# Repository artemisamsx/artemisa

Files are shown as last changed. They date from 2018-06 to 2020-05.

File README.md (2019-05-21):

# Artemisa MSX Computer System

This repository contains documentation and designs for a MSX computer that can be build using discrete components and original integrated circuits, codenamed Artemisa.

This is still work in progress, but you may find some specs and designs in this repository.

## Documentation

* [Artemisa User Manual](doc/user-manual/000-index.md).
* [Artemisa Service Manual](doc/service-manual/000-index.md).

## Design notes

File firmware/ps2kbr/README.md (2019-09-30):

# PS2 Keyboard Adapter Firmware

## Requirements

- A XGecu TL866II+ universal programmer.
- A UNIX-like operating system. It might work in Windows, but that's not tested.

## Dependencies

- Install [arduino-cli](https://github.com/arduino/arduino-cli), the Arduino command line utility to build sketches. You will find install instructions in the project page. At the time of this writing, it was not ported to Homebrew yet, but it was WIP.
- Install [minipro](https://gitlab.com/DavidGriffith/minipro) programming tool. You will have to install from sources (instructions in the project README).
- Install [srecord](http://srecord.sourceforge.net/), a tool to handle ROM images. You can install it with `brew install srecord`.

## Build

There is a Makefile available in this directory. We will start by configuring the toolchain:

```bash
make config
```

This will configure the Arduino CLI and will download the Arduino Uno environment if not done yet.

After this is completed, we can compile with:

```bash
make compile
```

This will generate a `ps2kbr.bin` file that contains the firmware image ready to be flashed in a ATMEGA328P.

## Burn

Put an ATMEGA328P chip in the programmer and let the Makefile do the magic:

```bash
make burn
```

If there are no errors, this will leave the 328 programmed with PS2 Keyboard Adapter firmware.

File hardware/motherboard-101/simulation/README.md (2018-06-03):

The simulation code found here can be executed using the Falstad web simulator:

http://www.falstad.com/circuit/circuitjs.html

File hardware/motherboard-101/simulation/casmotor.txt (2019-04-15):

$ 1 0.000005 8.281975887399955 50 5 50
t 832 352 880 352 0 1 -4.9998037623649285 3.464993523704525e-10 100
g 880 368 880 400 0
r 880 208 880 272 0 160
d 880 272 880 336 2 default-led
R 880 208 880 176 0 0 40 5 0 0 0.5
r 752 352 832 352 0 3300
R 752 352 704 352 0 2 40 2.5 2.5 0 0.5
o 3 64 0 4097 5 0.1 0 2 3 3
o 6 64 3 4098 5 0.1 1 1
o 5 64 0 4097 5 0.00625 2 2 5 3

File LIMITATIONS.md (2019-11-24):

# Artemisa Computer System - Known Limitations

## System

### Game still executes after reset

Artemisa uses static RAM memory technology instead of dynamic RAM. Dynamic RAM was the norm during the 80s due to the expensive cost of static memories. But nowadays are the best option due to the current cost and the fact that they make the memory circuits smaller and simpler.

The main difference between static and dynamic RAM is that the volatility of the former do not depend upong refreshing. Dynamic RAM is based on capacitors whose load determines a logic 0 or 1 value. Capacitors are discharged with the time, and they must be refreshed, charged again to its maximum level with some periodicity. In contrast, static RAM maintains its state as long as power is supplied.

This has a important implication. During a system reset triggered by a reset button press, the reset signal typically stops the refresh actions on the dynamic memory. The human typically would keep the reset button pressed for more than 100ms. That is too much time for the dynamic memory to maintain its bits intact without refresh, and they are typically lost. In other words, this is somehow a memory reset action. In contrast, static memories are not affected by reset signals. And their contents remain intact after system is reset.

Most of the times, you will not even notice it. The MSX system assumes the memory is blank on boot. So the system will init as after power is connected. But from time to time, you will see how the previous software that was running in the computer is runned again. This is caused by that software to be placed in a region of memory the MSX BIOS detects as executable. After reset the program is still there. So the BIOS passes its control to it and causes its code to be executed again.

A well known case of this is the Opera Soft's game Livingstone Supongo. The program is loaded in a memory page such that it contains a header that causes the BIOS to run it again after reset.

There is no simple way to clean up static memories after reset without using complex circuits. If you have this problem, the best thing to do is to cause a hard reset by disconnecting the power and connecting it again.

## PS2 Keyboard

The unexpensive way of using a keyboard in your Artemisa computer is through the PS2 Keyboard Adapter. However, it presents some limitations you should know.

### Key ghosting

Key ghosting is the adverse effect caused by pressing three keys or more simultaneously in your keyboard. When this happens, the keyboard matrix is unable to detect the third key that was pressed. The reason is perfectly described [in this article](https://www.dribin.org/dave/keyboard/one_html/).

During regular keyboard typing, you should not experience any problem. The keyboard matrices use to take into account that the function keys will be used together. So CTRL, ALT, SHIFT, etc, can be combined together with other keys without any problem. However, when keyboard is used as game controller, you will need to press several non-function keys at the same time. This is where problems arise.

Most PC keyboards are very sensible to key ghosting. And there is no solution other than use a different set of keys when you detect ghosting.

A [very well known](https://forum.defold.com/t/spacebar-doesnt-work-when-pressing-up-and-left-solved/12642/3) conflicting combination is `UP` + `LEFT` + `SPACE`. If this happens, you can define keys in your game to use OPQA or WASD instead.

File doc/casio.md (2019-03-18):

## Cassette Input & Output

As most MSX systems, Artemisa provides a interface to load and save programs and data from an audio cassette. Data is backed up at 1200 or 2400 baud with Frequency Shift Keying (FSK) in the standard "Kansas City" format.

The cassette device is connected to the MSX through a 8-pin DIN connector (DIN 45326) with the following pinout:

| Pin | Name | Direction | Description |
| --- | --- | ---- | --- |
| 1 | GND | | Ground |
| 2 | GND | | Ground |
| 3 | GND | | Ground |
| 4 | CMTOUT | | Sound output |
| 5 | CMTIN  | | Sound input |
| 6 | REM+ | | Remote control |
| 7 | REM- | | Remote control |
| 8 | GND | | Ground |

In summary, pins 4 and 5 carry the sound output and input, respectivelly. Pins 6 and 7 are used to start and stop the cassette motor. They are barely used in practice and Artemisa do not use them (these pins are grounded). The rest of pins are connected to ground.

There are two different circuits in Artemisa to generate cassette input and outputs: one that decodes `CMTIN` and another one that encodes `CMTOUT`.

## Cassette Input Decoding

The audio cassette will send an analog signal to the computer with a form of sinusoidal wave through `CMTIN`. The decoding circuit is based on a LM311 part, a voltage comparator, in order to convert the input wave into a 5V squared signal.

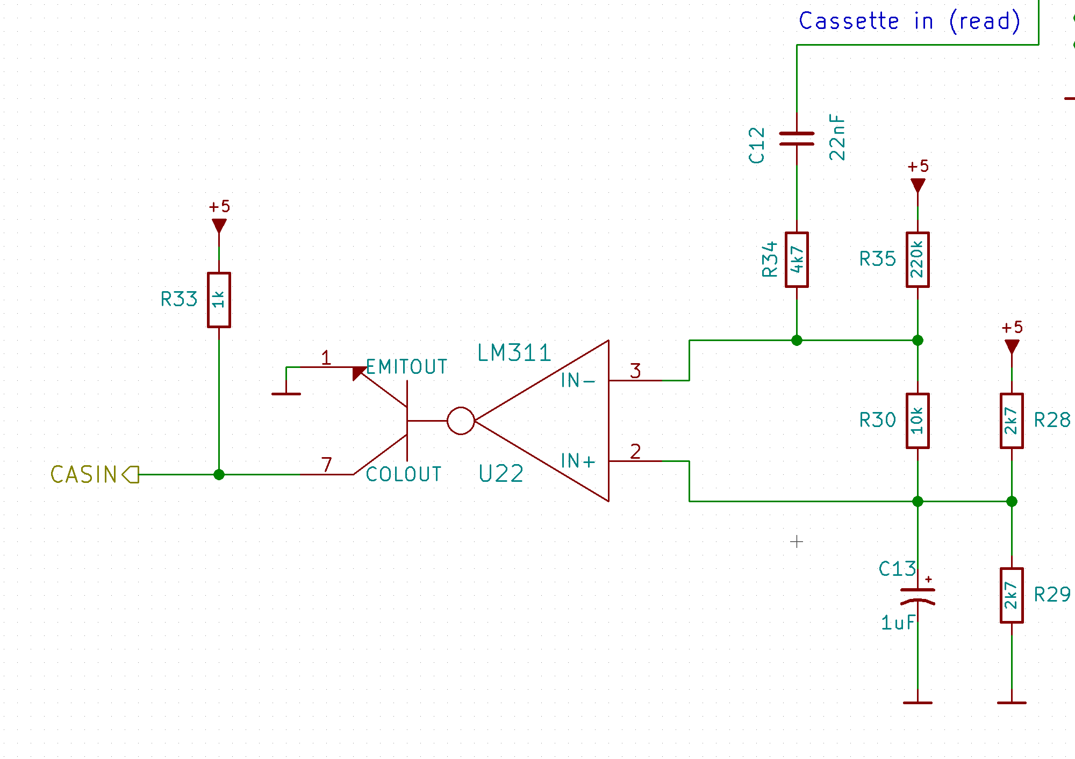
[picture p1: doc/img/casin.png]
casin


What LM311 does is basically open or close its open-collector output based on the voltage levels of `IN+` and `IN-` pads. If `IN+` voltage is greater than `IN-` voltage, the output transistor will not conduct. Thus, thanks to the pull-up resistor R33, the output will be 5V. If `IN+` voltage is less than `IN-` voltage, the output transistor conducts. Thus, the output will be 0 volts sin emiter is connected to ground.

In order to achieve that, the circuit have the following [voltage dividers](https://en.wikipedia.org/wiki/Voltage_divider):
* One made by `R28` and `R29` that feed `IN+`. Both resistors have the same value, so the input to `IN+` is approximately 2.5 volts. 
* One made by `R30` and `R35` on top of `IN+`, that feed `IN-`. The combination of both resistors gives approximately 2.61 volts in `IN-`. 

Since the values of resistors in `IN-` are really large, we might expect to have a very low current coming from `IN+` (<50uA). So `IN+` maintains its voltage intact. `C13` also contributes to counter act the voltage drop from `IN-`, maintaining the potential at 2.5 volts. 

In abscense of voltage coming from `CMTIN`, this circuit will ensure the voltage in `IN-` is slightly greater than `IN+`. Thus, when we receive no signal from the cassette, the digital output will be low. We would read zeroes. 

When a voltage comes from `CMTIN`, it passes through `C12` and `R34`. The capacitor removes the DC offset, and the resistor reduces the amplitude of the waveform. This is especially needed for data recorders that generate signals that exceed the 5 volts peer-to-peek (some do). The analogic signal is combined with the DC value provided by the voltage divider in `IN-`. As result, the low part of the pulse will be below 2.5v barrier. And high part of the pulse will be above it. Thus, the LM311 will generate a squared waveform in `CASIN` that matches the frequency of `CMTIN` line.

## Cassette Output Encoding

The audio cassette will expect an analog signal from the computer with a form of sinusoidal wave through `CMTOUT`. The encoding is implemented by the following RC circuit.

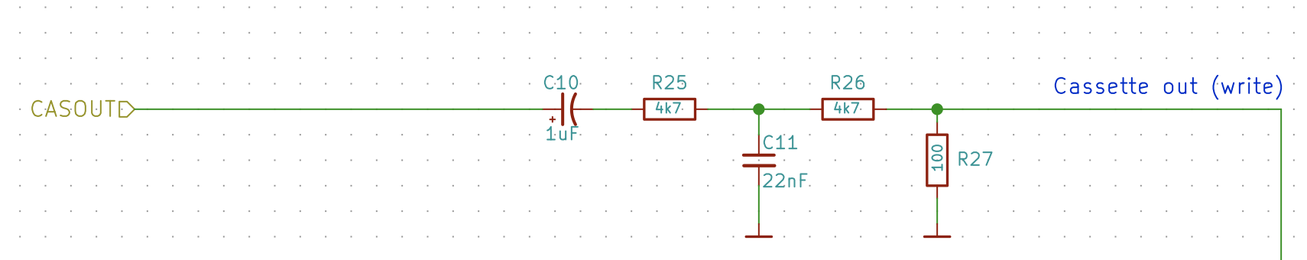
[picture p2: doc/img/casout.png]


The capacitor C10 removes the DC bias from the output signal. The circuit formed by R25 and C11 implements a [RC integrator](https://www.electronics-tutorials.ws/rc/rc-integrator.html) that causes the input squared signal to acquire a pseudo-sinusoidal waveform. Finally, the combination of R26 and R27 acts as a voltage divider that reduces the amplitude of the signal

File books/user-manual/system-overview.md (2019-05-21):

# Artemisa Computer System User Manual - System Overview

## The System

Artemisa is a 8-bits computer powered by a Z80 microprocessor running at 3.58Mhz. This CPU was designed by Zilog in the 70's, as a binary compatible extension of the popular Intel 8080. The Z80 was also used in many other computers and videogame consoles during the 80's, as the ZX Spectrum, the Amstrad CPC, the Coleco Vision or the Sega Master System.

Artemisa is equipped with 64KB of RAM memory. It can be used by programs to store their code, data, and graphics. It also provides 32KB of ROM memory where MSX BIOS and MSX BASIC resides. The MSX BIOS is a collection of software routines used by programmers to make their programs interact with the hardware. The MSX BASIC is a programming language and user environment you can use to code programs and give commands to the computer.

As any other MSX system, there are two major chips that complete the system along the Z80: the VDP and the PSG.

The VDP is the Video Display Processor, an integrated circuit capable of generating a video output for your screen. There were different revisions of the VDP across different generations of MSX. First designs started with a [TMS9918](https://en.wikipedia.org/wiki/Texas_Instruments_TMS9918), a VDP that was already used in Coleco Vision, Sega SG-1000 and some other home computers as the SVI-328. This chip can generate graphics with 256x192 pixels and 16 colors, with hardware-accelarated sprites to make animated graphics. The TMS9918 has a video output limited to NTSC composite video, with synchronization, luminance and crominance all together in a single line. This limitation led the second wave of MSX computers to use the TMS9928 and TMS9929 instead. These VDPs have the same functionality as TMS9918, but they had a component video output that separates the chrominance from the luminance. Thanks to that, the designers can manipulate the video signals to generate the outputs that better fit their needs (composite video, radio-frequence modulation for TV sets, RGB, etc). In addition, the TMS9929 uses PAL encoding instead of NTSC, so they became the right option in most european countries.

Depending on your TV set or monitor, you will have different needs. NTSC vs PAL, composite vs RGB, SCART vs RCA connectors... This customization is really important for the users. That's why Artemisa is designed to support every single option for every single user. This is achieved by separating the VDP and its circuitry from the rest of the computer in a graphics card. This card is connected to the computer mainboard by a ribbon cable. Thus, users can purshase their Artemisa computer by choosing the graphics card that better fits their needs.

Along the VDP, any MSX has a PSG. The PSG is the Programmable Sound Generator, a chip that can generate and play sound and music. Artemisa is equipped with the [AY-3-8910A](https://es.wikipedia.org/wiki/General_Instrument_AY-3-8910). This PSG is also present in the ZX Spectrum and the Amstrad CPC computers. It capable to reproduce 3 different tones with base frequencies of up to 125 kHz.

Using this chip set, and some other circuitry, Artemisa supports several peripherals common in the MSX world.

- A keyboard port that supports keyboards with up to 96 keys.
- Two joystick ports compatible with MSX/Coleco/SEGA devices.
- One datassete port to load or save software from a magnetic tape data storage.
- Two expansion slots to connect cartridges with software or new hardware to expand the computer.

If you are a experienced MSX users, you should know there is a few things you may find in a MSX computer that are not present in Artemisa:

- Printer port. We expect you to do many things with your Artemisa computer. But printing documents is not one of them.
- Serial port. Same reason as for the printer port.
- +12V and -12V power lines. Complicates the design and introduces additional security concerns. Any hardware (cartridge) that depends upon this will not work.

## System Parts

After this introduction to the overall system, you have a high level idea of what you can get from Artemisa. Now it is time to tell you about the different parts that comprise an Artemisa system.

Artemisa is designed to fit your needs as much as possible. There are two parts of the system that are more sensible to customization than the rest:

- The video system. We already discussed a little bit about this. In Artemisa, the VDP and related circuits are separated from the rest of the computer into a separated graphics card. And the graphics card must be connected to an external monitor or a TV. The right option depends on the computer setup you want. See [Graphics card](#graphics-card) section for more details.

- The keyboard. Artemisa is designed to be used with an external keyboard specially designed for it. There are different options for these keyboards depending on the grade of experience you want to obtain and the cost you can afford. See [Keyboard](#keyboard) section for more details.

So in summary, in order to have a full Artemisa computer system, you will need the following parts:

- One Artemisa system base. This includes the motherboard of the computer, the case, the power supply, the cables, the screws and the spacers needed to assemble the computer.
- An Artemisa-compatible keyboard or a keyboard adapter with a suitable external keyboard.
- An Artemisa-compatible graphics card with a suitable external monitor or TV set.

## Graphics card

The graphics card is connected to the mainboard via IDC ports on both boards. A ribbon cable connects the ports. The graphics card is designed to be mounted beside the motherboard, so this internal connection is perfect for the job.

The graphics card port has 50 pins, and it have a pinout similar to those used in the MSX slots. This means the graphics card can behave like a MSX cartridge, mapping its hardware in arbitrary IO ports, or even memory space of the Z80. One of the particularities of this port is that the sound line is "reversed". Instead of connecting a external sound device to the computer, it takes the sound line from the computer to consume it. Thanks to that, the graphics card can produce its own video signal and combine it with the sound signal produced by the computer coming from the motherboard. This might be used to offer outputs that combine video and sound, as SCART connectors.

The following graphics cards are available:

- GFX9918. This is the most basic graphic card available for Artemisa. It is powered by the TMS9918 chip, the first video processor used in a MSX computer. This board generates a NTSC composite video output at 60Hz combined with the sound line via RCA connectors (classic yellow, white and red triad). It includes 16KB of video RAM (VRAM) using static memory.

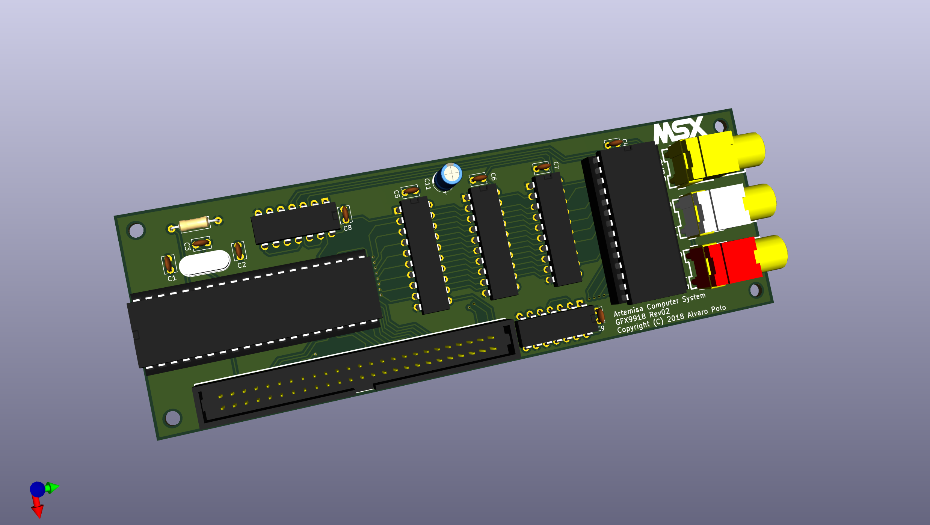
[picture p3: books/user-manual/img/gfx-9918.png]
gfx-9918


- GFX992X (under development). This is an evolution of GFX9918. It uses a TMS9928 or a TMS9929 chip, for NTSC or PAL encoding, respectively. This card has the same graphical features as the GFX9918, but it generates a component video output (YPbPr) instead of composite video. In a few words, the crominance is separated from the luminance in the 9928/9929 chips, what provides a major improvement in the video quality. You can use one chip or the other using the same board, depending on the system used by your TV set or monitor (NTSC or PAL). The board encodes the component video signals to produce RGB+sync. All these outputs plus the sound signal are offered as a female SCART connector you can connect to your TV set via a standard cable.

## Keyboard

Artemisa provides a DB25 connector (classic parallel port, but with custom pinout) in its motherboard to connect an Artemisa compatible keyboard peripheral. This keyboard port basically sends row coordinates of the keyboard matrix to be read, and receives back the status of each column for that row in the matrix. You have different options in order to connect a real keyboard to the computer:

- Use the Artemisa PS2 Keyboard Adapter. This is a separated device that can be connected to the Artemisa keyboard port. It adapts a regular PS2 keyboard and exposes it to Artemisa as a regular keyboard. A unexpensive and simple option, but will affect your user experience negatively since you will have to use a keyboard with a PC key distribution.

- Use the Artemisa USB Keyboard adapter (under development). The same as PS2 adapter, but for USB keyboards.

- Use an Artemisa keyboard (under development). Use a mechanical keyboard designed specifically to be connected to an Artemisa computer, with a real MSX key distribution. For real pro users.

## Case

Artemisa motherboard is distributed with a very simple case comprised by two acrylic plates where motherboard and graphics card can be mounted. The lower plate is opaque white, and it has several holes to screw spacers where the boards stands on. The upper plate is transparent. So you can enjoy looking at the circuits of your favorite MSX computer every time you use it. The upper plate also has special cuts for the cartridge connectors.

## Power supply

The motherboard provides a 2.5/5.5mm DC power jack to connect a 5V, 2A external power supply. As mentioned above, no +12V/-12V power lines are used in Artemisa.

## Next

Now you have a clear general idea about what's Artemisa. Let's see how you can [assemble it from its parts](030-assembly.md).

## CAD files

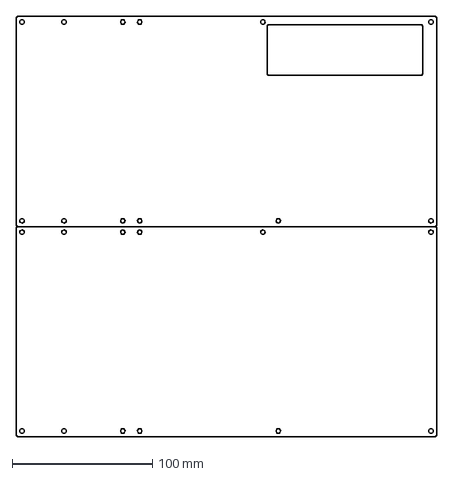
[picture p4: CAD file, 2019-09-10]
cases/motherboard/motherboard.dxf
300.0 x 300.0 mm

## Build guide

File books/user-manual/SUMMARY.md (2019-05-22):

# Summary

* [Introduction](README.md)
* [System Overview](system-overview.md)
* [Assembly](assembly.md)

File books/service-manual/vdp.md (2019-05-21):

# Artemisa MSX Computer System Service Manual - Video Display Processor

Artemisa is designed to allow a variety of different VDPs to be used with it. In order to have this, the VDP circuitry is completely separated from the rest of the computer. So customers can choose the graphics card that better fits their needs.

## Interface

The interface used to communicate the Artemisa computer motherboard and the graphics card is basically a modification of a de facto standard for a expansion bus:

  https://www.msx.org/wiki/Expansion_bus_slots

Artemisa considers the following modifications to the specs described in above link:

* The line 16, which is reserved according to the standard, will be used to transmit the `/VDPIOSEL` signal. This will be active by the computer when IO ports 98h to 9Fh are selected with /IORQ active and /M1 inactive (i.e., a IO request to the VDP ports).
* The line 49, which is `SOUNDIN` according to the standard, will be used to transmit the `SOUNDOUT` signal. In other words, the direction of the line changes. Originally, it goes from the external device to the computer. In Artemisa, it goes from the computer to the external device (the GFX card). The reason to do so is to delegate the sound output connectors to the graphics card. Most GFX card implementation will have video outputs suitable for TV sets. And they typically are accompanied by sound outputs (e.g., RCA connectors for CVBS+sound, SCART connectors, etc). Thanks to `SOUNDOUT`, the video card can provide such video+sound outputs without any external cable.
* As usual in Artemisa, +12v and -12v power signals are disconnected.

Thanks to that, the graphics card can use a great variety of possible IO, and even memory, communications. From the simplest graphic card with a TMS9918 VDP mapped in ports 98h and 99h, to the most sophisticated combination of V9990 chips.

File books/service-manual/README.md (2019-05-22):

# Artemisa Computer System - Service Manual

This is the service manual of the Artemisa Computer System. This manual is for technical stuff to understand how the Artemisa Computer work internally so they can repair it if necessary.

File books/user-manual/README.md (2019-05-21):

# Artemisa Computer System User Manual - Introduction

> "640K ought to be enough for anybody"
>
> Bill Gates, 1981

Welcome to the early days of home computing.

Let me propose you a journey to the 80s of past century. During this decade, the computing industry experienced a big revolution. The lessons learned during the 70s speak about a future in which computers domain everything. A future in which computers are everywhere. Including our homes.

In these days, many companies developed home computers. This is the age of the Spectrum ZX, the Commodore 64, the Amstrad CPC, and of course the big family of MSX. Small machines, with really limited capacity and resources, found their place in many homes when we were just childs. We learned to play videogames with these first computers. We learned to code with them. We learned their potential. Their power to change the modern economies, to transform the society. And we learned all that was just the begining.

Again, welcome to the early days of home computing. Welcome to Artemisa.

## What is Artemisa

Artemisa is a 8-bits computer system that conforms the [MSX-1 specification](https://en.wikipedia.org/wiki/MSX). There were many hardware vendors who produced MSX computers in the 80s. Sony, Canon, Casio, Sharp, Spectravideo, Panasonic, Philips... Artemisa is just another member of this big family, with some particularities:

1) Artemisa was designed in 2018. That's 35 years after the initial design of the first MSX computers.
2) There are some other MSX computers designed in 21st century. But this is one of the few that do not use hardware emulation. Other brands as 1chipMSX or Zemmix use FPGAs to emulate the MSX hardware. In constract, Artemisa use real integrated circuits and discrete logic. In other words, it is made using the same design techniques and materials used in the 80s, when the first MSX computers were also designed. Please note this does not mean Artemisa is better (or worse) than its FPGA-based counterparts. It just mean it is special.

## Audience

Artemisa captures the essence of the homebrew computers of late 70's and early 80's. Do not expect to find a plug&play computer you can connect to your TV set just out of the box. It is distributed in highly customizable parts you will have to assemble by your own (no electronics knowledge is required). Artemisa is a homebrew computer aimed at homebrew consumers.

## Author

Artemisa is designed and implemented by Alvaro Polo. It was created just for fun and delight of its author. Thus, it is offered to the MSX community as a open source project you may find at http://github.com/apoloval/artemisa.

## Next

Let's start your experience with Artemisa by having a look to the [system overview](020-system-overview.md).

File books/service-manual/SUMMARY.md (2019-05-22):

# Summary

- [Video Display Processor](vdp.md)
- [Cassette Input & Output](casio.md)

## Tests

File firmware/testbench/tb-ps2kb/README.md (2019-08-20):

# PS2 Keyboard Adapter Testbench

This testbench can be used to test PS2 Keyboard Adapter boards.

You will need an Arduino Mega/2560 board.

## Arduino Mega pinout

- Pin 2 (out): /VDPSEL (pin 16 of IDC connector)
- Pin 3 (out): /WR (pin 13 of IDC connector)
- Pin 4 (out): /RD (pin 14 of IDC connector)
- Pin 5 (in): /IRQ (pin 8 of IDC connector)
- Pin 6 (out): /RESET (pin 15 of IDC connector)
- Pin 7 (out): A0 (pin 28 of IDC connector)
- Pin A0 (out): D0 (pin 34 of IDC connector)
- Pin A1 (out): D1 (pin 33 of IDC connector)
- Pin A2 (out): D2 (pin 36 of IDC connector)
- Pin A3 (out): D3 (pin 35 of IDC connector)
- Pin A4 (out): D4 (pin 38 of IDC connector)
- Pin A5 (out): D5 (pin 37 of IDC connector)
- Pin 12 (out): D6 (pin 40 of IDC connector)
- Pin 13 (out): D7 (pin 39 of IDC connector)

## How to test the board

Connect the keyboard to the adapter board and wire everything according to the pinout above.

Power up, reset the Arduino, and open the serial monitor in your Arduino IDE. Everything you type in the PS2 keyboard should be seen in the console.

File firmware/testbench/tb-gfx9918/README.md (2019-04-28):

# GFX9918 Testbench

This testbench can be used to test GFX9918 boards.

You will need an Arduino Uno or an Arduino Mega 2560 board or similar to drive the test. The code is written to consider different pinouts for each board.

## Arduino Uno pinout

- Pin 2 (out): /VDPSEL (pin 16 of IDC connector)
- Pin 3 (out): /WR (pin 13 of IDC connector)
- Pin 4 (out): /RD (pin 14 of IDC connector)
- Pin 5 (in): /IRQ (pin 8 of IDC connector)
- Pin 6 (out): /RESET (pin 15 of IDC connector)
- Pin 7 (out): A0 (pin 28 of IDC connector)
- Pin A0 (out): D0 (pin 34 of IDC connector)
- Pin A1 (out): D1 (pin 33 of IDC connector)
- Pin A2 (out): D2 (pin 36 of IDC connector)
- Pin A3 (out): D3 (pin 35 of IDC connector)
- Pin A4 (out): D4 (pin 38 of IDC connector)
- Pin A5 (out): D5 (pin 37 of IDC connector)
- Pin 12 (out): D6 (pin 40 of IDC connector)
- Pin 13 (out): D7 (pin 39 of IDC connector)

## Arduino Mega pinout

- Pin 2 (out): /VDPSEL (pin 16 of IDC connector)
- Pin 3 (out): /WR (pin 13 of IDC connector)
- Pin 4 (out): /RD (pin 14 of IDC connector)
- Pin 5 (in): /IRQ (pin 8 of IDC connector)
- Pin 6 (out): /RESET (pin 15 of IDC connector)
- Pin 7 (out): A0 (pin 28 of IDC connector)
- Pin 22 (out): D0 (pin 34 of IDC connector)
- Pin 23 (out): D1 (pin 33 of IDC connector)
- Pin 24 (out): D2 (pin 36 of IDC connector)
- Pin 25 (out): D3 (pin 35 of IDC connector)
- Pin 26 (out): D4 (pin 38 of IDC connector)
- Pin 27 (out): D5 (pin 37 of IDC connector)
- Pin 28 (out): D6 (pin 40 of IDC connector)
- Pin 29 (out): D7 (pin 39 of IDC connector)

## How to test the board

Connect the wires, including +5V and GND power lines and RCA connectors to a external monitor.

Power up, reset the Arduino, and you must see a message in the screen similar to the welcome any regular MSX1 gives.

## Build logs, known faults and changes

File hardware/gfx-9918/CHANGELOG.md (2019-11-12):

# Artemisa GFX9918 Changelog

## Rev 4

- Fix via sizes to conform JLCPCB design rules
- Fix background color issues by unconnecting EXTVDP pin

## Rev 3

- VCC power traces improved

## Rev 2

- Fix inverted pads of RCA connectors

## Rev 1

First revision of the board

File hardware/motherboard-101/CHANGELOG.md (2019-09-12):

# Artemisa Motherboard Mk.I Changelog

## Rev 3

- Replace 74HCT11 by 74HCT32
- Replace 74HC154 by a pair of 74HC138
- Fix via sizes to conform JLCPCB design rules
- Make the right PCB corners rounded

## Rev 2

- Replace power-on reset circuit to make it work
- Fix wrong orientation of slot connectors
- Fix wrong placement of keyboard and joystick connectors
- Move slot connectors to make room to the case screws
- VCC power traces improved

## Rev 1

First revision of the board

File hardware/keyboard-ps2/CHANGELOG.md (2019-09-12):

# Artemisa PS2 Keyboard Adapter Changelog

## Rev3 (Unreleased)

- Fix via sizes to conform JLCPCB design rules
- Fix wrong dimensions of cartridge slot connectors
- Fix wrong annular ring size of cartridge slot connectors
- Make corners rounded

## Rev2

- Fixed some layout issues found in Rev1.
- VCC power traces improved respect Rev1.
- Added a pair of jumpers to configure keyboard layout.

## Rev1

First revision of the board.

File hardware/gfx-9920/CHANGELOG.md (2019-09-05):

# Artemisa GFX9918 Changelog

## Rev 4 (Unreleased)

- Fix via sizes to conform JLCPCB design rules

## Rev 3

- VCC power traces improved

## Rev 2

- Fix inverted pads of RCA connectors

## Rev 1

First revision of the board

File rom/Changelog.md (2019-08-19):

# Artemisa ROM image changelog

## Version 20190816

Initial version of the ROM image.

### Contents

- `$00000` [jumper conf `0000`]: MSX System v1.0 International
- `$08000` [jumper conf `0001`]: MSX System v1.0 USA
- `$10000` [jumper conf `0010`]: MSX System v1.0 Japan
- `$18000` [jumper conf `0011`]: MSX System v1.0 UK
- `$20000` [jumper conf `0100`]: MSX System v1.0 France
- `$28000` [jumper conf `0101`]: MSX System v1.0 Germany
- `$30000` [jumper conf `0110`]: MSX System v1.0 Italy
- `$38000` [jumper conf `0111`]: MSX System v1.0 Spain
- `$40000` [jumper conf `1000`]: MSX System v1.0 Arabic
- `$48000` [jumper conf `1001`]: MSX System v1.0 Korea
- `$50000` [jumper conf `1010`]: MSX System v1.0 Russia
- `$58000` [jumper conf `1011`]: Artemisa Diagnosis Tool 0.1

### MSX-System flags

```asm
OPTM    EQU     0
NDEVFIX EQU     1
SLOTFIX EQU     0
```

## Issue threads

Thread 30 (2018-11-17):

Test: cassette input signal

apoloval, 2018-11-17:
Mount the following schematic in a protoboard and test whether expected digital signal is successfully detected using a logic analyzer.

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

apoloval, 2018-12-27:
Parts received: unblocked.

apoloval, 2018-12-27:
Bingo! Original circuit, with a operative LM311.

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

apoloval, 2018-12-27:
Note: 470K is too much for R35. That resistor have to raise the medium voltage of the input signal above reference voltage in IN+. As consequence, any minor noise in the line causes the LM311 to detect a drop below Vref, and a digital 1 to be output. A value of 220K raises the voltage a little bit more, and works perfectly. Noise doesn't affect then.

apoloval, 2018-12-27:
Note: 10K is too much for R34. That resistor reduces the amplitude of the input signal. For data recorders, it's fine since they produce a signal of 5Vp-p. But, for regular cassettes (or PC outputs), that's too much since reduces the signal to 784mVp-p at max volume. Using a resistor of 4.7K gives a greater amplitude of 1.13Vp-p. Considering R35 is raising the voltage with some margin, a small amplitude could cause the squared output to be non-symmetrical. To avoid that, R34 could be set to 4.7K instead of 10K.

apoloval, 2018-12-27:
The simplified circuit works fine. But the following amendments are needed:
* R35 is needed to raise the voltage over Vref, so the noise doesn't affect the output as stated in previous note. And its recommended value is 220K.
* R34 is needed in order to reduce the amplitude of input signal. Its recommended value is 4.7K.

That's the input for #40.

Closed 2018-12-27.

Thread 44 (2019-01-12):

Order prototype PCBs for GFX9918 Rev1

apoloval, 2019-01-12:
It's time for rock!

BOM:
- [x] 1x TMS9918
- [x] 1x HM62256ALP-10
- [x] 1x 74HCT04
- [x] 3x 74HCT574
- [x] 1x 74HC32
- [x] 1x Crystal 10.7386Mhz
- [x] 2x Disc capacitor 27pF
- [x] 7x Disc capacitor 100nF
- [x] 1x Radial capacitor 10uF
- [x] 1x Axial resistor 470
- [x] 1x Socket DIP 40 600"
- [x] 1x Socket DIP 28 600
- [x] 1x RCA yellow
- [x] 1x RCA white
- [x] 1x RCA red
- [x] 1x IDC 50p PCB connector male
- [x] 2x IDC 50p ribbon cable female connector
- [x] 1x IDC 50p ribbon cable 5cm

apoloval, 2019-01-12:
PCB printing ordered. Waiting for audit.

apoloval, 2019-01-26:
Socket DIP 28P received.

apoloval, 2019-01-28:
IDC 50p PCB connector male received.
PCBs received.

Closed 2019-01-28.

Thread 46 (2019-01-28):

Test prototype PCBs for GFX9918 Rev1

apoloval, 2019-01-28:
After #44, it's time to test.

apoloval, 2019-03-26:
This is a summary of the experiment carried out.

After soldering the PCB and mounting the components, we realised the RCA footprints were wrong. The pinout was totally inverted, so GND was connected to data, and data to GND. This is reported in #47 .

Apart from this issue, the video quality was really poor. There were some color artifacts and the pixels were not sharply defined.

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

I tested many things to improve it:
- Play with different values for COMVID load resistor
- Try with a emitter follower transistor for COMVID to have almost 0 input impedance.
- Use different combinations of capacitors for VDP clock.
- Use an extra variadic capacitor for VDP clock and adjust it with direct feedback from the screen.
- Replace the crystal by a high-quality one purchased in Mouser

None of that worked. This is the best it can do:

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

I am quite sure the color artifacts are caused by the NTSC encoding in composite video. So there is not much to do here until we find some magic word I cannot find at the moment.

Thus, the experiment is done. Let's produce some units of Rev02 with fixes for detected problems.

Closed 2019-03-26.

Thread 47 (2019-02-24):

[GFX9918] Fix RCA connectors

apoloval, 2019-02-24:
Two major issues of RCA connectors:
- The fingerprint does not match. Even though is possible to solder them, the holes are not in the exact position. Also the holes to fit the capsule are missing.
- The poles are inverted. GND is the central pad, while signal is connected to the left and right ones.

apoloval, 2019-03-24:
Done in d29e0b05a0e1033f2b270c5372d9d8eea220e53c.

Closed 2019-03-24.

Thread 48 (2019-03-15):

CD4069 transits too slowly for clock generation

apoloval, 2019-03-15:
Checking the [datasheet](http://www.ti.com/lit/ds/symlink/cd4069ub.pdf) after some experiments with crystals above 10Mhz, it is clear that the transition of this NOR gate is too slow. 100ns @ 5 volts. This is causing the clock signal to be rounded instead of squared.

It would be great to find some other unbuffered NOR gate that transits quicker and use it for the clock generation.

apoloval, 2019-03-15:
A possible replacement: [TC74HC14AF](https://www.mouser.es/datasheet/2/408/TC74HC14AF_datasheet_en_20120229-1209204.pdf).

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

apoloval, 2019-03-15:
Also have to check [74HC14 Smitt trigger inverter](https://assets.nexperia.com/documents/data-sheet/74HC_HCT14.pdf).

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

apoloval, 2019-03-15:
But in fact, [this StackOverflow thread](https://electronics.stackexchange.com/a/218150) recommends not to use Schmitt trigger inverters for crystal oscillators.

apoloval, 2019-03-15:
The [74HCU04](https://assets.nexperia.com/documents/data-sheet/74HCU04.pdf) also has interesting transition time.

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

apoloval, 2019-03-15:
Just purchased some 74HCU04 to experiment with.

apoloval, 2019-03-25:
Before, with CD4069.

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

After, with 74HCU04.

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

Conclusion: CD4069 must be replaced by 74HCU04.

apoloval, 2019-04-03:
Fixed in 64c3f9b0da03c3a95eb850b6e3c43d8d6e63d2d5.

Closed 2019-04-03.

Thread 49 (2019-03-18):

Rearrange cassette IO circuit to clarify voltage dividers intention

apoloval, 2019-03-18:

apoloval, 2019-03-18:
Fixed in 44e2b9909c577aa055cc3f79d4e5b08cf2b6bd91.

Closed 2019-03-18.

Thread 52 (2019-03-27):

[GFX9918] Produce batch #1 of GFX9918 Rev2

apoloval, 2019-03-27:
After #46, we are ready to produce the first batch of GFX9918.

We will start with 5 units.

Pre-production
- [x] Ensure the PCB is updated and revision number is set
- [x] Generate the Gerber files and submit an order to the factory

Ensure stock of BOM:
- [x] 1x TMS9918
- [x] 1x HM62256ALP-10
- [x] 1x 74HCT04
- [x] 3x 74HCT574
- [x] 1x 74HC32
- [x] 1x Crystal 10.7386Mhz
- [x] 2x Disc capacitor 27pF
- [x] 7x Disc capacitor 100nF
- [x] 1x Radial capacitor 10uF
- [x] 1x Axial resistor 470
- [x] 1x Socket DIP 40 600"
- [x] 1x Socket DIP 28 600
- [x] 1x RCA yellow
- [x] 1x RCA white
- [x] 1x RCA red
- [x] 1x IDC 50p PCB connector male

Post-production
- [x] Prepare kits
- [ ] Assemble and solder the components
- [ ] Test the units using an Arduino board

apoloval, 2019-04-09:
GFX9918 Rev2 [released](https://github.com/apoloval/artemisa/releases/tag/gfx9918-rev2)!

apoloval, 2019-04-09:
Order submitted to the manufacturer. Waiting for audit.

apoloval, 2019-04-09:
Audit passed and payment done. Waiting for manufacturing.

apoloval, 2019-04-30:
Boards arrived yesterday. Ready to soldering and packaging!

apoloval, 2019-05-01:
Kits prepared. Issues:
- 74HCT574: no stocks. 20 units ordered
- 74HCT04: low on stocks. 20 units ordered.
- 27pf ceramic capacitor: low on stocks. 100 units ordered.
- 100nF ceramic capacitor: low on stocks. 500 units ordered.
- 10uF electrolytic capacitor: low on stocks. 60 units ordered.

apoloval, 2019-05-10:
Waiting for 74HC574 to complete the batch. Also for some ESD bags and protection bags that fit better in the box.

apoloval, 2019-10-15:
Already done.

Closed 2019-10-15.

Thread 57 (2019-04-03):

Add a LED for cassette motor status

apoloval, 2019-04-03:
We are not gonna implement the classical relay circuit for cassette motor present in most MSX systems. But a LED that indicates whether the motor is on or not would be really useful.

Please note the LED might not be driven directly from the PPI. The max current could be exceeded. We have to check if the PPI current is enough for a LED (~50mA) and, if not, we should use a transistor switch instead.

apoloval, 2019-04-15:
According to the [datasheet](https://www.renesas.com/eu/en/www/doc/datasheet/82c55a.pdf), max current drive is 2.5mA. This is far from the typical forward current of a LED. We definitely need ty drive it with something else.

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

apoloval, 2019-04-15:
We could use a [ULN2003 IC](https://www.st.com/resource/en/datasheet/uln2004.pdf). This is an array of darlington transistors that can drive 500mA, enough for any LED. But this means adding a new IC to the datasheet. And I'm not sure there is room for it in the PCB.

apoloval, 2019-04-15:
Or more simpler approach: use a voltage follower transistor circuit as this picture shows:

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

apoloval, 2019-04-15:
Done in f77edac23a06cb14b3df45df6b1258b57b6f9d2a by adding a common emitter NPN transistor. According to the simulations, this will drain 1.31mA from the 8255 for a forward current of 19.26mA in the LED.

Closed 2019-04-15.

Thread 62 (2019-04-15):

Extract keyboard matrix emulation out from motherboard

apoloval, 2019-04-15:
The current design assumes the keyboard matrix of the MSX will be emulated by a ATmega328 microcontroller connected to a real PS2 keyboard. The controller would read commands from they PS2 keyboard and would translate them into changes over a keyboard matrix maintained by a network of 595 serial-to-parallel shift registers.

This is fine, and it works. However, having this logic hardcoded into the motherboard means the computer will be forced to use this kind of interface to the keyboard. No custom keyboard will be allowed, as no other interface like USB. This is too rigid.

After a long deliberation, we have decided to move this circuit out from the motherboard. Instead, a DB25 connector expecting a keyboard matrix will be placed. At the other end of the connector, we might have a PS2 adapter, a USB adapter, or just an Artemisa custom mechanic keyboard. We want it as flexible as possible.

Said so. We have to move the keyboard emulation circuit into a separated KiCAD project as we did for the GFX9918 board. We will leave the KBROW decoder, the pull-up resistor network, and we will put a DB25 connector for the rest.

Some proposal for the DB25 connector layout:

- P1 to P8: keyboard column input
- P9 to P19: keyboard row output
- P20: /CAPSLOCK output
- P21: /KANALOCK signal
- P22: /RESET signal
- P23: +5v power supply
- P24 and P25: GND

apoloval, 2019-04-28:
Done in e139e7f3d94a4c002f572750e99f7a35a109f391.

What we did is to extract the matrix emulation circuit to an external board. Also, the whole mainboard of Artemisa was rearranged.

Closed 2019-04-28.

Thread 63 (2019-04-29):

Order prototype PCBs for PS2 Keyboard Adapter Rev1

apoloval, 2019-04-29:
BOM:

- [x] 1x ATmega 328P
- [x] 11x 74HC595
- [x] 1x Crystal 16Mhz
- [x] 2x Disc capacitor 22pF
- [x] 12x Disc capacitor 100nF
- [x] 1x Radial capacitor 10uF
- [x] 1x Socket DIP 28 300"
- [x] 1x PS2 PCB connector
- [x] 1x DB25 PCB female connector

apoloval, 2019-04-29:
PCB printing ordered. Waiting for audit.

apoloval, 2019-05-07:
I forgot to arrange the payment. Just done.

apoloval, 2019-05-20:
PCBs arrived. Pending to check materials stock and assemble the first prototype.

apoloval, 2019-05-26:
Prototype assembled successfully. Now it's time for testing.

Closed 2019-05-26.

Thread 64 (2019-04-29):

Order prototype PCBs for Mainboard Rev1

apoloval, 2019-04-29:
BOM:
- Capacitors
  - [x] 27x Ceramic capacitor 100nF
  - [x] 1x Electrolytic capacitor 100uF
  - [x] 4x Electrolytic capacitor 10uF
  - [x] 3x Ceramic capacitor 22pF
  - [x] 3x Electrolytic capacitor 1uF
  - [x] 2x Ceramic capacitor 22nF
  - [x] 1x Green LED 5mm
  - [x] 1x Red LED 5mm
- Connectors
  - [x] 1x Jack 55x21
  - [x] 1x DB25 male
  - [x] 2x MSX Slot connectors
  - [x] 1x IDC female connector
  - [x] 2x DB9 connectors
  - [x] 1x DIN8 female connector
- Transistors
  - [x] 1x 2N2222 transistor
- Resistors
  - [x] 1x 100Ω resistor
  - [x] 1x 160Ω resistor
  - [x] 1x 220Ω resistor
  - [x] 1x 470Ω resistor
  - [x] 2x 1KΩ resistor
  - [x] 3x 2K7Ω resistor
  - [x] 1x 3K3Ω resistor
  - [x] 4x 4K7Ω resistor
  - [x] 4x 10KΩ resistor
  - [x] 1x 20KΩ resistor
  - [x] 1x 220KΩ resistor
  - [x] 1x 1MΩ resistor
  - [x] 1x 10KΩ resistor network 5p
  - [x] 1x 10KΩ resistor network 7p
  - [x] 2x 10KΩ resistor network 9p
- Integrated circuits
  - [x] 2x HM62256ALP-10
  - [x] 3x 74HCT244
  - [x] 1x Z84C00
  - [x] 2x 74HC74
  - [x] 1x 74HCT245
  - [x] 1x 74HCU04
  - [x] 1x 74HC04
  - [x] 3x 74HC32
  - [x] 1x 74HC08
  - [x] 1x 74HC139
  - [x] 1x 74HC07
  - [x] 1x 74HCT11
  - [x] 1x LM311
  - [x] 1x SST39SF0
  - [x] 1x 74HC154
  - [x] 2x 74HC157
  - [x] 1x AY-3-8910
  - [x] 1x 74HC138
  - [x] 1x 74HC153
  - [x] 1x 82C55
- Sockets
  - [x] 2x DIP 28P .600
  - [x] 1x DIP 32P .600
  - [x] 3x DIP 40P .600
- Oscillators
  - [x] 1x 3.58Mhz crystal

apoloval, 2019-04-29:
Let's do #65 before this.

apoloval, 2019-05-07:
Plotted in 095d7926f36ba0363069efae63f216715b98fdeb.

apoloval, 2019-05-07:
Gerber package [released](https://github.com/apoloval/artemisa/releases/tag/artemisa-mk1-rev01).

apoloval, 2019-05-07:
Order submitted. Pending for audit.

apoloval, 2019-05-07:
Audit completed. Payment done. Waiting for production.

apoloval, 2019-05-08:
In best case, using 5 PCBs would mean we will be low of stock of the following items:
- 62256, 9 units ordered
- 74HCT244, 20 units ordered
- 74HC74, 30 units ordered
- 74HCT245, 10 units ordered
- 74HC04, 30 units ordered
- 74HC32, 30 units ordered
- 74HC08, 30 units ordered
- 74HC139, 20 units ordered
- 74HC07, 10 units ordered
- 74HC157, 20 units ordered
- 82C55, 20 units ordered
- 39SF040, 15 units ordered

apoloval, 2019-05-20:
PCBs arrived. Pending to check the BOM and start the debugging.

apoloval, 2019-06-06:
BOM checked. We have stock of everything, at least to assemble a prototype and test on it.

Closed 2019-06-06.

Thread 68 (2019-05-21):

DB25 connector does not stands out enough

apoloval, 2019-05-21:
The first prototypes arrived reveal the DB25 connectors are not standing out enough. So they could not be connected together without a cable. We must shorten the PCBs so their endings float in the air.

apoloval, 2019-05-22:
It is not only the DB25, but also the DB9. Fixing both.

apoloval, 2019-05-22:
Fixed in a4ac9f86f90f58ec4a69e3df5021acfb54128c00.

Closed 2019-05-22.

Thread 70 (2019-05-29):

Use a jumper to indicate JIS vs ANSI keyboard layout

apoloval, 2019-05-29:
As documented [here](http://map.grauw.nl/articles/keymatrix.php):

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

The register 14 of the PSG corresponds to the IO port A. So the bit 6 is the pin `IOA6` in this schematic:

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

In order to give the opportunity to the users to configure the japanese layout of their keyboards, we should drive this line from the keyboard. We will use the pin 25 of the keyboard connector to transmit the JP layout (1=JIS, 0=ANSI).

The following changes are required:
- [ ] In motherboard, drive the pin 25 from keyboard to the `IOA6` pin of the PSG.
- [ ] In PS2 Adapter, introduce a jumper so the user can select one layout or the other.

apoloval, 2019-05-29:
Another alternative could be to let the keyboard itself to report the kind of keyboard by its own. The pins 24 and 25 of the keyboard connector are GND. Perhaps we could use just one of them for GND and dedicate the other one for transmitting the JIS vs ANSI signal to the computer.

I have to deliberate about this.

apoloval, 2019-05-30:
Yes, I think moving the line to the keyboard makes all the sense. Rewriting the issue...

apoloval, 2019-05-30:
I still have doubts. A quick look to Amazon JP reveals all modern keyboards are JIS, and ANSI is not used anymore. And according to the [docs]:

> It seems the most common computers use JIS, the turboR computers for example, but there are also quite a few which use ANSI.

Perhaps the best choice is to support JIS exclusively. And wire the PSG pin to +5V with a pull-up resistor.

Again, I have to deliberate about it.

apoloval, 2019-06-06:
Yes, I've been searching more and more modern Japanese keyboards. And none of them use ANSI layout. It's much better to consider JIS keyboards only and forget about this issue.

However, we have to wire the PSG pin to 5v+. Reported in #79.

Closed 2019-06-06.

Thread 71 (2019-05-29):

Honour kana lock signal to the keyboard

apoloval, 2019-05-29:
## Description

The pin 21 of the keyboard connector (DB25) is used to transmit the Kana lock signal from the computer to the keyboard. This indicates whether the Kana layer of the keyboard is activated or not. It works in a similar way as the caps lock, but for kana symbols.

In current design, the pin 21 is wired to +5v. It means Kana is never activated.

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

The MSX computer typically [signals the kana lock by bit 7 port IO port B of the PSG](https://www.msx.org/wiki/Joystick_control)(register 15). If we want to honor the kana lock signal managed by the BIOS, we should connect this signal to the keyboard connector instead of pulling it down to ground.

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

## Tasks

- [x] In motherboard, connect the PSG pin to the keyboard connector pin.
- [x] In PS2 keyboard adapter, modify the firmware to use some keyboard LED (as scroll lock) as Kana LED.

apoloval, 2019-07-04:
Fixed for Motherboard in 20e3cf451c80afeeb66313df8c459bb8e607d5ea.

apoloval, 2019-08-20:
Fixed for PS2 adapter in 9ed3c495390dbf08e1394b104af5212bc6b87482.

Closed 2019-08-20.

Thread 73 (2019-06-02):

Motherboard tests: power on, reset and clock generator

apoloval, 2019-06-02:
## Scenarios

- [x] **Power on**
GIVEN barrel DC power circuit is wired
WHEN power is on
THEN the power LED lights up
  AND THEN the ammeter is below 50mA
- [x] **Reset signal**
GIVEN power, reset and clock generator circuits are connected
WHEN power is on
THEN the `/RESET` signal is `LOW`
  AND `RESET` signal is `HIGH`
WHEN ~9ms passes
THEN the `/RESET` signal is `HIGH`
  AND `RESET` signal is `LOW`
- [x] **Clock generator**
GIVEN power, reset and clock generator circuits are connected
WHEN power is on
THEN the oscilloscope reveals the `CLOCK` signal is a squared clock signal at 3.58Mhz

## Connections

- Following barrel DC power circuit is wired

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

- Following reset circuit is wired

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

- Following clock generation circuit is wired (except U17, the flip-flop used to generate `PSGCLK`).

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

apoloval, 2019-06-03:
Issue: C5 and C38 legends overlap.

apoloval, 2019-06-03:
Power on test passed. 0.00 amperes.

apoloval, 2019-06-04:
Reset signal test passed. We expected 9ms as of results from simulation. We obtained ~14ms instead. But it is a good value also. So this is a success.

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

apoloval, 2019-06-04:
Clock generator test passed. Expected frequency and waveform properties are okay.

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

apoloval, 2019-06-04:
All tests in this suite pass. Hurray!

apoloval, 2019-06-05:
Just for the record. I had to assemble a new board, and I used 74HCU04N from Philips instead of 74HCU04AP from Toshiba. With Philips, reset signal period is 9.6ms.

Closed 2019-06-04.

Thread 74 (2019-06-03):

Motherboard tests: PSG clock and PPI ready signal

apoloval, 2019-06-03:
# Scenarios

- [x] **PSG clock generation**
GIVEN power is on
WHEN power is stabilized
THEN the oscilloscope reveals the `PSGCLK` signal is a squared clock signal at 1.79Mhz
- [x] **PPI Ready signal**
GIVEN power is on AND `/PPISL` is HIGH
WHEN power is stabilized
THEN the `/PPIRDY` signal is HIGH
AND WHEN `/PPISL` signal is LOW
THEN the `/PPIRDY` signal is LOW
AND WHEN `/PPISL` signal is HIGH
THEN the `/PPIRDY` signal is LOW

# Connections

- Those coming from test suite #73.
- PSG clock generation circuit is wired

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

- PPI ready circuit is wired. The `/PPISL` signal will not be connected to the PCB, but to a breadboard where we can control its state (LOW or HIGH) using a pull-up resistor and a switch.

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

apoloval, 2019-06-06:
**PSG clock generation** passed:

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

apoloval, 2019-06-06:
**PPI Ready signal** passed.

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

apoloval, 2019-06-06:
Test suite successfully completed.

Closed 2019-06-06.

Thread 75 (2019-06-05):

Motherboard tests: IO port select decoding

apoloval, 2019-06-05:
# Description

Main operation of `U25` binary decoder, used to generate the selection signals for some ranges of IO ports.

# Scenarios

- [x] **No IO operation**
GIVEN `/IORQ` is 1 AND `/M1` is 1 AND `ADDR` is `0b00000xxx`
THEN `/VDPSL` is 1 AND `/PSGSL` is 1 AND `/PPISL` is 1

- [x] **IO operation on unknown port**
GIVEN `/IORQ` is 1 AND `/M1` is 1 AND `ADDR` is `0b00000xxx`
WHEN `/IORQ` is 0 AND `ADDR` is `0b00011xxx`
THEN `/VDPSL` is 1 AND `/PSGSL` is 1 AND `/PPISL` is 1

- [x] **IO operation on VDP port**
GIVEN `/IORQ` is 1 AND `/M1` is 1 AND  `ADDR` is `0b00000xxx`
WHEN `/IORQ` is 0 AND address is `0b10011xxx`
THEN `/VDPSL` is 0 AND `/PSGSL` is 1 AND `/PPISL` is 1

- [x] **Interrupt vector read from VDP port**
GIVEN `/IORQ` is 1 AND `/M1` is 1 AND  `ADDR` is `0b00000xxx`
WHEN `/IORQ` is 0 AND `/M1` is 0 AND address is `0b10011xxx`
THEN `/VDPSL` is 1 AND `/PSGSL` is 1 AND `/PPISL` is 1

# Connections

- Those from the test suite described in #74.
- Connect `U3`, `U4`, and `U5`, the HCT buffers that decouple the CPU signals from the actual buses.
- Connect `U25`, the binary decoder that generates the select signals for IO devices.
- Connect pin 4 to ground or +5V depending on the scenario, which is an equivalent of `ADDR` starting with `10xxxxxx`  or not, respectively.
- Wire address bits as indicated by each scenario. Please note _xxx_ at the end means bits 2, 1 and 0 do not care, and don't need to be wired.
- Wire `/IORQ` selected by scenario
- Wire `/M1` selected by scenario
- Wire any other line from address and control buses to ground and +5v, respectively. This is to avoid floating lines in the buffer ICs.

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

apoloval, 2019-06-07:
**No IO operation** test passed. All control signals to HIGH, all address signals to LOW. IO device selection signals are HIGH.

apoloval, 2019-06-07:
** IO operation on unknown port** test passed.

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

apoloval, 2019-06-07:
**IO operation on VDP port** test passed.

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

apoloval, 2019-06-07:
**Interrupt vector read from VDP port** test passed.

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

apoloval, 2019-06-07:
All tests in this suite passed successfully!

Closed 2019-06-07.

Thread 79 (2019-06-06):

Hardcode JP keyboard layout to JIS

apoloval, 2019-06-06:
## Description

After some analysis in #70, we realised we should be indicating JIS instead of ANSI keyboard in the corresponding PSG port.

## Tasks

- [x] In motherboard, connect PSG pin 15 (`IOA6`) to +5v instead of GND with a pull-up resistor to prevent short-circuits when port is configured as output.

apoloval, 2019-06-20:
Done in 865a480cfd3aad1954f6b8d5e4498aaef9aacdad.

Closed 2019-06-20.

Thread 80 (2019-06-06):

Use custom width for power traces

apoloval, 2019-06-06:
## Description

In Motherboard, we had the caution to assign a custom width for those traces that carry +5v and GND. We should do that same for the rest of PCBs.

## Tasks

- [x] In GFX9918, use custom width for power traces
- [x] In PS2 Keyboard Adapter, use custom width for power traces

apoloval, 2019-07-15:
Fixed for GFX9918 after 142a41fa6ee4c904e553b72c345d422d74134ae1.

apoloval, 2019-07-16:
And fixed for PS2 Keyboard adapter after 8221cb4d2ef67537b6dcd0d4402c6cdf45fbcce8.

Closed 2019-07-16.

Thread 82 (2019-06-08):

Motherboard test: basic CPU operation

apoloval, 2019-06-08:
## Description

Connect the CPU and the ROM memory, and execute a infinite noop loop. The PPI will be hacked to select slot 0 only.

## Scenarios

- **CPU executes the program**
GIVEN ROM memory is burned with [noop loop program](https://github.com/apoloval/artemisa/blob/master/rom/nooploop/nooploop.asm)
WHEN `/M1` is active low
THEN the PC is present in the address bus
WHEN `/MREQ` AND `/RD` are active low
THEN `/WAIT` signal is activated another clock cycle
WHEN `/WAIT` signal is inactive high
THEN data bus contains the instruction
  AND `/MREQ` is inactive high
  AND `/RD` is inactive high
  AND `/M1` is inactive high

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

## Connections

- Those from test #75
- All ICs from Decoding Logic sheet: U10, U11, U12, U13, U14 and U15.
- U7, the flip-flip that generates the `/WAIT` signal.

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

- U8, the bidirectional buffer for data bus.

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

- U18, the AND gate that generates the `/EXTWAIT` and `/EXTINT` signals.

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

- RN2, the resistor network that pull-ups the external wait and interrupt signals.
- Connect pins 2 and 3 of U15 to GND. This would hardcode the slot to 0.

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

- Socket for U20 (ROM).
- Decoupling capacitors for U20 (ROM) and U6 (CPU).

apoloval, 2019-06-08:
Soldering parts...

apoloval, 2019-06-09:
Parts soldered. Also, the infinite noop loop program was added in 0e8eb735c65cd72c24444343997153c5c32e4e0f. Now I have a ROM chip with that program installed. Let's rock...

apoloval, 2019-06-09:
Important record. The `/RESET` signal is not long enough. The ~9ms are not enough for the ICs to be powered up. When reset is deactivated, the clock is still erratic, and some other ICs are still sending glitched values.

I tried to add another 1uF capacitor in paralell to C7, duplicating the capacitance. With that, we are duplicating also the time of the `/RESET` signal. This seems to be enough to stabilize the voltage for all ICs. However, I would use 10uF instead so we are totally sure we are powering it all without surprises.

Reported in #83

apoloval, 2019-06-09:
The results are somehow odd, and need further investigation.

- We start with unusual M1 cycle. I reads from address 0, but `/MREQ` and `/RD` signals are raised too early, in the middle of the second cycle. And the `/WAIT` signal generated for it is ignored.

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

- Then we have what seems to be first fetch of the first instruction. A M1 cycle , again on address 0, that extends to the third clock cycle. This is a `DI` instruction.

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

- Then we have another expected M1 cycle, for address 1, instruction `NOP`.

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

- And finally the last instruction fetch, address 2, a `JR -1`. This doesn't look fine, since the instruction argument is read twice.
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

apoloval, 2019-06-09:
Ups! There was something wrong in the circuit. I forgot to connect pins 2 and 3 of U15 to ground. After fixing that, the first instruction looks fine. A1 to A2 is fetch, B1 to B2 is decoding and execution. 4 cycles for the DI instruction plus 1 wait cycle. Exactly what I expected.

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

Then the execution of the `NOP` at address $0001. Again, as expected. 4 cycles plus one more for the wait in M1.

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

And finally the `JR -1` at address $0002. It has 12 cycles plus one wait, as expected. But still we have two additional read operations from memory instead of the expected single one.

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

apoloval, 2019-06-09:
According to Z80 docs, JR has three M cycles.

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

IO cycle means Internal Operation. And for some reason, it is reading again the operand from memory.

apoloval, 2019-06-09:
Anyway. The program is running apparently without issues, apart from the reset signal problem reported above. The odd initial M1 cycle might be due to a [Z80 special reset](http://www.primrosebank.net/computers/z80/z80_special_reset.htm) that will not affect us since our memory must be volatile. And the double read in `JR e` instruction looks like some internal implementation detail.

I think we can consider this test as complete! Horay!

Closed 2019-06-09.

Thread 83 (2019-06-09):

C7 must be 10uF instead of 1uF in Motherboard

apoloval, 2019-06-09:
The `/RESET` signal is not long enough. The ~9ms are not enough for the ICs to be powered up. When reset is deactivated, the clock is still erratic, and some other ICs are still sending glitched values.

I tried to add another 1uF capacitor in paralell to C7, duplicating the capacitance. With that, we are duplicating also the time of the `/RESET` signal. This seems to be enough to stabilize the voltage for all ICs. However, I would use 10uF instead so we are totally sure we are powering it all without surprises.

apoloval, 2019-06-11:
Just for the record. According to the simulations with Falstad, these are the reset times for each value of C7:

- For 1uF, 50 milliseconds
- For 10uF, 70 milliseconds
- For 47uF, 325 milliseconds

Perhaps 47uF is a better value than 10uF.

apoloval, 2019-06-13:
The whole reset circuit is wrong. This is superseded by #85 .

Closed 2019-06-13.

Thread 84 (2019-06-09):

Motherboard test: exec first stage of Artemisa Diagnosis Tool

apoloval, 2019-06-09:
## Description

Make the CPU execute the first stage of Artemisa Diagnosis Tool. This is the stage in which the VDP is configured in text mode and we are able to show things in the screen. This is actually the setup before executing any diagnosis, which require the PPI to be operative, and we did not assembled it yet.

## Scenarios

- The VDP can be initialized in text mode and we can show messages in the screen.
GIVEN a reduced set of ADT in the ROM AND GFX9918 is connected in video card port
WHEN power is on
THEN the welcome message of ADT can be seen in the screen

## Connections

- Those from #82
- Video card connector is soldered
- Ribbon cable connects the Motherboard with a GFX9918 card via video card connector
- Still pins 2 and 3 of U15 are connected to GND to always select slot 0 on any memory access.

apoloval, 2019-06-10:
Unfortunately, the tests is not successful. Just connecting the items, nothing is seen in the screen. We will have to debug this.

apoloval, 2019-06-11:
Oh, it just was a silly mistake. I forgot to erase the flash memory before burning the ROM image. I fix this and... IT WORKS!

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

But there are some issues. It not works on every boot. Most of them use to fail. Some with a black screen. Some others with unexpected symbols.

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

I suspected again of the `/RESET` signal, so I made an experiment placing a 47uF capacitor in the reset circuit in parallel with the 11uF we already had. No lock. Same behavior. About 33% of the boots succeeds, but the rest 66% fails.

I have to investigate a little more. This is a behaviour we already had with the Arduino testbench. On power-on, the board use to fail. We have to pulse the reset button of the Arduino board to reset everything, and then the VDP works without any problem. [Looking at the code](https://github.com/apoloval/artemisa/blob/master/firmware/testbench/gfx9918/gfx9918.ino#L108-L112) we were using a reset signal of 200uS. That works when power is on before reset, but it is absolutely useless when the board has to be powered up and +5V level must reach every IC, which takes many milliseconds.

apoloval, 2019-06-11:
There is one thing I don't like. After some analysis, I detected the `/RESET` signal is not stable. When it is raising up, the logic analyzer detects level fluctuations. That means the last reset pulse may be too quick, and the VDP gets into an inconsistent state.

One possible reason could be that we are using a 74HCU04, unbuffered inverter. A regular 74HC04 may fix the issue, or even a schmitt triggered one.

apoloval, 2019-06-11:
Tried different options. Different values for C8, make C8 a feedback circuit back to pin 1 of the inverter... Some of them reduce the glitches, but do not eliminate them.

The best option so far is a 74HC14. It eliminates the glitches completely.

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

apoloval, 2019-06-12:
I think I've found the reason for the glitches.

This is the voltage and current curves of the 74HCU04.

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

As with any other CMOS integrated circuit, the consumed current is significantly increased during voltage level switches. So we power on. The capacitor gets loaded slowly until its voltage reaches around 1 volt. At this point, the level switch begins. The output level goes down, and the input starts to consume much more current than before (up to 18mA). This current is pulled from the input... where we have the capacitor. Since there is a 10K resistor between the input and +5v, this current is drained from... the capacitor! So this causes a voltage drop in the capacitor, and therefore in the input. So the level switch is interrupted, or at least reseted to a previous point. More current from the power source loads the capacitor a little more, and we start again. This repeats in a loop, it's an oscillation. And in each iteration we raise the voltage a little bit more. When we are around the high level voltage, we enter and exit from it many many times.

This is something that also happens for 74HC04. The level switch is much faster in this buffered gate, but the current drain increase is the same.

apoloval, 2019-06-12:
I think this reset circuit might work. Have to test it:

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

apoloval, 2019-06-13:
The glitches are deduced drastically with the design above. But they are still present.

However, I tried with this one, which is the one used by the Philips VG8020. It works perfectly. Not a single glitch.

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

But I don't understand yet why.

apoloval, 2019-06-13:
The 4.7k resistor from NPN base to ground is the key. If you remove it, everything is lost. I think it has to do with the region of operation of the transistor. Without this resistor, base current is too high and operates in a sub-optimal region.

apoloval, 2019-06-13:
NICE! I soldered the above circuit in the PCB. And now the reset signal is generated with no glitches at all. And we can confirm that was the reason for the VDP to fail. After this change, the system boots successfully 100% of the times.

For the record, using 11uF we obtain a reset signal of 25ms. With 58uF we have 125ms of reset signal. I'd say we must use at least 47uF.

apoloval, 2019-06-13:
Finally, after fixing the issues in the reset circuit, we may consider this tests as passed succesfully! Horay!

Closed 2019-06-13.

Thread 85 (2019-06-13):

Complete redesign of power-on reset circuit

apoloval, 2019-06-13:
The current design of power-on reset circuit is not invalid. It generates a lot of glitches when the capacitor C7 is loaded, and it causes the VDP to reach an inconsistent state because of them.

This is the proposed design that was tested on #84 and has shown to work perfectly. With just one change: the capacitor should be 47uF instead of 22uF.

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

apoloval, 2019-06-14:
Fixed in b7bcaa8a3aed03b2f3945a3133e0ed454f2099b0.

Closed 2019-06-14.

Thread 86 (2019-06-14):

Motherboard test: RAM memory and PPI slot selection

apoloval, 2019-06-14:
## Description

Connect the PPI and RAM chips, so we can activate the slot 1 and use RAM memory in a ADT test.

## Scenarios

- [ ] System RAM can be accessed in read and write operations
GIVEN the system rom contains a modified version of ADT with only first test step enabled
WHEN power is on
THEN the test runs and tells the RAM works perfectly.

## Connections

- Those from test #82
- Solder U1 and U2, the 62256 RAM chips

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

- Solder U26, the double multiplexer that tells the selected slot
- Solder U27, the PPI

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

- Solder RN1, the pull-up resistor network for keyboard columns.

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

apoloval, 2019-06-18:
Functionally speaking, the test passes. The ADT configures the PPI and the slot layout. And it is able to read from RAM memory.

However, it fails around 80% of executions. Either the screen is blue or black, or weird symbols are shown.

Having a look with the logic analyzer, we detected something really broken. It seems as some `OUT ($99), A` instructions write the value `$99` to the device, instead of the actual value present in the A register. Some example of a failed execution:

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

As you can see, after decoding the first `OUT` instruction, the value written to the IO device is `$99` instead of `$0`, which is what `A` register contains. This is an example of a successfull execution:

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

apoloval, 2019-06-18:
Same test with probes on `/DATADIR` and `/OE` from ROM chip. Both signals are working as expected.

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

So the ROM is not maintaining the data on the bus, as I suspected. I think this CPU unit was damaged in some previous tests and its output buffer is maitaining the value read from the instruction argument fetch.

apoloval, 2019-06-19:
After many debugging with logic analyzer, I detected the problem.

The CPUs I have are inoperative. They are refurbished units from chinese vendors. Out of 9, only one unit works perfectly. I did 24 executions. 100% totally successfull. No artifacts in the screen, no odd behavior. Perfect boot on every reset.

I think I need more Z84C00 units.

Closed 2019-06-19.

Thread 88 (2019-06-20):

Cartridge slots and mounting screws are incompatible

apoloval, 2019-06-20:
Some of the mounting screw holes are in the same place occupied by the cartridge slots. This prevents the screws to be mounted.

We have to rearrange the board, and perhaps extend it, in order to allocate place for screws in the outer edges of the board, out of cartridge space.

apoloval, 2019-07-02:
Fixed in 8c1ba6d8c97367b86bc0501a210cf9792bd9d6cf.

Closed 2019-07-02.

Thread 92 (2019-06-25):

Overall design of GFX9920

apoloval, 2019-06-25:
From existing designs as the attached one, do a basic design to convert the component video output of TMS9928/29 to RGB and/or composite video. From it, identify the different models we will produce. Some examples:

- GFX9920A(RGB output)
- GFX9920B(CVBS output)
- GFX9920C(SCART output)

[TMS9929 RGB Adapter.zip](https://github.com/apoloval/artemisa/files/3324620/TMS9929.RGB.Adapter.zip)

apoloval, 2019-09-19:
Some notes about the investigation.

I cannot interpret the proposed schematic. Things that are not clear to me:
- `Vref` is wired to `Pb` (tagged as `U`) on sync signals. Why?
- `Vref` is undetermined on non-sync signals. `U4D` is open during color transmission. And its output is connected to `U6`, the amplifier that generates `Vref`, without any pull up or down resistor. Thus, the input of `U6` is floating.

I think it will be much better to try with [this other schematic from TI about how to connect TMS9928 to RGB monitors](http://spatula-city.org/~im14u2c/vdp-99xx/e3/SPPA004A_9928-29_9118-28_Interface_to_Monitors.pdf). We can adapt it to use a LM1881 in combination with 4066s to move the color levels to ground on color burst stage. Also, there are some fixes we should apply to the schematic:

- We have to consider the document says `R55` variadic resistor must be set to 4K. It's a typo. It means `R54`.
- For green color generation, the resistor values are not the best. This configuration gives `G = 1.65Y - 0.34R - 0.31B`, far away from the theoretical equation of `G = 1.69Y - 0.5R - 0.18B`. Using `R44=15K` and `R45=12K` we obtain `G = 1.64Y - 0.5R - 0.21B`, much closer and better.

apoloval, 2019-09-19:
About schematic linked in description, I think I have some answers to my questions.

`Vref` is not undetermined during non-sync signals. The capacitor attached to the non-inverting input of the amplifier is there for a reason. During sync signals, the capacitor is charged with the voltage coming from `Pb`. And `Vref` has that very value. When sync signal is over, `U4D` gets open, and the voltage in non-inverting input of U6 is the same we had during sync signal. Since the impedance of U6 inputs is extremely high, the capacitor is discharged very very slowly. So it can maintain the voltage level of `Pb` we had in sync signal during the color transmission phase.

Thus, what the author expected from `Vref` is to maintain the value `Pb` has during sync for all the time.

`U6` amplifier is required to have that. We cannot simply remove it and connect capacitor `C14` to `Vref`. If we would do so, the current demand of `Vref` in the whole circuit would discharge the capacitor quickly. And we would loose the voltage level. The amplifier decouples the impedance, producing a stable `Vref` signal.

apoloval, 2020-06-04:
I have been making some experiments with a MAX4031 and the design we have in c099530525ccdaa5f0d8a3df457993505f70c926. Which is basically the circuit attached in the description. And these are the results:

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

We are very close. What I did not is to remove the backporch sections from the Pb and Pr signals.

During this period, I learned a lot about op-amps. Some important lessons learned:

- Most classic op-amps are designed to have wide power rails. From 12V to -12V, from 5V to -5V, etc. With 5V power supply, a single supply op-amp is required. It is easy to find modern parts that fit. But they use not to have DIP packages.
- Most classic op-amps have a output voltage swing that is prevents the output to be close to the power rails. E.g, a ±12V op-amp use to support output voltages around ±9. Those op-amps that get close to the power rails are called rail-to-rail. Of course, if we use a single supply of 5V, we will need it.
- Bandwidth. Most op-amps indicate this parameter, which usually means the maximum operating frequency for a gain of +1. The gain and the operating frequency are inversely proportional. Thus, if you need a gain of +2, the max operating frequency is divided by 2. Since MSX video has a pixel clock below 5Mhz, and sum amplifiers need a gain of +2, the op-amp must have a bandwidth above 10Mhz.

Considering these requirements, LM318 is not an option. I used the MAX4031 with good results, but this is a SOIC-only part. The [AD8032](https://www.analog.com/media/en/technical-documentation/data-sheets/AD8031_8032.pdf) satisfies the requirements. The big problem is its 5.07€/unit. And we will need at least 2.

I shared this data with the Retrocacharreo community. And this opened a discussion about having a single 5V power supply in the Artemisa. Many expansion hardware for sound generation and processing will not work because they depend on the ±12V power rail. If we consider this requirement, the design would be much simpler. Because LM318 will match the requirements powered by ±12V. Even though, we could use a power pump such as the [MAX870](https://www.maximintegrated.com/en/products/power/charge-pumps/MAX870.html)(available in DIP) to generate a -5V rail, what would make the LM318 suitable again.

apoloval, 2020-06-04:
I just opened a new issue to investigate the introduction of ±12V power rails: #150.

apoloval, 2020-06-04:
Other important considerations. I could understand better the DC restore phase described in the TMS document.

The Y signal is clamped to the voltage level of the sync pulse using a clamping diode. The process is well explained [in the Wikipedia](https://en.wikipedia.org/wiki/Clamper_(electronics)#Positive_biased). The circuit before the anode is there to generate a bias voltage that can be adjusted with a potentiometer.

The Pb and Pr signals cannot be clamped with this technique because it is not assured the lowest voltage corresponds to the sync periods. The paper suggests to use the sync signal separated from Y to clamp using the analog switches. If the analog switch connects GND to the capacitors only during these periods, this will clamp the input signals to the level they have during sync.

After understanding all this, I think trying a different clamping approach is worth it. The clamping diode technique might be not necessary, because the LM1881 is actually giving us the sync pulse and we can use it to clamp with the analog switches are we do with Pb and Pr.

I have to try that in the laboratory.

apoloval, 2020-06-04:
MAX870 is not available in DIP. I think it was a typo in the Maxim DB. The datasheet confirms it is not.

[MAX660](https://datasheets.maximintegrated.com/en/ds/MAX660.pdf) is a similar part. But it is 4.5€/unit. For this price, it is better to keep using the AD8032 with a single 5V power supply.

apoloval, 2020-06-04:
I have been checking the RGB transformation detailed in the TI paper.

The red component is totally okay. We have implemented it in the same way as the paper suggests. All fine.

I have some doubts about the blue component. According to the paper, the VDP divides the B-Y signal by 2. This is the reason to put a resistor in B-Y half of the value of Y while summing for red color. That makes sense. As result, the op-amp would be generating R/3. That's what the paper says. And my calculations confirm it. Thus, the op-amp must be configured with a gain of +3. That's what the paper says. However, the text says the potentiometer must be set to 4K, which results in a gain of +2. This could be another typo in the paper. The point is that the bias resistor must be half of the feedback resistor. In our design, R19 must be 2K4 instead of 5K1.
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
apoloval, 2020-07-17:
Bad news. Only a single 12V rail is not enough. The voltage swing of the LM318 is huge. More or less 2-3V away from the power rails. This means a LM318 powered by 12V-0V only can handle signals above 2-3 volts and below 9-10 volts.

Since the input signal is between 1 and 3 volts, it doesn't work.

I am afraid we will need a voltage inverter to obtain the -12V to get it.

apoloval, 2024-11-17:
I've been having a look at this after a few years.

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

Well, now that the plan is to have +12V/-12V rails and use the LM318 as [the original TI paper ](http://spatula-city.org/~im14u2c/vdp-99xx/e3/SPPA004A_9928-29_9118-28_Interface_to_Monitors.pdf) suggests, I think I should test their design first. The current circuit design is too cumbersome and it's likely overcomplicated.

> Important note. The LM1881 is not able to drive the CSYNC output and feed enough voltage for the CD4066 at the same time.

That's because we are using the CSYNC signal to drive a 4066 to produce the Vref. This signal, however, is not used in the TI's original design. Again: let's see if we can make the TI approach work before.

apoloval, 2024-11-18:
Combining the colors with resistors doesn't sound to work very well. If you have a reference to the circuit, I'd like to have a look at it.

I didn't see that implementation using the 9929. As far as I see, it's similar to the approach suggested by TI in their paper, but using BJT transistors instead of op-amps.

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

I will have a study it carefully later. But as you said, this one uses the LM1881 to produce a Vref signal. And in my experiments, it drops a lot of current from it. So it have to be buffered. If we can get rid of the Vref signal generation, the better.

Cptscorcher, 2024-11-18:
This is the circuit I mentioned and outputs a composite signal. If I get a spare 5 minutes I'll try it out. But yeah not hopeful the quality would be any good.
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
[https://github.com/stefanberndtsson/tms9929-avr](url)

I don't have any LM1881's to try out the ElfCube circuit but looking at the image on their GitHub wiki the quality doesn't look too bad.

Cptscorcher, 2024-11-20:
Oh yes that is nice, I noticed that is what's used with the [https://tms-rgb.com/](url)  board.
I'm only a simple electronic tech so I don't fully understand the problem with the CYSNC - 4066 connection? As far as I can tell the LM1881 can supply the voltage/current for the 4066 which needs 1.5-3.5v and sucks up only 1uA the LM1881 can source/sink up to 1.6mA. Or am I missing something here?

apoloval, 2024-11-20:
> I'm only a simple electronic tech so I don't fully understand the problem with the CYSNC - 4066 connection? As far as I can tell the LM1881 can supply the voltage/current for the 4066 which needs 1.5-3.5v and sucks up only 1uA the LM1881 can source/sink up to 1.6mA. Or am I missing something here?

The problem is not the 4066, but the 1881. Apparently, the CSYNC signal that goes to the TV set drains too much current. So the 1881 cannot keep the expected voltage level of the 4066 inputs. And the interruptor doesn't work as expected.

I know this is something I observed in my oscilloscope, but it was a few years ago and I cannot remember all the details. Maybe the TV set is not well connected. Or maybe those TV sets typically drain a lot of current. I've also seen in the [LMH1251 datasheet](https://www.ti.com/lit/ds/symlink/lmh1251.pdf) how it suggests to use buffers to the VGA connector, as the current is excessive for the IC to drive it without it.

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

apoloval, 2024-11-20:
BTW, the TMS-RGB also have buffered outputs:

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

More precisely, the [THS7374
](https://www.ti.com/product/THS7374), a 4-Ch SDTV (Component and Composite) Video Amplifier with 9.5MHz Filters and 6dB Gain.

apoloval, 2024-11-20:
I am having a look at Mouser and LCSC, and the LM1881 is not available anymore in DIP encapsulation. Only SMD can be found.

I think it's time to try [this circuit based exclusively on BJT transistors](https://www.msxarchive.nl/pub/msx/mirrors/hanso/hwdoityourself/rgbmsx1.pdf):

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

Cptscorcher, 2024-12-12:
Did you have a chance to try the transistor circuit?

apoloval, 2024-12-12:
Nope! Not yet.

Do you bring yourself to try it?

Cptscorcher, 2024-12-17:
No not yet. Got a couple of weeks leave over Christmas coming up soon. This is the last thing to do and then I can see the Artemisa working. Planning to play a lot of Farming Simulator '25 during the break but still hope to have time :)

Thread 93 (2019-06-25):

Motherboard test: PSG integration

apoloval, 2019-06-25:
## Description

Connect the PSG and run a Basic program that reproduces a short theme.

## Scenario

- [x] PSG reproduces a short theme
GIVEN the following Basic program
WHEN program is ran
THEN the theme is reproduced as [in this video](https://www.youtube.com/watch?v=N4DSvK3qS94).

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

## Connections

- [x] Those from #91
- [x] U23, the PSG
- [x] R7, R8 and R9, the resistors from PSG output channels and JP keyboard mode

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

- [x] C29 and C30, the DC removing capacitors for sound channels
- [x] U22 and U24, the 74157s demuxers for joystick ports
- [x] RN3 and RN4, pullup resistors for joystick ports

apoloval, 2019-06-26:
Test passed ([video](https://twitter.com/ArtemisaMSX/status/1143782339857846272?s=20)), with some issues:

- The introduction of the PSG added some additional mA more of power consumption. This caused the power supply to provide less voltage than expected in the input (4.6v), and some devices start to malfunction. I had to regulate the voltage in the power source to 5.3v to have 4.9v in the board. After that, these issues disappeared. I don't know yet if this is caused by the power supply (I hope).

- The system hangs after some commands in Basic. For instance, if we:
  - Introduce line 10 as in the program above
  - Introduce `20 PLAY A$`
  - Execute `RUN`
  - The program works and it sounds as expected.
  - Introduce `30 END`
  - The system hangs

The good news are that this is caused by the MSX System ROM I am using. I can reproduce it in OpenMSX, exactly the same steps and the same results. So it is a software issue, the hardware seems to be okay.

I tried with a different system ROM by enabling the `NDEVFIX`. No luck, same results in the emulator. I still have to figure out why the MSX system is not working.

apoloval, 2019-06-27:
Bug #94 fixed. Everything works as expected.

Closed 2019-06-27.

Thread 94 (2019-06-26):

MSX system hangs on PSG manipulation

apoloval, 2019-06-26:
Some hangs of the MSX system detected during #93.

How to reproduce it:

- Execute these statements in MSX Basic:
```
10 A$="t100l8o4gbo5d4o4go5ce4"
20 PLAY A$
RUN
30 END
```
- The system hangs

This does not work both in the Artemisa and in OpenMSX emulator.

apoloval, 2019-06-27:
Launching the debugger in OpenMSX I realized the hang is caused by configuring slot 0 (ROM) for page 3. This page is RAM, and must be RAM all the time. Otherwise, we would loose the Basic working area, the stack, etc. This is a failure, indeed.

The following stack trace can be obtained from the debugger.
```
RDPRIM  $F380
RDSLT   $000C
  BIOS call: read from slot
  Args:
    HL (address to read): $C006
    A (slot selection): $00 (primary 0, secondary 0)
C7E1A   $7E1A
  Subroutine: read word from extension ROM
  Args:
    HL (address): $C006
    C (slot ID): $00
  Calls RDSLT from $7E21
J564A   $564A
  Subroutine:  i/o function dispatcher for expansion ROM
  Calls C7E2D to translate SLTATR entrynumber to address and slotid
  Calls C7E1A from $5657
C6F8F    $6F8F
  Subroutine:  i/o function dispatcher
  Jumps to J564A if i/o channel device is not a internal device
```

In summary, it seems we have a problem in this code:
```asm
C6F8F:  CALL    H.GEND
        PUSH    HL
        PUSH    DE
        PUSH    AF
        LD      DE,4
        ADD     HL,DE
        LD      A,(HL)
        CP      0FCH                    ; i/o channel device a internal device ?
        JP      C,J564A                 ; nope, start i/o function in expansion ROM
```

apoloval, 2019-06-27:
Finally I tried with a different approach. Check the differences in the hex dumps between our ROM image and the SVI-728 ROM. Byte after byte, I detected and fixed [this problem with a constant wrongly generated by Pasmo](https://github.com/apoloval/msx-system/commit/78b00d22906773738e3d6f114ece3b7f4ac67214). Once fixed, the bug is no longer reproduced in OpenMSX.

Leaving this issue opened until we test in a real Artemisa machine.

apoloval, 2019-06-27:
Successfully tested in Artemisa.

Closed 2019-06-27.

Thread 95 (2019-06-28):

Motherboard test: datasette reading

apoloval, 2019-06-28:
## Description

Load software from the datasette interface.

## Scenarios
- [x] Software can be loaded from datasette
GIVEN Colt36 is inserted in the tape and rewinded
WHEN `LOAD "CAS:",R` is executed in MSX BASIC
THEN the game loads and executes as expected

## Connections

- Those from #93
- [x] J8, the datasette connector
- [x] C23 and C34, capacitors from cassette input signal processing
- [x] R16, R17, R18, R19, R20 and R21, resistors from cassette input signal processing
- [x] U19, LM311 voltage comparator

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

- [x] R20 and R21, the resistors of CAS motor on LED
- [x] D2, the CAS motor on LED
- [x] Q1, the CAS motor on transistor

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

apoloval, 2019-06-29:
Test passed successfully! See [this video](https://twitter.com/ArtemisaMSX/status/1144999233906466816?s=20)!

Closed 2019-06-29.

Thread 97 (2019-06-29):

Motherboard test: slot connectors

apoloval, 2019-06-29:
## Description

Test slot connectors with some ROM based software.

## Scenarios

- [x] Run a game from cartridge slot A
GIVEN power is off AND
   Knight Night is inserted in the cartridge slot A
WHEN power is on
THEN the game loads

- [x] Run a game from cartridge slot B
GIVEN power is off AND
   Knight Night is inserted in the cartridge slot B
WHEN power is on
THEN the game loads

## Connections

- Those from #96
- J3 and J4, cartridge slots

apoloval, 2019-06-29:
Initial test: not passed. The system does not even init.

Have to investigate why.

apoloval, 2019-06-30:
I find out why the slots do not work. They are reversed. We consider the first pin is the one at front-left. Wrong. That's the last pin, 50. The first pin is the one on back-left.

apoloval, 2019-06-30:
Bug reported in #98.

The slots are wrongly placed, but the design is correct. The system can read from slot memory space successfully. Thus, the test is considered as a success.

Closed 2019-06-30.

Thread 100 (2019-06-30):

Replace cas motor LED by an actual relay

apoloval, 2019-06-30:
First experiences with CAS reveals the LED that indicates the motor is on is not a good fit. Having a relay will be better, and the cost in terms of design and parts will not be big.

And consider this: the CAS motor has inverse logic. 1 means motor off, 0 means motor on.

apoloval, 2019-07-01:
I acquired a [Songle SRD-5VDC-SL-C relay device](http://www.circuitbasics.com/wp-content/uploads/2015/11/SRD-05VDC-SL-C-Datasheet.pdf). Not sure if it is small enough, but...

apoloval, 2019-07-02:
Tested the Songle relay. For the record:

- I had doubts about what is the normal configuration of the REM signal: normally open (NO) or normally closed (NC). This is because I wanted to understand how the datasette detects the REM cable is connected or not. I tested this with my SVI-728 and a multimeter. With motor off, the REM cable is open. With motor on, it is closed. I had the feeling that the datasette considered the other way around, so motor off and cable not connected are the same (circuit open). But I was wrong. The datasette detects the REM connector is inserted somehow (I don't know how). And once inserted, with circuit open, the motor is off. Once circuit closes, the motor turns on.
- The relay consumes 80mA when active. It matches the datasheet (89.3mA). So we will need a transistor to drive it.
- The relay switch impedance is around 1Ω.

apoloval, 2019-07-03:
Done in f8ae546646b58e40dd7b4faef9543ae61d816944. But still have to be tested.

apoloval, 2019-07-03:
Circuit to test:

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

apoloval, 2019-07-03:
The proposed circuit is wrong. Issues:

- The transistor have to be a PNP instead of NPN. A 2N2907 matches. See [this guide](https://www.electronics-tutorials.ws/blog/relay-switch-circuit.html).
- The resistor is too big. It was fine for 2N2222, but not for 2N2907. I think hFE is too small. We can use a 1K Ohm resistor, or adjust by calculating with the datasheet.
- The relay activates and deactivates on power on. Something to investigate, perhaps we can avoid that.

apoloval, 2019-07-03:
Tested with a resistor of 2.2K Ohms. It works.

apoloval, 2019-07-04:
Issues addressed in cf2da4687cccba9a5aab3c766793d78a7e0a1970.

Done!

Closed 2019-07-04.

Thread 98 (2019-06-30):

Slot connectors are reversed

apoloval, 2019-06-30:
As detected in #97, the slot connectors are placed in the reverse direction. The first pin is the one at top-right corner of the footprint. But we had place it in the bottom-left corner.

apoloval, 2019-07-02:
Fixed in 8c1ba6d8c97367b86bc0501a210cf9792bd9d6cf.

Closed 2019-07-02.

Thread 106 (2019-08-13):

C7 (power-on reset) value is too low

apoloval, 2019-08-13:
47uF is too low for this capacitor that controls the width of the `/RESET` signal. In the Rev02, this value gives around 50ms. That is not enough for the `CLOCK` signal to stabilize. And that causes a complete boot failure.

Increasing the value to 100uF produces a `/RESET` pulse of 100ms. `CLOCK` is stabilized around 50ms after power on, so we have a security margin of 50ms.

apoloval, 2019-08-14:
Fixed in 9770ec55ed3bc29b94248399b8e61327fe00e870.

Closed 2019-08-14.

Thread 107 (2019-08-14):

Vias for power tracks are too small

apoloval, 2019-08-14:
This is something that is more obvious when you have the real PCB in front of your eyes. The via is even smaller than the track width.

apoloval, 2019-09-04:
I double-checked this issue. The vias are not really small. Closing with no fix.

Closed 2019-09-04.

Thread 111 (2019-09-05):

Adapt board settings to JLCPCB capabilities

apoloval, 2019-09-05:
Trying JLCPCB as PCB manufacturing vendor. Must adapt the boards to their settings:

- Min. Trace: 5mil
- Min. Spacing: 5mil
- Min. Via To Trace (same as trace spacing in Kicad): 5mil
- Min. Via hole size: 0.3mm
- Min. Via diameter: 0.6mm
- Annular Ring: 3mil

So the following settings are suggested:
- Default net track width: 8mils
- Default net clearance: 8mils
- Default net via drill: 0.3mm
- Default net via size: 0.6mm
- Power net track width: 20mils
- Power net clearance: 10mils
- Power net via drill: 0.5mm
- Power net via size: 1.0mm

Set this for:
- [x] Motherboard
- [x] GFX9918
- [x] PS2 Adapter

apoloval, 2019-09-05:
Boards fixed in 74f04240c4a5cfd6187a39037745498d23b6fe55.

Closed 2019-10-15.

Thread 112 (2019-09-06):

Provide CAD designs for PS2 Keyboard case

apoloval, 2019-09-06:
We will start with a simple case: two boards of acrylic with holes for the screws.

apoloval, 2019-09-10:
Fixed in b82f8eee6fd262acdcafd8b15fce3b7874cf0390.

Closed 2019-09-10.

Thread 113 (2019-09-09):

Dimensions of MSX cartridge slots are wrong

apoloval, 2019-09-09:
The available information about MSX cartridges is not quite accurate:

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

It is not really clear from this specs what's the width of the cartridge. But, from measurements of real cartridges, it seems to be 17.1mm. So... the dimensions and probably the placement of the slots is wrong.

apoloval, 2019-09-09:
I think I've found a better specification in the Technical Data Book.

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

We have to satisfy these dimensions in the PCB layout.

apoloval, 2019-09-10:
Fixed in 878a529052244729f3febe1808487937dc86d772!

Closed 2019-09-10.

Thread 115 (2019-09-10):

Provide CAD designs for Motherboard case

apoloval, 2019-09-10:
We will start with a simple case: two boards of acrylic with holes for the screws and an opening for the cartridge slots.

apoloval, 2019-09-10:
Done in 0f15f1e1d1dd15b5d795a4f8c1a509f5ce1c40ec.

Closed 2019-09-10.

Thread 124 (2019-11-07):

External VDP must not be connected to GND

apoloval, 2019-11-07:
After many tests, several hours in front of the oscilloscope, we have found out that we cannot connect external VDP input to ground. This is causing a very subtle problem when VDP is configured in screen 2 with borders in transparent color. The following Basic program can be used to reproduce the problem:

```basic
10 SCREEN 2
20 VDP(7)=0
30 A$=INKEY$
40 IF A$="" THEN 30
```

The line 20 just sets the frame border color to 0 (transparent). This causes a distortion in the CVBS signar that some TV sets cannot recover from. Some games use to left the frame border color as transparent, since it should be a fallback to black according to the datasheet. Arkanoid is one of them. Running these games caused the synchronization signal to be lost.

The solution is to leave EXTVDP signal unconnected.

apoloval, 2019-11-11:
Fixed in c5b833b742c23c2ca5edafb00c0926f8561686bb.

Closed 2019-11-11.

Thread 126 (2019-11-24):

Detect keyboard disconnections and reset upon reconnect

apoloval, 2019-11-24:
In theory, we could disconnect the PS2 keyboard with the computer running. But it would reset and will reach an initial state, and not the state the computer has. This means the status of the LEDs will be inconsistent.

This can be prevented by just sending some periodic pings to the keyboard to detect whether it is connected. With this we can detect if the keyboard have been just connected, and send the initial state we need.

apoloval, 2019-12-09:
The suggested solution could be overcomplicated. When PS2 keyboard is connected, it sends a `0xAA` scancode by its own. This indicates the self-test passed after a reset command (`0xEE`) or after power on. We could use this command to infer the keyboard has been reconnected, and send the LED state at that point.

apoloval, 2019-12-09:
A really interesting resource: the [Renesas manual to write microcontroller programs for PS2 devices](https://www.renesas.com/us/en/doc/products/mpumcu/apn/003/reu05b0121_h8s2100ap.pdf).

apoloval, 2019-12-09:
We finally got inspired by Renesas paper and reimplemented the things assuming only one scancode can be received at a time. This simplifies the code a lot.

Also, we had fixed the reconnect issue by detecting the `0xAA` command and sending again the LED status when that happens.

Merged in d691fd4477466710cbf09543a2859a187c237f5a.

Closed 2019-12-09.

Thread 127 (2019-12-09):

Prototype PS2 keyboard adapter fails

apoloval, 2019-12-09:
The prototype unit of PS2 Keyboard Adapter I use for the tests use to fail.

It starts responding normally. But after a while, some random keys are detected as pressed. I think this may be caused by the board itself. It seems some 595s are not working as expected and they show pressed keys that have not been reported by the microcontroller.

In fact, I could not reproduce this behavior in the Arduino board. That's why I think it is an issue with the 595s matrix.

I would be useful to test other boards to confirm they work well with the latest version of the firmware.

apoloval, 2020-01-07:
Tested in another board. And the bug was reproduced with the latest firmware version. Using the old one works perfectly.

It seems there is a bug in the firmware that is causing this malfunction.

apoloval, 2020-01-15:
I debugged the board connected to the MSX with the serial monitor connected via Arduino board.

It seems the root cause is that the new ps2 lib implementation assumes the keyboard communication can be inhibited at any time. We are receiving 0x00 bytes from the keyboard. This usually means an error due to buffer overrun in the keyboard size. And it makes sense.

When a scancode is received from the keyboard, it is stored in a variable (1-byte buffer). Then the PS2 communication is inhibited. When that scancode is read from the firmware, the PS2 port is marked as idle again, allowing the keyboard to send more bytes.

If the firmware takes too much time to read the buffered scancode, the keyboard may need to send some bytes, but it cannot due to inhibited comms. It could happen that further keystrokes are ignored by the keyboard, because they cannot be transferred to the controller.

The solution is to implement an input buffer in the controller so the keyboard can transmit bytes when it have. Without inhibiting.

apoloval, 2020-03-25:
Okay, we finally reached an implementation that works!

Fixed in 5d728e53001c5bd1865f94ccfc06102dfc550c43.

Closed 2020-03-25.

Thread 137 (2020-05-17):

Use an oscillator instead of a crystal circuit

apoloval, 2020-05-17:
A completely encapsulated oscillator is better, smaller, and cheaper.

[This part](https://www.mouser.es/ProductDetail/ECS/ECS-100AX-035) will make it.

apoloval, 2020-05-19:
I think the original part, ECS-100X will not work. It just generates 2.4V output. Good for TTL, bad for CMOS. Apart from that, it is through-hole.

This another one, the [SG7050CCN](https://www5.epsondevice.com/en/products/crystal_oscillator/sg7050ccn.html) looks better. Real 5V operation. And SMD.

apoloval, 2020-05-19:
Done in d668515fb430341e3baf9f7e92a00fc07b2d3ffa.

Closed 2020-05-19.

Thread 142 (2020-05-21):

Write GAL equations for decoding logic

apoloval, 2020-05-21:
We to replace most of AND, OR and NOT gates by a single 22V10 GAL.

The goal of this issue is to have a method to describe the logic equations and generate the JEDEC files from it. The alternatives are:

- Use WinCUPL. The official method recommended by Atmel. Only Windows, ancient tool, plenty of bugs.
- Use [GALasm](https://github.com/daveho/GALasm). Community tool, poor documentation, really uncertain.

apoloval, 2020-05-21:
Finally I used GALasm tool. I found a bug, fixed and submitted [the corresponding PR](https://github.com/daveho/GALasm/pull/6). Apart from that, it looks promising.

All the logic found in the decoding sheet has been implemented, with the following exceptions or particularities:

- `/CS1`, `/CS2` and `/CS12` are generated by the GAL. The decoder U15B is no longer needed.
- The equations of PSG selection signals have been simplified. In this version we use more product terms instead of reusing `PSGBDIR` in `PSGBC1`.
- The decoder U26 is still used to generate the select signals for peripherals. In order to remove U10D and U13A gates, the enable inputs of the decoder has been altered. A new signal `/IOSL` is generated by the GAL, indicating an IO operation is requested. This excludes the activations of `/IORQ` for vectors and instructions in interrupt modes 0 and 2. This signal can be directly connected to the selection of U26, along A7 and A6 to generate IO select signals for specific devices.
- The `/PPIRDY` signal is still produced by U17B. There are no enough outputs for it in the GAL.

Done in 26440c6caba0170a7820a9408d4b950223edcfe9.

apoloval, 2020-05-22:
Leaving this issue as pending because I want to test whether the code from GALasm works or not.

apoloval, 2020-05-27:
GAL logic tested. Several equations has been checked and they work as expected. Awesome!!!

Closed 2020-05-27.

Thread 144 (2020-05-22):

Research how to provide a PS2 keyboard interface based on 74670

apoloval, 2020-05-22:
Model 201 would have the PS2 keyboard integrated in the board. 211 might have an integrated keyboard.

The array of 11 74595s seems not to be the best option in this particular case.

Looking around, I realised the existence of [register file](https://en.wikipedia.org/wiki/Register_file) ICs: integrated circuits that contain several addressable registers that typically can be accessed with dual ports.

The best choice of register files seems to be the [74HC670](https://www.ti.com/lit/ds/symlink/cd74hc670.pdf). This is a 4x 4-bit registers, with separated ports for reading and writing.

If 74HC670 is used, we will need a pair of ICs to cover 4 full keyboard rows. To cover at least 11 rows, we need 6 ICs. This is almost half of those used in the original design of the PS2 Keyboard Adapter.

We could investigate a little more for other parts, but I could not find something better except things not in production today. The [DS1690](https://datasheets.maximintegrated.com/en/ds/DS1609.pdf) is a perfect fit. 256 bytes, dual port. A single chip would do the job. But it is an obsolete part and no other replacement is offered.

apoloval, 2020-05-22:
Thinking about that... It could be possible that we do not even need any interface. The ATMega328 could be enough.

Let's say we connect the PD port (8 bits) of the Mega to the PPI port B where keyboard columns must be received. The port PC (7 bits) is connected to the low nibble of the PPI port C where keyboard row is selected. The `/PPIWR` signal is connected to some pin of the Mega to trigger an interrupt.

The point is that the Mega changes PD with the contents of the keyboard row indicated by PC on every raise edge of `/PPIWR`. The write operation on the PPI might not be for port C, but we do not care. There is no effect on updating when keyboard row is not modified.

The Z80 can change the selected keyboard row by writing in C port of the PPI. This requires an OUT instruction. After that, if it wants to read the keyboard columns, another IN instruction is required.

In the best case, an `IN`and `OUT` instructions take 11 cycles. 12 cycles in case of MSX due to the additional wait cycle. With a CPU clock of 3.58Mhz, this is 3.35uS. This is the time we have for the ATMega328 to execute the interrupt handler.

I think 3.35uS could be enough time for an ATMega328 at 16Mhz to read one port, fetch an array item, and write it to another port. I have to check the ASM specs of the microcontroller to confirm this.

apoloval, 2020-05-22:
As I read in the [ATMega328 datasheet](http://ww1.microchip.com/downloads/en/DeviceDoc/Atmel-7810-Automotive-Microcontrollers-ATmega328P_Datasheet.pdf), most instructiosn take 1 clock cycle:

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

Also, the interruption responds in no less than 4 cycles:

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

IN and OUT operations take 1 cycle:

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

And load indirect operations take 2 cycles.

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

In summary, it sounds we could update the keyboard columns in something more than 8 cycles. At 16Mhz, this is 0.5uS.

This is something we have to experiment. An Arduino Uno, a testing sketch and a logic analyzer. And see how much time it takes to perform what we expect from it.

apoloval, 2020-05-23:
This doesn't look well:

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

Interrupt handler is just:
```
void interrupt_handler() {
  PORTC = rows[index];
  index++;
}
```

apoloval, 2020-05-23:
Surprisingly, using assembler code is even slower. From 12us to 17us:

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

The code:
```
void interrupt_handler() {
  asm volatile(
    "OUT %[port], %[data] \n\t"
    ::
    [port]      "I" (_SFR_IO_ADDR(PORTC)),
    [data]      "r" (index)
  );

  index++;
}
```

apoloval, 2020-05-23:
Just in case the logic analyzer is not good enough and is showing bad results, I double checked with the oscilloscope. Same results:

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

apoloval, 2020-05-23:
Well. There was several wrong things in the experiment.

First, I was configuring the ports direction wrongly. However, this causes the signal to be written at the output, but with a sort of capacitor-load effect.

Secondly, using a mechanical switch to simulate the `/PPIWR` pulses doesn't work. It seems to have a very high capacitance, and the signals takes several microseconds to raise. I replaced the switch by a digital output from the Arduino board. A pulse is produced every second, and it is externally connected to the port where external interrupt is configured.

After fixing both things, this is what the oscilloscope shows:

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

The value can be updated 2.4uS after the raise of `/PPIWR`.

These are great news, because we are below the 3.35uS limit. But there are still some other considerations. One of them, that the ATMega328 could be running an interruption from the PS2 port when `/PPIWR` is asserted. If that happens, we should interrupt the PS2 interruption. And this is risky.

apoloval, 2020-05-23:
BTW, this is a [complete guide of interrupts in Arduino](http://www.gammon.com.au/interrupts).

It tells a very interesting fact. The ISR requires 1.43uS to save the context in the stack. Makes sense and matches the observed delays.

apoloval, 2020-05-23:
Another interesting observation. Using `attachInterrupt()` instead of direct ISR declaration increases the delay from 2.0uS to 3.6uS.

The guide linked above explains the reason. This method does not bind the function as ISR, but uses its own and keeps the function passed as argument in a table. It has to lookup to find it and then call it. A that takes more time.

apoloval, 2020-05-24:
I wonder that is the propagation delay from `/PPIWR` to PPI port C data lines. Because if it is significant, it might compromise the system if just ATMega is used.

This is it. Yello is `/PPIWR`, blue is PPI port C data 0:

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

Less than 40ns. Not significant. We might use either the `/PPIWR` or the port C data lines as interrupt indistinctly.

apoloval, 2020-05-24:
BTW, this is the confirmation that the keyboard row write is followed by a column read after 3.35uS:

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

apoloval, 2020-05-24:
I am afraid I bring more problems to the table.

This is the pinout of the ATMega328/Arduino Uno:

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

As we can see, there is just one por with 8-bits fully available: Port D. Port C is 7-bit, with one bit assigned to the `/RESET` signal. Port B has 8-bits, but two of them are used for the oscillator inputs.

The bad news is that Port D cannot be used as keyboard column data bus. Because the interrupt pins are placed there. And we need at least one of them for PS2 interruptions.

The alternative would be to separate the column data bus in two nibbles. For example using PORTB for the lower 4-bits and PORTC for the upper 4-bits. This is the timing diagram of this. Yellow is `/PPIWR`, blue is the last bit to be updated:

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

4.8 fucking microseconds. Far above the 3.35uS limit.

apoloval, 2020-05-25:
I've been investigating about implementing the ISR in pure assembler instead of C/C++. In order to avoid innecesary context saving and reduce the number of instructions executed before the actual code.

Using Atmel Studio, I could have a look to the output listing of a raw C ISR declaration. It looks like:

```
ISR(INT0_vect) {
  80:	1f 92       	push	r1
  82:	0f 92       	push	r0
  84:	0f b6       	in	r0, 0x3f	; 63
  86:	0f 92       	push	r0
  88:	11 24       	eor	r1, r1
  8a:	8f 93       	push	r24
	PORTB = 42;
  8c:	8a e2       	ldi	r24, 0x2A	; 42
  8e:	85 b9       	out	0x05, r24	; 5
}
```

As we can see, the prelude is the same described in [the Gammon guide](http://www.gammon.com.au/interrupts). But the last pushes before the actual code of the ISR. I see they are not fixed, but depend on the registers used in the ISR code. In this case, only R24 is used. So this is the only register saved. Makes sense.

The rest of the code is saving the status register and resetting R0. Both things are required I think in order to work.

Hence, I think I couldn't write a faster ISR in assembler than the one provided by the C compiler.

I am afraid the best choice is using the 74HC670 registers for a safe and trusted interface between the microcontroller and the PPI.

apoloval, 2020-05-26:
After this analysis, I am pretty sure not having a proper interface between the PPI and the uController will give a lot of problems.

An interface design has been added in b233b2aa731761b718c923b65be64de378a5456f.

apoloval, 2024-11-22:
I am coming back to this problem while thinking about creating a enclosure for the PS/2 Keyboard Adapter.

I don't remember why I refused to continue my research of just using the Atmega as discussed above. Even with the ISR written in C, I can see that it could take no more than 30 cycles since the keyboard selection address changes to the write of the keyboard columns data in the output register. I measured it in the Atmel Studio Simulator. With a 16Mhz clock, it's 1.88uS. Far below the limit of 3.35uS.

So we have no reasons to believe it cannot be done, at least if we get rid of Arduino code abstractions and use Atmel C compiler directly.

Let's reopen this issue and work on the approach of implement the adapter using the Atmega only.

apoloval, 2024-11-22:
I have some firmware code in https://github.com/artemisamsx/msxps2kb. It is not completed yet, but it looks promising.

The point of this code is that it only uses interrupts to respond to keyboard matrix reads from the MSX PPI. The PS/2 interface doesn't use interrupts. The main program actively transfers data to and from the keyboard. This also makes the code simpler to read than the interrupt-based implementation we had before.

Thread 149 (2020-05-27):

Suggestion to add license

Redlolz, 2020-05-27:
Am I allowed to use this project for my own designs, or is it under a open source license?

apoloval, 2020-07-15:
Sure! Thanks so much for the reminder. And apologies for taking so much time to reply. I was not watching my own repo, sorry!

I just added [the license file](https://github.com/apoloval/artemisa/blob/master/LICENSE.txt). This is the [TAPR Open Hardware License](https://en.wikipedia.org/wiki/Open_Hardware_License). In summary, you can use the designs (documentation) from this repository and the products (hardware) derived from them under the following conditions:

- You may modify the documentation and make products based upon it.
- You may use products for any legal purpose without limitation.
- You may distribute unmodified documentation, but you must include the complete package as you received it.
- You may distribute products you make to third parties, if you either include the documentation on which the product is based, or make it available without charge for at least three years to anyone who requests it.
- You may distribute modified documentation or products based on it, if you:
  - License your modifications under the OHL.
  - Include those modifications, following the requirements stated below.
  - Attempt to send the modified documentation by email to any of the developers who have provided their email address. This is a good faith obligation—if the email fails, you need do nothing more and may go on with your distribution.
- If you create a design that you want to license under the OHL, you should:
  - Include the OHL document in a file named LICENSE.TXT (or LICENSE.PDF) that is included in the documentation package.
  - If the file format allows, include a notice like "Licensed under the TAPR Open Hardware License (www.tapr.org/OHL)" in each documentation file. While not required, you should also include this notice on printed circuit board artwork and the product itself; if space is limited the notice can be shortened or abbreviated.
  - Include a copyright notice in each file and on printed circuit board artwork.
  - If you wish to be notified of modifications that others may make, include your email address in a file named "CONTRIB.TXT" or something similar.
- Any time the OHL requires you to make documentation available to others, you must include all the materials you received from the upstream licensors. In addition, if you have modified the documentation:
  - You must identify the modifications in a text file (preferably named "CHANGES.TXT") that you include with the documentation.
  - That file must also include a statement like "These modifications are licensed under the TAPR Open Hardware License."
  - You must include any new files you created, including any manufacturing files (such as Gerber files) you create in the course of making products.
  - You must include both "before" and "after" versions of all files you modified.
  - You may include files in proprietary formats, but you must also include open format versions (such as Gerber, ASCII, Postscript, or PDF) if your tools can create them.

Enjoy it!

Redlolz, 2020-07-19:
Thank you very much!

Closed 2020-07-15.

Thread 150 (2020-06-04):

Introduce ±12V power supply rails

apoloval, 2020-06-04:
I am afraid ±12V is not as expendable as I initially supposed. We had a fruitful discussion in the Retrocacharreo channel in Telegram about the topic. And many hardware for sound and video processing demands these rails to feed their op-amps.

The goal of this issue is to investigate a solution for this problem and apply it in 101 and 201 motherboard series.

apoloval, 2020-06-04:
Here we have [a really nice video about the topic](https://www.youtube.com/watch?v=giGRrODKJSE).

Some buck converters are available at low price. Such as the [MC34063A](https://docs.rs-online.com/e64e/0900766b8138583a.pdf). However, I still have to figure out how it works.

apoloval, 2020-06-04:
The [TI datasheet](http://www.ti.com/lit/ds/symlink/mc34063a.pdf?ts=1591264916555) provides a better description of the step up and down circuits. It looks like we could use a pair of these to obtain +12V and -12V from a single source of +5V.

I've found [this article explaining how to convert +5V to -12V](https://www.multisim.com/content/BCyDrk9tGaJe5NAcySJvaP/inverter-5v-to-12v-mc34063/). And here we have [an schematic to step up from +5V to +12V](https://easyeda.com/modules/5V-to-12V-MC34063_3bfd29b7b410498fb2b7099be5e41eaa). With this, we could get the 12V rails we need.

apoloval, 2020-06-04:
In fact, the TI datasheet actually provides an example to get -12V from 5V:

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

msx-solis, 2020-06-12:
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

msx-solis, 2020-06-12:
Hi, I fount this through internet, I hope it helps you.
aditionally there's a circuit based on an LT1054 what can supply +12v -12v from Vcc (+5v). its on the following link:
[https://retrobrewcomputers.org/n8vem-pbwiki-archive/0/35845334/48860720/35845587/Printing%20MSXCartReader-sch.pdf](url)

apoloval, 2020-06-13:
Wow! Many thanks for the references! Especially for the LT1054.

The [datasheet](https://www.ti.com/lit/ds/symlink/lt1054.pdf?ts=1592065465468&ref_url=https%253A%252F%252Fwww.google.com%252F) shows an example to generate +12V/-12V from +5V. Even thou I don't understand it quite well (I cannot identify the outputs in the diagram):

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

The circuit from the MSX Cart Reader linked about is this one:

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

I think it is based on this one from the datasheet:

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

However, the TI datasheet says this is a doubler with a loss around 1V. So this would be +9V/-9V if I am not wrong.

apoloval, 2020-06-13:
Oh, I think there is a huge copy&shit in the TI datasheet. The figure 23 is exacty the same as the figure 26:

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

It is like they copied the wrong diagram and the converter we are looking for is missing.

Fortunately, there are other vendors who have the right circuit [in their datasheet, as Analog Devices](https://www.analog.com/media/en/technical-documentation/data-sheets/LT1054-1054L.pdf):

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

And yes, it is exactly the one shown in the MSX Cart Reader schematic.

Both parts are similar. But I have the feeling that the LT1054 requires less external components than the MC34063. Or at least they are more standard ones (no inductors required for the 1054!).

apoloval, 2020-06-13:
Pricing:
- LT1054: 2.99€/unit in Mouser.
- MC34063A: 0.54€/unit in Mouser.

The difference is huge. As we need 2 units, the 1054 is 6x as expensive than the 34063.

apoloval, 2022-11-02:
Recent updates. A completely different approach could be using a external power supply. The problem is to find a triple output one with 5V, +12V and -12V outputs. The problem is that I couldn't find one like this. Until now.

We have the [Mean Well RT-50B][1]. A enclosed power supply with 5V, +12V and -12V outputs. This could be embed into the computer case (if fits) such that the computer is directly powered by an AC cable. Or, it could be put into a separated case and connected to the computer case using a DIN cable. This unit is around 30€ in AliExpress.

In fact, Mean Well also has external power supplies with the same outputs that uses DIN cables. That's the case of [GP25A13D-R1B][2]. It is more expensive, [around 50€ including taxes in Digikey][3].

I think this is an excellent solution, as it is a sort of "out of design". We will not have to care about it anymore, assuming the motherboard receives power inputs of 5V, +12V and -12V. Period.

We have to think about how to provide a triple power switch.... Or not have any, as the original 101 design.

[1]: https://www.meanwell.com/Upload/PDF/RT-50/RT-50-SPEC.PDF
[2]: https://www.meanwell.com/webapp/product/search.aspx?prod=GP25A
[3]: https://www.digikey.es/es/products/detail/mean-well-usa-inc/GP25A13D-R1B/7703337

apoloval, 2022-11-02:
At least we know they exist:

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

msx-solis, 2022-11-02:
I think you shown a DPDT switch but you need a 3PST (if exists) or a 3PDT like this:
https://es.rs-online.com/web/p/interruptores-de-palanca/2740429

apoloval, 2022-11-02:
> I think you shown a DPDT switch but you need a 3PST (if exists) or a 3PDT like this: https://es.rs-online.com/web/p/interruptores-de-palanca/2740429

Yep, 3PST is an odd animal. But some vendors make 4P2T switches that could do the job, as [this one](http://www.xiejia.net/ProductAll.asp?MID=210).

apoloval, 2022-11-02:
Some interesting parts:
- [ALPS SSSF040800](https://lcsc.com/product-detail/Slide-Switches_ALPSALPINE-SSSF040800_C388871.html)
- [ALPS SPUN19C400](https://lcsc.com/product-detail/Push-Switches-Horizontal-Type_ALPSALPINE-SPUN19C400_C402824.html)
- [E-Switch PBH6UEENAGX](https://lcsc.com/product-detail/Push-Switches-Horizontal-Type_E-Switch-PBH6UEENAGX_C273425.html) (too expensive perhaps)
- [G-Switch PS-42F43](https://lcsc.com/product-detail/Push-Switches-Horizontal-Type_G-Switch-PS-42F43_C2848940.html)
- [G-Switch PBS-42D02](https://lcsc.com/product-detail/Push-Switches-Horizontal-Type_G-Switch-PBS-42D02_C2848956.html)

Obtained from [LCSC website](https://lcsc.com/products/Push-Switches-Horizontal-Type_11275.html).

apoloval, 2022-11-21:
Another interesting finding. Mean Well also has products such as [MDD02L-12][1]. This is a DC-DC unregulated converter encapsulated in a module with a PCB surface of 19.5x9.8mm. 5V inputs, producing a DUAL output of ±12V with a maximum current of ±83mA (MSX standard requires ±50mA for ±12V rail of all slots combined).

It costs <7€ in Mouser. Just requires a few standard capacitors and one inductance to work:

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

It is designed to isolate the input and output circuits, but after Googling about this subject I am pretty sure we can connect `Vin-` and `Com` together to have a common ground for input and output circuits. The benefit of isolation will be neutralized doing it, but we need a common ground due to MSX design restrictions.

[1]: https://www.meanwell.com/webapp/product/search.aspx?prod=MDD02

apoloval, 2022-11-21:
The [DPUN02L-12][1] is even better. Industrial grade instead of medical, but smaller and cheaper (5.07€ in Mouser).

[1]: https://www.meanwell.com/webapp/product/search.aspx?prod=DPUN02

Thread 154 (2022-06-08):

Custom power supply

apoloval, 2022-06-08:
In model 101, a single 5V DC input power source was used. The system depends on a external voltage source, typically provided by a brick adapter. This solution presents several drawbacks:

- Brick adapters are a bullshit. It is really hard to find a vendor whose adapters do not generate a source out from 4.75-5.25 volts range. Quite often, they go down to 4.65 volts.
- No ±12V power line. This is something already reported in #150.

Perhaps the way to go is to provide a custom power supply, with its 220/115 VAC to 30 VAC transformer, rectifier bridge, and voltage regulators using 7812, 7912 and 7805 parts.

apoloval, 2022-06-08:
I investigated a little bit. And there are some interesting AC transformers in Mouser such as [this][1] and [this][2].

However, they are a little bit expensive. Around 15€.

I also checked if Chinese parts could do the job. They are around 8€, but I could not find anything PCB-mounted.

There is also another alternative: design a 5V adapter and complement it with a ±12V step-up circuit as suggested in #150. But that is probably extremely power-inefficient.

[1]: https://www.mouser.es/datasheet/2/177/160_161-1389957.pdf
[2]: https://www.mouser.es/datasheet/2/177/162_164-1390053.pdf

apoloval, 2022-06-08:
Another interesting finding. Hi-Link produces [a encapsulated power module that converts 220/115 VAC to 5 VDC][1]. This is cool. But there is no solution for ±12V rails.

[1]: https://www.hlktech.com/en/Goods-16.html

apoloval, 2022-06-08:
Also, the classic AC to ±12V dual voltage regulator circuit is [explained here][1].

[1]: https://www.eleccircuit.com/power-regulator-12v_-12v-by-7812-7912/

apoloval, 2022-06-09:
Oh, this is an interesting discovery. The [Block VC 10/2/15][1]  is a encapsulated block device that can convert 220 VAC into a dual output of 15 VAC. There are many encapsulated block devices that does this, but they are typically low power. But this one has a rate of 10 VA. It is also unexpensive: [8€ in RS Online][2]. However, it is quite large. 51x43x34mm. Perhaps we can find something smaller...

Bingo! Having a look to the [Block catalog of PCB transformers][3] we can find the [VC 5/2/15][4]. Rated as 5 VA, with 44x33x37mm dimensions. [7€ in RS Online][6]. The [PT 4.5/2/15][5] is also a good fit. 4.5 VA, short-circuit proof and 37x44x33mm. There is also a VB family, but the max rate is 3.2 VA. Probably not enough.

Reading related stuff, I discovered the power rate refers to parallel output connections. This is, if you use it as a single 15 VAC output. If serial output connection is used to have ±15 VAC, the power rate for the positive rails (the one that will feed 7805 and 5 VDC rail) is half. This means we likely need a 10 VAC device. But we have to double check how these power translates into the circuit after voltage regulators. Perhaps we are aiming too high and we don't really need such large power rates.

[1]: https://www.block.eu/en_EN/productversion/vc-10215/
[2]: https://es.rs-online.com/web/p/transformadores-de-pcb/3472622
[3]: https://www.block.eu/en_EN/products/transformers/pcb-transformers/
[4]: https://www.block.eu/en_EN/productversion/vc-50215/
[5]: https://www.block.eu/en_EN/productversion/pt-45215/
[6]: https://es.rs-online.com/web/p/transformadores-de-pcb/3472559

apoloval, 2022-06-09:
Side note. A AC/AC transformer with a rectifier bridge backed up by a capacitor to smooth the output, produces a unregulated DC source whose value matches the peak voltage of the AC transformer.

This means for a 12Vac transformer: $12V * \sqrt{2} = 16.97V$. Most 7812 datasheets indicate they can operate with input voltages above 14V. Thus, a  ±12 VAC transformer would do the job.

In case of Block transformers, this means using [VC 5/2/12][1] or [PT 13/2/12][2]. They have the same size as 15V equivalents. But we might expect to be cheaper, and for sure we will have a wiser power usage.

[1]: https://www.block.eu/en_EN/productversion/vc-10212/
[2]: https://www.block.eu/en_EN/productversion/pt-13212/

apoloval, 2022-06-09:
Side note to the side note. The rectifier bridge is made by diodes that have a voltage drop. We can assume from 0.7 to 1.0 per diode, having 2 diodes with forward current at the same time. That's from 1.4V to 2.0V drop. So peak-to-peak output voltage from the transformer must be $>16V$.

Close to the limit. The fact that the signal is smoothed by a large capacitor also means a relative voltage drop. More calculations are needed.

apoloval, 2022-06-09:
Interesting reference. [TI Application report on Input and Output Capacitor Selection][1]. Interesting to calculate the properties of the capacitors used in a voltage regulation circuit.

[1]: https://www.ti.com/lit/an/slta055/slta055.pdf

apoloval, 2022-06-09:
Another interesting reference. A [Stack Exchange answer explaining how power rating affects an AC/DC regulator using 7805][1].

[1]: https://electronics.stackexchange.com/a/328202/215644

apoloval, 2022-06-09:
An interesting finding. I tried to simulate the AC transformer and wave rectifier in Falstad simulator:

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

- Source has peak voltage of 17V, 50Hz.
- Filter capacitor is 10mF.

If we force the situation and put a load that sinks 1A of current:

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

The voltage at the capacitor falls to 13.97V. That's close the the limit of the 7812. At that rate, it will have problems to deliver 12V at its output. 1 ampere seems to be a hard limit.

The bad news come from the ripple current hitting the capacitor. As they reach almost 12A. That's huge!

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

I think we have to calibrate the power consumption better to find realistic limits.

The Falstad circuit:

[rectifier.circuitjs.txt](https://github.com/artemisamsx/artemisa/files/8868676/rectifier.circuitjs.txt)

apoloval, 2022-06-09:
Having a look to schematics of old MSX systems to see how they do it.

Philips VG8020 uses an AC transformer with a dual coils:

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

One is used for low-power, ±12V rails. The other for high-power 5V rail.

The Spectravideo SVI-728 does a similar thing. The transformer has a dual output of 9Vac and 16Vac:

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

This is how they essentially get reasonable power losses due to voltage drops. We should take this way also, I am afraid.

apoloval, 2022-06-09:
[Block VB 10/2/15][1] could be used for ±12V rails. It is just 32x27mm. The power rate of 1VA is enough for the expected 30mA.

[Block PT 7.5/1/8][2] could be used for 5V rail. It is 51x43mm. Rated at 7.5VA, despite we need 8VA for 8V operation.

[VC 10/1/8][3] has the same dimentions. Rated at 10VA, exceeds the required 8VA.

In any case, we will need a lot of room in the PCB for all this.

[1]: https://www.block.eu/en_EN/productversion/vb-10215/
[2]: https://www.block.eu/en_EN/productversion/pt-7518/
[3]: https://www.block.eu/en_EN/productversion/vc-1018/

apoloval, 2022-06-09:
Of course, there is still the option of using a bump-up regulator such as the [MAX743][1]. It can use a 5V input to produce a ±12V rail. However, it is quite expensive. [15€ per unit][2].

[1]: https://www.maximintegrated.com/en/products/power/switching-regulators/MAX743.html
[2]: https://www.mouser.es/ProductDetail/Maxim-Integrated/MAX743EPE%2

apoloval, 2022-06-10:
Some useful maths.

If we use a transformer to 8Vac for 5V rail regulation:

$V_{pk} = 8V \cdot \sqrt{2} = 11.3V$

The voltage drop is defined as:

$V_{drop} = \frac{I \cdot T_{cycle}}{C}$

We know the voltage cannot go below 7V, which is the minimum input voltage for the 7805 to work:

$V_{drop} = 11.3V - 7V = 4.3V$

Thus, considering a max current of 1A and 50Hz of frequency (period of 10ms) our filter capacitor should be at least:

$C > \frac{I \cdot T_{cycle}}{V_{drop}} > \frac{1A \cdot 10ms}{4.3V} > 2.32 mF$
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
apoloval, 2024-11-18:
BTW, Meanwell DPRN01 is not suitable as it is an isolated converter. So we cannot mix the grounds with other converters.

apoloval, 2024-11-18:
There are some interesting non-isolated buck converters for outputs of 5V and 1A. Just listing a few:
- [Traco TSR 1-2450E](https://www.mouser.es/datasheet/2/687/tsr1e_datasheet-1842504.pdf). 3.64€, Vin > 7V, ripple 80mVpp typ.
- [Recon R-78E5.0-1.0](https://www.mouser.es/datasheet/2/468/R_78E_1_0-1711201.pdf). 3.74€, Vin > 8V, ripple 120mVpp max.
- [Wurth 173010578](https://www.we-online.com/components/products/datasheet/173010578.pdf). 6.78€, Vin > 8V, ripple 25mVpp typ.
- [Recon R-785.0-1.0](https://www.mouser.es/datasheet/2/468/R_78_1_0-1709942.pdf). 7.79€, Vin > 6.5V, ripple 20mVpp typ, 30mVpp max.

However, for -12V the options are very limited. Meanwell offers [the N7812-2](https://www.mouser.es/datasheet/2/260/MeanWell_08192024_N78_2_spec-3483609.pdf), but it is not real dual output. It just supports negative configuration, so you need 2 units at 5.87€ each.  The remaining parts converting to -12V starts at 13.35€.

I am thinking the best choice is to use a power module for 5V rail and have +12V/-12V rails using low-ripple switching regulators with external inductance and diodes.

apoloval, 2024-11-18:
About using switching regulators with external components: large inductances are not cheap. They start at 3.49€ in Mouser.

apoloval, 2024-11-19:
I am afraid that, at least for the +-12V rails, a custom converter circuit must be designed using a switching voltage regulator and maybe LDOs at the end.

Mouser offers switching voltage regulators starting at 0.57€ with [OnSemi MC34063](https://www.mouser.es/datasheet/2/308/1/MC34063A_D-2315484.pdf). However, the most popular part is the [LM2596](https://www.ti.com/lit/ds/symlink/lm2596.pdf). It is used in cheap Chinese voltage regulator boards on sale in AliExpress and friends. It became so popular that many different vendors implement it, including first brands as OnSemi but also many Chinese manufacturers from $0.42 at LCSC.

The 2596 is a buck converter, but it admits inverter topologies. So it can be used to generate a -12V rail, or a -13V connected to a LDO. It could be used also for the 5V rail, but considering how cheap and quiet are the power modules listead above, I don't think it worth.

For the 12V rail, we can use the 2596 as well as long as the input voltage is above, likely around 15V. However, it means the drop-off for the 5V rail is 10V. What makes the conversion more inefficient and noisy. Perhaps it's better to use a boost converter in such a case. The [MC34063](https://www.onsemi.com/download/data-sheet/pdf/mc34063a-d.pdf) seems to be a very popular option. And in fact, it also allows buck conversion. And it's incredible cheap! The implementation from STMicroelectronics from 0.25€ each at LCSC, 0.57€ at Mouser. The limit is 1.5A compared to the 3A of 2596. But it's enough for the Artemisa.

As a curiosity, STMicro's 34063 datasheet suggest a circuit to have a +-12V rails. Unfortunately, it requires a transformer coil:

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

apoloval, 2024-11-19:
Interesting finding. The [Wurth 173010578](https://www.we-online.com/components/products/datasheet/173010578.pdf) is designed to allow negative voltage generation:

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

Just taking into account that the input voltage range changes:
- For -12V, Vin must be in range 9-20V.
- For 12V, Vin must be in range 16-36V.
- For 5V, Vin must be in range 8-36V.

If we use the same part for all voltage rails, the input voltage should be in range 16-20V.

I also discovered that Meanwell also have a similar part: the N78 series. Ripple=100mVpp from 4.04€. It can be used for negative volt regulation using the same approach of changing the pins. The input voltage range is the same: 16-20V.

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

apoloval, 2024-11-19:
Another unexpensive approach is using a [7662 charge pump](https://www.mouser.es/datasheet/2/268/21469a-3442046.pdf) to invert a 15V input into a -15V line. And then use linear regulators to produce +-15V. TC7662 can be found from 2.49€ in Mouser.

The charge pumps have a significant output impedance, so they output less than desired voltage. But even if they produce -14V for a 15V input, it is enough for a LDO to produce -12V.

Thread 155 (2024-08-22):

Any Progress

Cptscorcher, 2024-08-22:
Not really an issue but just wondering if there are any further updates for this project? Looks like there has been a lot of work put into this project and I'm keen to build one of these but just not sure if either the 101 or 201 boards are mature enough to be working.

apoloval, 2024-08-26:
To be honest, the project is currently stalled from the product perspective.

The development of the 101 board is finished. Both the design and the implementation are tested and the computer works like a charm. I think that's the model to go if you want to build a homebrew computer by your own. In the other hand, the model 201 is under development. There is nothing usable there yet.

When I say model 101 is stalled from the product perspective I mean that the necessary steps to provide it as a DIY product you can purchase from the website are not completed yet. The pending parts are the documentation. My plans consists on having an extensive handbook explaining not only how the computer can be assembled but also the fundamentals of every single circuit in the computer. A sort of dissertation of 1980's computer design that IMO is 99% of the product value.

However, if you are interested in building the computer by your own and you have the knowledge and skills, feel free to generate the Gerber files of the boards and build it by yourself. Every few months I make some contributions to the documentation. But I cannot tell when it will be completed and DIY kits ready to be shipped. Same for the design of the 201 model.

Cptscorcher, 2024-08-27:
Thanks apoloval. I have done some mods on the 201 version and hope to fork and upload it at some point. But for now it's probably best to go with something tested so have ordered 5 boards.
The documentation is great, nice to see something more than a one line readme.md. I'm an electronic tech by trade and work as a technical writer. I'll send you an e-mail with more detail but I am keen to contribute to writing the docs. I could start with the build instructions when I finally get all the bits.

Closed 2024-11-17.

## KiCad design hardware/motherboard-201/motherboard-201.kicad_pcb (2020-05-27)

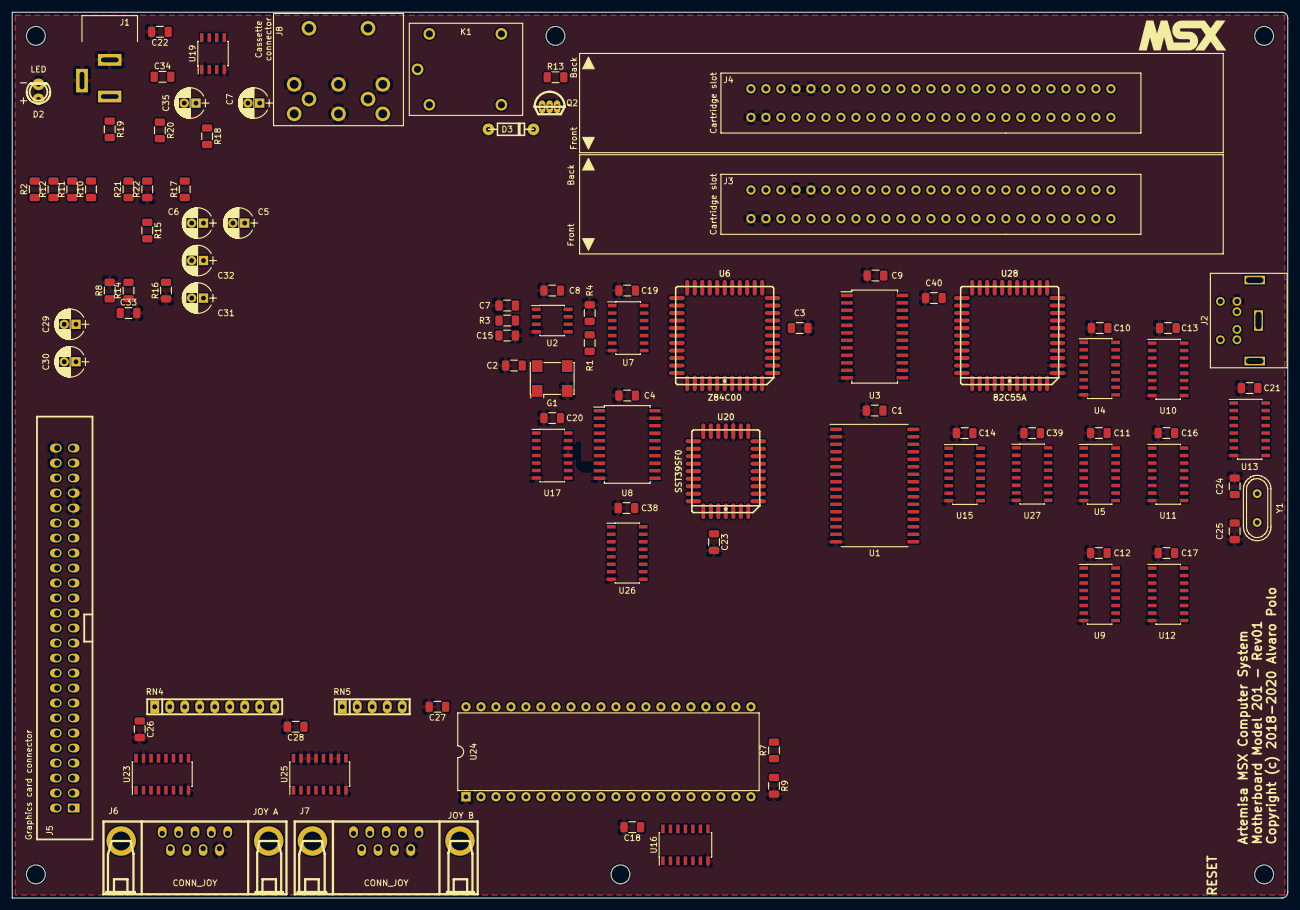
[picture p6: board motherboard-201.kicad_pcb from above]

Board: 2 copper layers, 216.0 x 150.0 mm, 99 parts (0 on the bottom side), 158 nets, no tracks yet.

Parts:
C1, C2, C3, C4, C7, C8, C9, C14, C18, C19, C20, C22, C23, C26, C27, C28, C38, C39, C40: 100nF; C_1206
C5, C7#2: 100uF; Radial_capacitor
C6: 10uF; Radial_capacitor
C10, C11, C12, C13, C16, C17, C21: 0.1uF; C_1206
C15: 1uF; C_1206
C24, C25: 33pF; C_1206
C29, C30, C31: 10u; Radial_capacitor
C32, C35: 1uF; Radial_capacitor
C33, C34: 22nF; C_1206
D2: LED
D3: 1N4448; Axial_diode
G1: SG7050
J1: PWR_conn; Jack_55_21
J2: PS2_CONN; PS2_conn
J3, J4: MSX_Slot; Slot_conn
J5: GFX_Connector_Output; GFX_conn
J6, J7: CONN_JOY; Joystick_conn
J8: DIN8
K1: Relay
Q2: 2N2907; TO92
R1, R4, R7, R9: 10K; R_1206
R2: 220; R_1206
R3: 560; R_1206
R8: 470; R_1206
R10: 20k; R_1206
R11, R14, R15, R17: 4k7; R_1206
R12, R21, R22: 2k7; R_1206
R13: 2k2; R_1206
R16: 100; R_1206
R18: 220k; R_1206
R19: 1k; R_1206
R20: 10k; R_1206
RN4: 10K; RN8
RN5: 10K; RN4
U1: AS6C1008; SOP-32_450
U2: TL7705; SOIC-8_150
U3: GAL_declogic-201; SOIC-24
U4, U5, U9, U10, U11, U12: 74HC670; SOIC-16
U6: Z84C00; PLCC44
U7, U17: 74HC74; SOIC-14
U8: 74HCT245; SOIC-20
U13: ATMEGA328P; SOIC-16
U15: 74HC139; SOIC-16
U16: 74LS07; SOIC-14
U19: LM311; SOIC-8_150
U20: SST39SF0; PLCC32
U23, U25: 74HC157; SOIC-16
U24: AY-3-8910; DIP-40_600
U26: 74HC138; SOIC-16
U27: 74HC153; SOIC-16
U28: 82C55A; PLCC44
Y1: 16Mhz; Crystal

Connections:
/ADDR0: J3.28, J4.28, J5.28, U1.12, U3.9, U6.34, U20.12, U28.10
/ADDR1: J3.27, J4.27, J5.27, U1.11, U3.10, U6.35, U20.11, U28.9
/ADDR14: J3.25, J4.25, J5.25, U1.3, U3.11, U6.4, U20.29, U27.14
/ADDR15: J3.18, J4.18, J5.18, U1.31, U3.13, U6.5, U27.2
/AUDIO: J5.49, R10.2, R11.2, R12.2
/BEEP: C29.1, U28.11
/CASIN: R19.1, U19.7, U24.14
/CASOUT: C32.1, U28.14
/CLK: G1.3, J3.42, J4.42, J5.42, U6.7, U7.3, U7.11, U17.3
/CPU/ADDR2: J3.30, J4.30, J5.30, U1.10, U6.36, U20.10
/CPU/ADDR3: J3.29, J4.29, J5.29, U1.9, U6.37, U20.9, U26.1
/CPU/ADDR4: J3.32, J4.32, J5.32, U1.8, U6.38, U20.8, U26.2
/CPU/ADDR5: J3.31, J4.31, J5.31, U1.7, U6.39, U20.7, U26.3
/CPU/ADDR6: J3.22, J4.22, J5.22, U1.6, U6.40, U20.6, U26.5
/CPU/ADDR7: J3.21, J4.21, J5.21, U1.5, U6.41, U20.5, U26.6
/CPU/ADDR8: J3.24, J4.24, J5.24, U1.27, U6.42, U20.27
/CPU/ADDR9: J3.17, J4.17, J5.17, U1.26, U6.43, U20.26
/CPU/ADDR10: J3.20, J4.20, J5.20, U1.23, U6.44, U20.23
/CPU/ADDR11: J3.19, J4.19, J5.19, U1.25, U6.1, U20.25
/CPU/ADDR12: J3.23, J4.23, J5.23, U1.4, U6.2, U20.4
/CPU/ADDR13: J3.26, J4.26, J5.26, U1.28, U6.3, U20.28
/CPU/D0: U6.16, U8.2
/CPU/D1: U6.17, U8.3
/CPU/D2: U6.14, U8.4
/CPU/D3: U6.9, U8.5
/CPU/D4: U6.8, U8.6
/CPU/D5: U6.10, U8.7
/CPU/D6: U6.11, U8.8
/CPU/D7: U6.15, U8.9
/CPU/DATA0: J3.34, J4.34, J5.34, U1.13, U8.18, U20.13, U24.37, U28.38
/CPU/DATA1: J3.33, J4.33, J5.33, U1.14, U8.17, U20.14, U24.36, U28.37
/CPU/DATA2: J3.36, J4.36, J5.36, U1.15, U8.16, U20.15, U24.35, U28.36
/CPU/DATA3: J3.35, J4.35, J5.35, U1.17, U8.15, U20.17, U24.34, U28.35
/CPU/DATA4: J3.38, J4.38, J5.38, U1.18, U8.14, U20.18, U24.33, U28.33
/CPU/DATA5: J3.37, J4.37, J5.37, U1.19, U8.13, U20.19, U24.32, U28.32
/CPU/DATA6: J3.40, J4.40, J5.40, U1.20, U8.12, U20.20, U24.31, U28.31
/CPU/DATA7: J3.39, J4.39, J5.39, U1.21, U8.11, U20.21, U24.30, U28.30
/DATADIR: U3.14, U8.1
/DECODING/~IOSL: U3.20, U26.4
/DECODING/~PPISL: U3.7, U17.10, U26.10
/DECODING/~PSGSL: U3.8, U26.11
/EXTSOUND: C30.1, J3.49, J4.49
/KBD/D0: U4.15, U5.15, U9.15, U10.15, U11.15, U12.15
/KBD/D1: U4.1, U5.1, U9.1, U10.1, U11.1, U12.1
/KBD/D2: U4.2, U5.2, U9.2, U10.2, U11.2, U12.2
/KBD/D3: U4.3, U5.3, U9.3, U10.3, U11.3, U12.3
/KBD/KBCOL0: U4.10, U5.10, U9.10, U28.20
/KBD/KBCOL1: U4.9, U5.9, U9.9, U28.21
/KBD/KBCOL2: U4.7, U5.7, U9.7, U28.22
/KBD/KBCOL3: U4.6, U5.6, U9.6, U28.24
/KBD/KBCOL4: U10.10, U11.10, U12.10, U28.25
/KBD/KBCOL5: U10.9, U11.9, U12.9, U28.26
/KBD/KBCOL6: U10.7, U11.7, U12.7, U28.27
/KBD/KBCOL7: U10.6, U11.6, U12.6, U28.28
/KBD/KBROW0: U4.5, U5.5, U9.5, U10.5, U11.5, U12.5, U28.16
/KBD/KBROW1: U4.4, U5.4, U9.4, U10.4, U11.4, U12.4, U28.17
/KBD/KBROW2: U15.14, U28.18
/KBD/KBROW3: U15.13, U28.19
/KBD/ROW0: U4.14, U5.14, U9.14, U10.14, U11.14, U12.14
/KBD/ROW1: U4.13, U5.13, U9.13, U10.13, U11.13, U12.13
/KBD/~RSL0: U4.11, U10.11, U15.12
/KBD/~RSL1: U5.11, U11.11, U15.11
/KBD/~RSL2: U9.11, U12.11, U15.10
/KBD/~WSL0H: U10.12, U13.15
/KBD/~WSL0L: U4.12, U13.14
/KBD/~WSL1L: U5.12, U13.16
/PPI/PA0: U27.6, U28.5
/PPI/PA1: U27.10, U28.4
/PPI/PA2: U27.5, U28.3
/PPI/PA3: U27.11, U28.2
/PPI/PA4: U27.4, U28.44
/PPI/PA5: U27.12, U28.43
/PPI/PA6: U27.3, U28.42
/PPI/PA7: U27.13, U28.41
/PSG/IOA0: U23.4, U24.21
/PSG/IOA1: U23.7, U24.20
/PSG/IOA2: U23.9, U24.19
/PSG/IOA3: U23.12, U24.18
/PSG/IOA4: U24.17, U25.4
/PSG/IOA5: U24.16, U25.7
/PSG/IOB0: U16.1, U24.13
/PSG/IOB1: U16.3, U24.12
/PSG/IOB2: U16.5, U24.11
/PSG/IOB3: U16.9, U24.10
/PSG/IOB4: J6.8, U24.9
/PSG/IOB5: J7.8, U24.8
/PSG/IOB6: U23.1, U24.7, U25.1
/PSG/JOYA1: J6.1, RN4.9, U23.2
/PSG/JOYA2: J6.2, RN4.8, U23.5
/PSG/JOYA3: J6.3, RN4.7, U23.11
/PSG/JOYA4: J6.4, RN4.6, U23.14
/PSG/JOYA6: J6.6, RN5.5, U16.8, U25.2
/PSG/JOYA7: J6.7, RN5.4, U16.6, U25.5
/PSG/JOYB1: J7.1, RN4.5, U23.3
/PSG/JOYB2: J7.2, RN4.4, U23.6
/PSG/JOYB3: J7.3, RN4.3, U23.10
/PSG/JOYB4: J7.4, RN4.2, U23.13
/PSG/JOYB6: J7.6, RN5.3, U16.4, U25.3
/PSG/JOYB7: J7.7, RN5.2, U16.2, U25.6
/PSGBC1: U3.19, U24.29
/PSGBDIR: U3.18, U24.27
/PSGCLK: U17.5, U24.22
/RESET: R4.2, U2.6, U28.39
/~CAPSLOCK: U13.6, U28.13
/~CASMOTOR: R13.2, U28.15
/~CS1: J3.1, J4.1, J5.1, U3.21
/~CS2: J3.2, J4.2, J5.2, U3.22
/~CS12: J3.3, J4.3, J5.3, U3.23
/~INT: J3.8, J4.8, J5.8, U6.18
/~IORQ: J3.11, J4.11, J5.11, U3.4, U6.22
/~KANALOCK: R9.1, U13.11, U24.6
/~M1: J3.9, J4.9, J5.9, U3.5, U6.31, U7.2
/~MREQ: J3.12, J4.12, J5.12, U3.3, U6.21
/~PPIRD: U3.15, U28.6
/~PPIRDY: U17.8, U27.1, U27.15
/~PPIWR: U3.16, U28.40
/~RD: J3.14, J4.14, J5.14, U1.24, U3.1, U6.23, U20.24
/~RESET: J3.15, J4.15, J5.15, R1.2, U2.5, U6.30, U13.1, U17.13, U24.23
/~RFSH: J3.6, J4.6, J5.6, U3.6, U6.32
/~SLTSL0: U15.4, U20.22
/~SLTSL1: U1.22, U15.5
/~SLTSL2: J3.4, U15.6
/~SLTSL3: J4.4, U15.7
/~SLTSLEN: U3.17, U15.1
/~VDPSL: J5.16, U26.12
/~WAIT: J3.7, J4.7, J5.7, U7.1, U7.10
/~WR: J3.13, J4.13, J5.13, U1.29, U3.2, U6.26
GND: C1.2, C2.2, C3.2, C4.2, C5.2, C6.2, C7.2, C7#2.2, C8.1, C9.2, C10.1, C11.1, C12.1, C13.1, C14.2, C15.2, C16.1, C17.1, C18.2, C19.2, C20.2, C21.1, C22.2, C23.2, C24.1, C25.1, C26.2, C27.2, C28.2, C33.2, C35.2, C38.2, C39.2, C40.2, D2.2, G1.2, J1.2, J1.3, J2.3, J3.41, J3.43, J3.48, J3.50, J4.41, J4.43, J4.48, J4.50, J5.41, J5.43, J5.48, J5.50, J6.9, J7.9, J8.1, J8.2, J8.3, J8.8, Q2.1, R4.1, R8.2, R9.2, R16.1, R22.1, U1.2, U1.16, U2.4, U3.12, U4.8, U5.8, U6.33, U7.7, U8.10, U8.19, U9.8, U10.8, U11.8, U12.8, U13.8, U15.8, U15.15, U16.7, U17.7, U17.11, U17.12, U19.1, U19.4, U20.16, U23.8, U23.15, U24.1, U24.24, U25.8, U25.10, U25.11, U25.13, U25.14, U25.15, U26.8, U27.8, U28.7, U28.8
unnamed: C7.1, C7#2.1, U2.1
unnamed: C15.1, R3.2
unnamed: C24.2, U13.9, Y1.1
unnamed: C25.2, U13.10, Y1.2
unnamed: C29.2, R10.1
unnamed: C30.2, R11.1
unnamed: C31.1, R8.1, U24.3, U24.4, U24.38
unnamed: C31.2, R12.1
unnamed: C32.2, R14.2
unnamed: C33.1, R14.1, R15.2
unnamed: C34.1, R17.1
unnamed: C34.2, J8.5
unnamed: C35.1, R20.2, R21.1, R22.2, U19.2
unnamed: D2.1, R2.2
unnamed: D3.1, K1.2, Q2.3
unnamed: J2.1, U13.5
unnamed: J2.5, U13.4
unnamed: J8.4, R15.1, R16.2
unnamed: J8.6, K1.4
unnamed: J8.7, K1.3
unnamed: Q2.2, R13.1
unnamed: R3.1, U2.3
unnamed: R7.2, U24.15
unnamed: R17.2, R18.1, R20.1, U19.3
unnamed: U6.28, U7.5, U7.12
unnamed: U7.4, U7.9
unnamed: U15.2, U27.7
unnamed: U15.3, U27.9
unnamed: U17.2, U17.6
~: C1.1, C2.1, C3.1, C4.1, C5.1, C6.1, C8.2, C9.1, C10.2, C11.2, C12.2, C13.2, C14.1, C16.2, C17.2, C18.1, C19.1, C20.1, C21.2, C22.1, C23.1, C26.1, C27.1, C28.1, C38.1, C39.1, C40.1, D3.2, G1.1, G1.4, J1.1, J2.4, J3.45, J3.47, J4.45, J4.47, J5.4, J5.45, J5.47, J6.5, J7.5, K1.1, R1.1, R2.1, R7.1, R18.2, R19.2, R21.2, RN4.1, RN5.1, U1.30, U1.32, U2.2, U2.7, U2.8, U3.24, U4.16, U5.16, U6.13, U6.19, U6.29, U7.13, U7.14, U8.20, U9.16, U10.16, U11.16, U12.16, U13.7, U15.16, U16.14, U17.1, U17.4, U17.14, U19.8, U20.31, U20.32, U23.16, U24.25, U24.28, U24.40, U25.16, U26.16, U27.16, U28.29

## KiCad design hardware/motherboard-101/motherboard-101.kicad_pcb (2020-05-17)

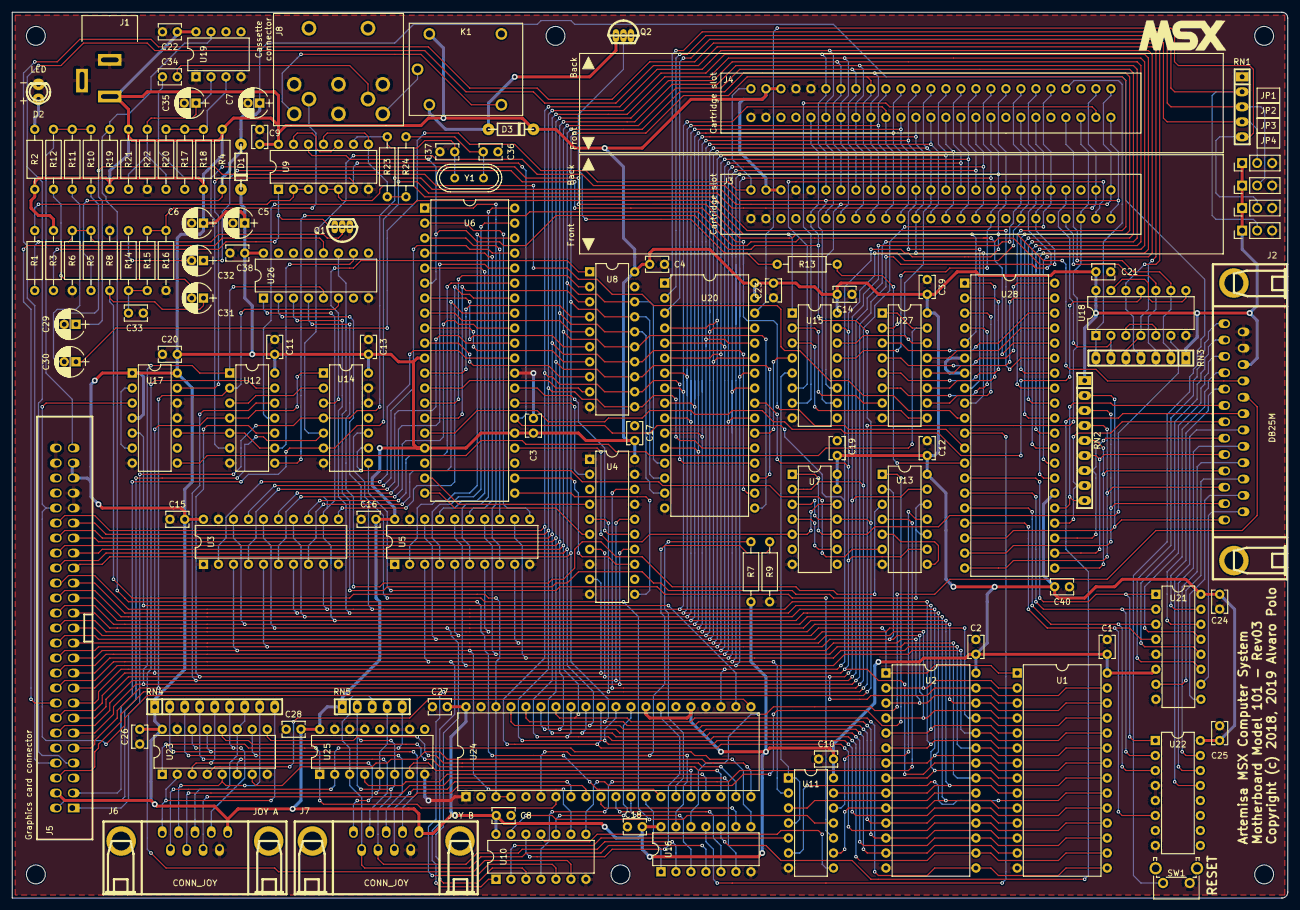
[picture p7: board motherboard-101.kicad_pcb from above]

Board: 2 copper layers, 216.0 x 150.0 mm, 117 parts (0 on the bottom side), 207 nets.

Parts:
C1, C2, C3, C4, C8, C9, C10, C11, C12, C13, C14, C15, C16, C17, C18, C19, C20, C21, C22, C23, C24, C25, C26, C27, C28, C38, C39, C40: 100nF; Disc_capacitor
C5, C7: 100uF; Radial_capacitor
C6: 10uF; Radial_capacitor
C29, C30, C31: 10u; Radial_capacitor
C32, C35: 1uF; Radial_capacitor
C33, C34: 22nF; Disc_capacitor
C36, C37: 33pF; Disc_capacitor
D1, D3: 1N4448; Axial_diode
D2: LED
J1: PWR_conn; Jack_55_21
J2: DB25M
J3, J4: MSX_Slot; Slot_conn
J5: GFX_Connector_Output; GFX_conn
J6, J7: CONN_JOY; Joystick_conn
J8: DIN8
JP1, JP2, JP3, JP4: Jumper
K1: Relay
Q1: 2N2222; TO92
Q2: 2N2907; TO92
R1: 100K; Axial_resistor
R2: 220; Axial_resistor
R3, R6: 4K7; Axial_resistor
R4, R7, R9: 10K; Axial_resistor
R5, R24: 1K; Axial_resistor
R8: 470; Axial_resistor
R10: 20k; Axial_resistor
R11, R14, R15, R17: 4k7; Axial_resistor
R12, R21, R22: 2k7; Axial_resistor
R13: 2k2; Axial_resistor
R16: 100; Axial_resistor
R18: 220k; Axial_resistor
R19: 1k; Axial_resistor
R20: 10k; Axial_resistor
R23: 1M; Axial_resistor
RN1, RN5: 10K; RN4
RN2, RN4: 10K; RN8
RN3: 10K; RN6
SW1: Push_button; Push_button_angled
U1, U2: 62256; DIP-28_600
U3, U4, U5: 74HCT244; DIP-20_300
U6: Z84C00; DIP-40_600
U7, U17: 74HC74; DIP-14_300
U8: 74HCT245; DIP-20_300
U9: 74HCU04; DIP-14_300
U10: 74HC04; DIP-14_300
U11, U12, U13: 74HC32; DIP-14_300
U14: 74HC08; DIP-14_300
U15: 74HC139; DIP-16_300
U16: 74LS07; DIP-14_300
U18: 74HCT08; DIP-14_300
U19: LM311; DIP-8_300
U20: SST39SF0; DIP-32_600
U21, U22, U26: 74HC138; DIP-16_300
U23, U25: 74HC157; DIP-16_300
U24: AY-3-8910; DIP-40_600
U27: 74HC153; DIP-16_300
U28: 82C55A; DIP-40_600
Y1: 3.58Mhz; Crystal

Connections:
/ADDR0: J3.28, J4.28, J5.28, U1.10, U2.10, U3.18, U11.9, U20.12, U28.9
/ADDR1: J3.27, J4.27, J5.27, U1.9, U2.9, U3.16, U10.3, U11.13, U20.11, U28.8
/ADDR14: J3.25, J4.25, J5.25, U1.1, U2.1, U5.5, U15.14, U20.29, U27.14
/ADDR15: J3.18, J4.18, J5.18, U5.3, U10.1, U11.2, U15.13, U27.2
/AUDIO: J5.49, R10.2, R11.2, R12.2
/BEEP: C29.1, U28.10
/CASIN: R19.1, U19.7, U24.14
/CASOUT: C32.1, U28.12
/CLK: J3.42, J4.42, J5.42, U6.6, U7.3, U7.11, U9.12, U17.3
/CPU/A0: U3.2, U6.30
/CPU/A1: U3.4, U6.31
/CPU/A2: U3.6, U6.32
/CPU/A3: U3.8, U6.33
/CPU/A4: U3.11, U6.34
/CPU/A5: U3.13, U6.35
/CPU/A6: U3.15, U6.36
/CPU/A7: U3.17, U6.37
/CPU/A8: U5.2, U6.38
/CPU/A9: U5.4, U6.39
/CPU/A10: U5.6, U6.40
/CPU/A11: U5.8, U6.1
/CPU/A12: U5.11, U6.2
/CPU/A13: U5.13, U6.3
/CPU/A14: U5.15, U6.4
/CPU/A15: U5.17, U6.5
/CPU/ADDR2: J3.30, J4.30, J5.30, U1.8, U2.8, U3.14, U20.10
/CPU/ADDR3: J3.29, J4.29, J5.29, U1.7, U2.7, U3.12, U20.9, U26.1
/CPU/ADDR4: J3.32, J4.32, J5.32, U1.6, U2.6, U3.9, U20.8, U26.2
/CPU/ADDR5: J3.31, J4.31, J5.31, U1.5, U2.5, U3.7, U20.7, U26.3
/CPU/ADDR6: J3.22, J4.22, J5.22, U1.4, U2.4, U3.5, U13.2, U20.6
/CPU/ADDR7: J3.21, J4.21, J5.21, U1.3, U2.3, U3.3, U10.9, U20.5
/CPU/ADDR8: J3.24, J4.24, J5.24, U1.25, U2.25, U5.18, U20.27
/CPU/ADDR9: J3.17, J4.17, J5.17, U1.24, U2.24, U5.16, U20.26
/CPU/ADDR10: J3.20, J4.20, J5.20, U1.21, U2.21, U5.14, U20.23
/CPU/ADDR11: J3.19, J4.19, J5.19, U1.23, U2.23, U5.12, U20.25
/CPU/ADDR12: J3.23, J4.23, J5.23, U1.2, U2.2, U5.9, U20.4
/CPU/ADDR13: J3.26, J4.26, J5.26, U1.26, U2.26, U5.7, U20.28
/CPU/D0: U6.14, U8.2
/CPU/D1: U6.15, U8.3
/CPU/D2: U6.12, U8.4
/CPU/D3: U6.8, U8.5
/CPU/D4: U6.7, U8.6
/CPU/D5: U6.9, U8.7
/CPU/D6: U6.10, U8.8
/CPU/D7: U6.13, U8.9
/CPU/DATA0: J3.34, J4.34, J5.34, U1.11, U2.11, U8.18, U20.13, U24.37, U28.34
/CPU/DATA1: J3.33, J4.33, J5.33, U1.12, U2.12, U8.17, U20.14, U24.36, U28.33
/CPU/DATA2: J3.36, J4.36, J5.36, U1.13, U2.13, U8.16, U20.15, U24.35, U28.32
/CPU/DATA3: J3.35, J4.35, J5.35, U1.15, U2.15, U8.15, U20.17, U24.34, U28.31
/CPU/DATA4: J3.38, J4.38, J5.38, U1.16, U2.16, U8.14, U20.18, U24.33, U28.30
/CPU/DATA5: J3.37, J4.37, J5.37, U1.17, U2.17, U8.13, U20.19, U24.32, U28.29
/CPU/DATA6: J3.40, J4.40, J5.40, U1.18, U2.18, U8.12, U20.20, U24.31, U28.28
/CPU/DATA7: J3.39, J4.39, J5.39, U1.19, U2.19, U8.11, U20.21, U24.30, U28.27
/DATADIR: U8.1, U14.3
/DECODING/~PPISL: U12.5, U12.9, U17.10, U26.10
/DECODING/~PSGBDIR: U10.13, U11.11, U14.10
/DECODING/~PSGRD: U13.5, U13.8
/DECODING/~PSGSL: U13.10, U13.12, U26.11
/DECODING/~PSGWR: U11.12, U13.11
/EXTSOUND: C30.1, J3.49, J4.49
/KBD/KBCOL0: J2.1, RN2.2, U28.18
/KBD/KBCOL1: J2.2, RN2.3, U28.19
/KBD/KBCOL2: J2.3, RN2.4, U28.20
/KBD/KBCOL3: J2.4, RN2.5, U28.21
/KBD/KBCOL4: J2.5, RN2.6, U28.22
/KBD/KBCOL5: J2.6, RN2.7, U28.23
/KBD/KBCOL6: J2.7, RN2.8, U28.24
/KBD/KBCOL7: J2.8, RN2.9, U28.25
/KBD/KBROW0: U21.1, U22.1, U28.14
/KBD/KBROW1: U21.2, U22.2, U28.15
/KBD/KBROW2: U21.3, U22.3, U28.16
/KBD/KBROW3: U21.4, U22.6, U28.17
/KBD/~CAPSL: J2.20, U16.10
/KBD/~KANAL: J2.21, U16.12
/KBD/~RSL0: J2.9, U21.15
/KBD/~RSL1: J2.10, U21.14
/KBD/~RSL2: J2.11, U21.13
/KBD/~RSL3: J2.12, U21.12
/KBD/~RSL4: J2.13, U21.11
/KBD/~RSL5: J2.14, U21.10
/KBD/~RSL6: J2.15, U21.9
/KBD/~RSL7: J2.16, U21.7
/KBD/~RSL8: J2.17, U22.15
/KBD/~RSL9: J2.18, U22.14
/KBD/~RSL10: J2.19, U22.13
/PPI/PA0: U27.6, U28.4
/PPI/PA1: U27.10, U28.3
/PPI/PA2: U27.5, U28.2
/PPI/PA3: U27.11, U28.1
/PPI/PA4: U27.4, U28.40
/PPI/PA5: U27.12, U28.39
/PPI/PA6: U27.3, U28.38
/PPI/PA7: U27.13, U28.37
/PSG/IOA0: U23.4, U24.21
/PSG/IOA1: U23.7, U24.20
/PSG/IOA2: U23.9, U24.19
/PSG/IOA3: U23.12, U24.18
/PSG/IOA4: U24.17, U25.4
/PSG/IOA5: U24.16, U25.7
/PSG/IOB0: U16.1, U24.13
/PSG/IOB1: U16.3, U24.12
/PSG/IOB2: U16.5, U24.11
/PSG/IOB3: U16.9, U24.10
/PSG/IOB4: J6.8, U24.9
/PSG/IOB5: J7.8, U24.8
/PSG/IOB6: U23.1, U24.7, U25.1
/PSG/JOYA1: J6.1, RN4.9, U23.2
/PSG/JOYA2: J6.2, RN4.8, U23.5
/PSG/JOYA3: J6.3, RN4.7, U23.11
/PSG/JOYA4: J6.4, RN4.6, U23.14
/PSG/JOYA6: J6.6, RN5.5, U16.8, U25.2
/PSG/JOYA7: J6.7, RN5.4, U16.6, U25.5
/PSG/JOYB1: J7.1, RN4.5, U23.3
/PSG/JOYB2: J7.2, RN4.4, U23.6
/PSG/JOYB3: J7.3, RN4.3, U23.10
/PSG/JOYB4: J7.4, RN4.2, U23.13
/PSG/JOYB6: J7.6, RN5.3, U16.4, U25.3
/PSG/JOYB7: J7.7, RN5.2, U16.2, U25.6
/PSGBC1: U10.10, U24.29
/PSGBDIR: U10.12, U24.27
/PSGCLK: U17.5, U24.22
/RESET: U9.4, U9.5, U28.35
/SLOTS/~EXTINT2: J3.8, RN3.3, U18.10
/SLOTS/~EXTINT3: J4.8, RN3.2, U18.9
/SLOTS/~EXTWAIT2: J3.7, RN3.6, U18.2
/SLOTS/~EXTWAIT3: J4.7, RN3.7, U18.1
/SLOTS/~VDPINT: J5.8, RN3.4, U18.12
/SLOTS/~VDPWAIT: J5.7, RN3.5, U18.4
/~CAPSLOCK: U16.11, U28.11
/~CASMOTOR: R13.2, U28.13
/~CS1: J3.1, J4.1, J5.1, U14.4, U15.11
/~CS2: J3.2, J4.2, J5.2, U14.5, U15.10
/~CS12: J3.3, J4.3, J5.3, U14.6
/~EXTINT: U6.16, U18.11
/~EXTWAIT: U7.1, U7.10, U18.6
/~IORQ: J3.11, J4.11, J5.11, U4.14, U12.1, U26.5
/~KANALOCK: R9.1, U16.13, U24.6
/~M1: J3.9, J4.9, J5.9, U4.18, U7.2, U12.2, U26.6
/~MREQ: J3.12, J4.12, J5.12, U4.16, U12.12
/~PPIRD: U12.6, U28.5
/~PPIRDY: U17.8, U27.1, U27.15
/~PPIWR: U12.8, U28.36
/~RAMSL0: U1.20, U11.6
/~RAMSL1: U2.20, U11.3
/~RD: J3.14, J4.14, J5.14, U1.22, U2.22, U4.9, U12.4, U13.9, U14.1, U15.15, U20.24
/~RESET: J2.22, J3.15, J4.15, J5.15, U6.26, U9.6, U17.13, U24.23
/~RFSH: J3.6, J4.6, J5.6, U4.5, U10.5
/~SLTSL0: U15.4, U20.22
/~SLTSL1: U11.1, U11.4, U15.5
/~SLTSL2: J3.4, U15.6
/~SLTSL3: J4.4, U15.7
/~SLTSLEN: U12.11, U15.1
/~VDPSL: J5.16, U26.12
/~WR: J3.13, J4.13, J5.13, U1.27, U2.27, U4.7, U12.10, U13.13
GND: C1.2, C2.2, C3.2, C4.2, C5.2, C6.2, C7.2, C8.2, C9.2, C10.2, C11.2, C12.2, C13.2, C14.2, C15.2, C16.2, C17.2, C18.2, C19.2, C20.2, C21.2, C22.2, C23.2, C24.2, C25.2, C26.2, C27.2, C28.2, C33.2, C35.2, C36.2, C37.2, C38.2, C39.2, C40.2, D2.2, J1.2, J1.3, J2.24, J2.25, J3.41, J3.43, J3.48, J3.50, J4.41, J4.43, J4.48, J4.50, J5.41, J5.43, J5.48, J5.50, J6.9, J7.9, J8.1, J8.2, J8.3, J8.8, JP1.3, JP2.3, JP3.3, JP4.3, Q1.3, Q2.1, R6.2, R8.2, R9.2, R16.1, R22.1, RN1.1, SW1.1, U1.14, U2.14, U3.1, U3.10, U3.19, U4.1, U4.8, U4.10, U4.17, U4.19, U5.1, U5.10, U5.19, U6.29, U7.7, U8.10, U8.19, U9.7, U10.7, U11.7, U12.7, U13.7, U14.7, U14.12, U14.13, U15.8, U16.7, U17.7, U17.11, U17.12, U18.7, U19.1, U19.4, U20.16, U21.5, U21.8, U22.4, U22.5, U22.8, U23.8, U23.15, U24.1, U24.24, U25.8, U25.10, U25.11, U25.13, U25.14, U25.15, U26.8, U27.8, U28.6, U28.7
unnamed: C7.1, D1.1, R4.2, R5.2, SW1.2
unnamed: C29.2, R10.1
unnamed: C30.2, R11.1
unnamed: C31.1, R8.1, U24.3, U24.4, U24.38
unnamed: C31.2, R12.1
unnamed: C32.2, R14.2
unnamed: C33.1, R14.1, R15.2
unnamed: C34.1, R17.1
unnamed: C34.2, J8.5
unnamed: C35.1, R20.2, R21.1, R22.2, U19.2
unnamed: C36.1, R23.1, U9.9, Y1.1
unnamed: C37.1, R24.1, Y1.2
unnamed: D2.1, R2.2
unnamed: D3.1, K1.2, Q2.3
unnamed: J8.4, R15.1, R16.2
unnamed: J8.6, K1.4
unnamed: J8.7, K1.3
unnamed: JP1.2, RN1.4, U20.3
unnamed: JP2.2, RN1.3, U20.2
unnamed: JP3.2, RN1.5, U20.30
unnamed: JP4.2, RN1.2, U20.1
unnamed: Q1.1, R3.2, U9.1
unnamed: Q1.2, R1.2, R5.1, R6.1
unnamed: Q2.2, R13.1
unnamed: R1.1, U9.2, U9.3
unnamed: R7.2, U24.15
unnamed: R17.2, R18.1, R20.1, U19.3
unnamed: R23.2, R24.2, U9.8, U9.11
unnamed: U4.2, U6.27
unnamed: U4.4, U6.19
unnamed: U4.6, U6.20
unnamed: U4.11, U6.21
unnamed: U4.13, U6.22
unnamed: U4.15, U6.28
unnamed: U6.24, U7.5, U7.12
unnamed: U7.4, U7.9
unnamed: U9.10, U9.13
unnamed: U10.2, U11.5
unnamed: U10.4, U13.4
unnamed: U10.6, U12.13
unnamed: U10.8, U13.1
unnamed: U10.11, U11.8
unnamed: U11.10, U14.8
unnamed: U12.3, U14.2
unnamed: U13.3, U26.4
unnamed: U13.6, U14.9
unnamed: U15.2, U27.7
unnamed: U15.3, U27.9
unnamed: U17.2, U17.6
unnamed: U18.3, U18.5
unnamed: U18.8, U18.13
~: C1.1, C2.1, C3.1, C4.1, C5.1, C6.1, C8.1, C9.1, C10.1, C11.1, C12.1, C13.1, C14.1, C15.1, C16.1, C17.1, C18.1, C19.1, C20.1, C21.1, C22.1, C23.1, C24.1, C25.1, C26.1, C27.1, C28.1, C38.1, C39.1, C40.1, D1.2, D3.2, J1.1, J2.23, J3.45, J3.47, J4.45, J4.47, J5.4, J5.45, J5.47, J6.5, J7.5, JP1.1, JP2.1, JP3.1, JP4.1, K1.1, R2.1, R3.1, R4.1, R7.1, R18.2, R19.2, R21.2, RN2.1, RN3.1, RN4.1, RN5.1, U1.28, U2.28, U3.20, U4.20, U5.20, U6.11, U6.17, U6.25, U7.13, U7.14, U8.20, U9.14, U10.14, U11.14, U12.14, U13.14, U14.14, U15.16, U16.14, U17.1, U17.4, U17.14, U18.14, U19.8, U20.31, U20.32, U21.6, U21.16, U22.16, U23.16, U24.25, U24.28, U24.40, U25.16, U26.16, U27.16, U28.26

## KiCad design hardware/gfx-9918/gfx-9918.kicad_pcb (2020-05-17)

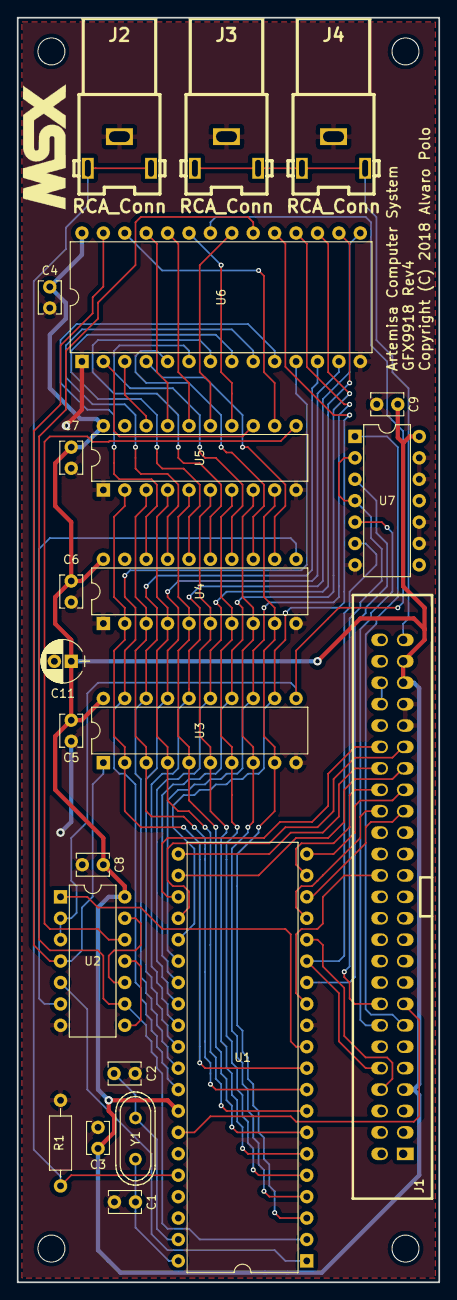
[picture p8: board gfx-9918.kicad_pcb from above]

Board: 2 copper layers, 50.0 x 150.0 mm, 23 parts (0 on the bottom side), 62 nets.

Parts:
C1, C2: 56pF; Disc_capacitor
C3, C4, C5, C6, C7, C8, C9: 100nF; Disc_capacitor
C11: 10uF; Radial_capacitor
J1: GFX_Connector_Input; GFX_conn
J2: RCA_Conn; RCA_yellow
J3: RCA_Conn; RCA_white
J4: RCA_Conn; RCA_red
R1: 470; Axial_resistor
U1: TMS9918; DIP-40_600
U2: 74HCT04; DIP-14_300
U3, U4, U5: 74HCT574; DIP-20_300
U6: 62256; DIP-28_600
U7: 74HC32; DIP-14_300
Y1: 10.7386Mhz; Crystal

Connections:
/Input connector & power/A0: J1.28, U1.13
/Input connector & power/BUSDIR: J1.10, U1.15, U7.6
/Input connector & power/DATA0: J1.34, U1.17
/Input connector & power/DATA1: J1.33, U1.18
/Input connector & power/DATA2: J1.36, U1.19
/Input connector & power/DATA3: J1.35, U1.20
/Input connector & power/DATA4: J1.38, U1.21
/Input connector & power/DATA5: J1.37, U1.22
/Input connector & power/DATA6: J1.40, U1.23
/Input connector & power/DATA7: J1.39, U1.24
/Input connector & power/SOUNDOUT: J1.49, J3.1, J4.1
/Input connector & power/~INT: J1.8, U1.16
/Input connector & power/~RD: J1.14, U7.5
/Input connector & power/~RESET: J1.15, U1.34
/Input connector & power/~VDPIOSL: J1.16, U7.2, U7.4
/Input connector & power/~WR: J1.13, U7.1
/Interface Decoding Logic/~CSW: U1.14, U7.3
/Output connectors/CVBS: J2.1, R1.1, U1.36
/VRAM Decoding Logic/A0: U4.18, U6.10
/VRAM Decoding Logic/A1: U4.17, U6.9
/VRAM Decoding Logic/A2: U4.16, U6.8
/VRAM Decoding Logic/A3: U4.15, U6.7
/VRAM Decoding Logic/A4: U4.14, U6.6
/VRAM Decoding Logic/A5: U4.13, U6.5
/VRAM Decoding Logic/A6: U4.12, U6.4
/VRAM Decoding Logic/A7: U5.18, U6.3
/VRAM Decoding Logic/A8: U5.17, U6.25
/VRAM Decoding Logic/A9: U5.16, U6.24
/VRAM Decoding Logic/A10: U5.15, U6.21
/VRAM Decoding Logic/A11: U5.14, U6.23
/VRAM Decoding Logic/A12: U5.13, U6.2
/VRAM Decoding Logic/A13: U5.12, U6.26
/VRAM Decoding Logic/AD0: U1.10, U3.2, U4.2, U5.2
/VRAM Decoding Logic/AD1: U1.9, U3.3, U4.3, U5.3
/VRAM Decoding Logic/AD2: U1.8, U3.4, U4.4, U5.4
/VRAM Decoding Logic/AD3: U1.7, U3.5, U4.5, U5.5
/VRAM Decoding Logic/AD4: U1.6, U3.6, U4.6, U5.6
/VRAM Decoding Logic/AD5: U1.5, U3.7, U4.7, U5.7
/VRAM Decoding Logic/AD6: U1.4, U3.8, U4.8, U5.8
/VRAM Decoding Logic/AD7: U1.3, U3.9, U4.9, U5.9
/VRAM Decoding Logic/RD: U2.4, U3.1, U6.27
/VRAM Decoding Logic/WR: U2.2, U2.3, U3.11, U6.22
/VRAM Decoding Logic/~CAS: U1.2, U2.9, U6.20
/VRAM Decoding Logic/~RAS: U1.1, U2.5
/VRAM Decoding Logic/~WR: U1.11, U2.1
/VRAM/RD0: U1.32, U3.19, U6.11
/VRAM/RD1: U1.31, U3.18, U6.12
/VRAM/RD2: U1.30, U3.17, U6.13
/VRAM/RD3: U1.29, U3.16, U6.15
/VRAM/RD4: U1.28, U3.15, U6.16
/VRAM/RD5: U1.27, U3.14, U6.17
/VRAM/RD6: U1.26, U3.13, U6.18
/VRAM/RD7: U1.25, U3.12, U6.19
GND: C1.2, C2.2, C3.2, C4.2, C5.2, C6.2, C7.2, C8.2, C9.2, C11.2, J1.41, J1.43, J2.2, J3.2, J4.2, R1.2, U1.12, U2.7, U3.10, U4.1, U4.10, U5.1, U5.10, U6.1, U6.14, U7.7, U7.9, U7.10, U7.12, U7.13
unnamed: C1.1, U1.40, Y1.1
unnamed: C2.1, U1.39, Y1.2
unnamed: J1.44, J1.46
unnamed: U2.6, U4.11
unnamed: U2.10, U2.13
unnamed: U2.8, U2.11
unnamed: U2.12, U5.11
~: C3.1, C4.1, C5.1, C6.1, C7.1, C8.1, C9.1, C11.1, J1.7, J1.45, J1.47, U1.33, U2.14, U3.20, U4.20, U5.20, U6.28, U7.14

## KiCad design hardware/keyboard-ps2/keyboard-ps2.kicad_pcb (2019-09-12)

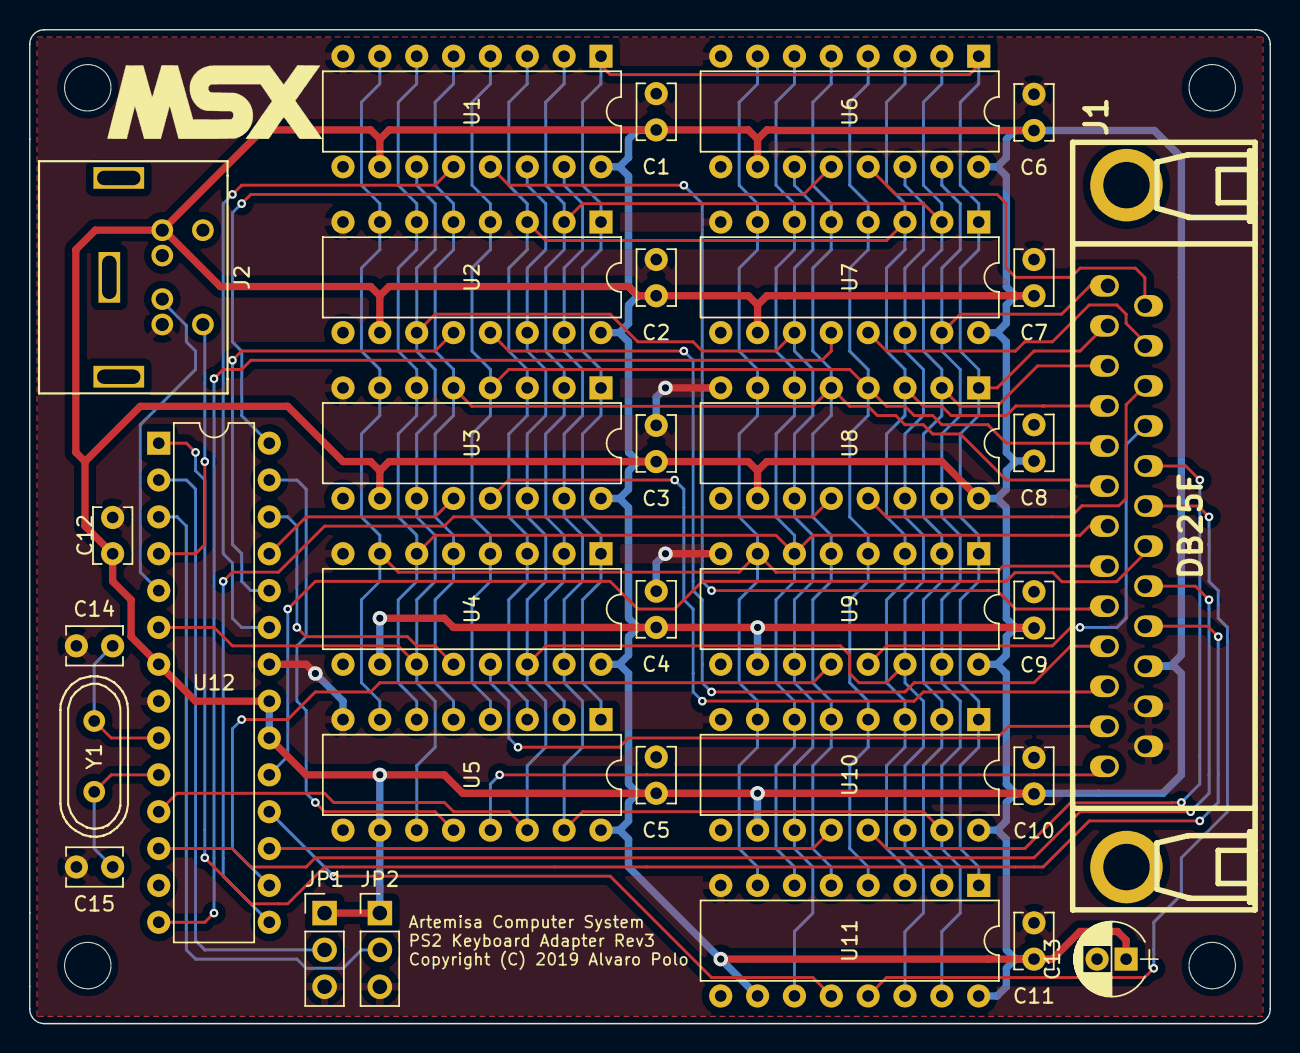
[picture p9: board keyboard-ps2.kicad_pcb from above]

Board: 2 copper layers, 85.5 x 68.5 mm, 32 parts (0 on the bottom side), 43 nets.

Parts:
C1, C2, C3, C4, C5, C6, C7, C8, C9, C10, C11, C12: 100nF; Disc_capacitor
C13: 10uF; Radial_capacitor
C14, C15: 33pF; Disc_capacitor
J1: DB25F
J2: PS2_CONN; PS2_conn
JP1, JP2: Jumper
U1, U2, U3, U4, U5, U6, U7, U8, U9, U10, U11: 74HC595; DIP-16_300
U12: ATMEGA328P; DIP-28_300
Y1: 16Mhz; Crystal

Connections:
/DS: U1.14, U2.14, U3.14, U4.14, U5.14, U6.14, U7.14, U8.14, U9.14, U10.14, U11.14, U12.11
/KBCOL0: J1.1, U1.15, U2.15, U3.15, U4.15, U5.15, U6.15, U7.15, U8.15, U9.15, U10.15, U11.15
/KBCOL1: J1.2, U1.1, U2.1, U3.1, U4.1, U5.1, U6.1, U7.1, U8.1, U9.1, U10.1, U11.1
/KBCOL2: J1.3, U1.2, U2.2, U3.2, U4.2, U5.2, U6.2, U7.2, U8.2, U9.2, U10.2, U11.2
/KBCOL3: J1.4, U1.3, U2.3, U3.3, U4.3, U5.3, U6.3, U7.3, U8.3, U9.3, U10.3, U11.3
/KBCOL4: J1.5, U1.4, U2.4, U3.4, U4.4, U5.4, U6.4, U7.4, U8.4, U9.4, U10.4, U11.4
/KBCOL5: J1.6, U1.5, U2.5, U3.5, U4.5, U5.5, U6.5, U7.5, U8.5, U9.5, U10.5, U11.5
/KBCOL6: J1.7, U1.6, U2.6, U3.6, U4.6, U5.6, U6.6, U7.6, U8.6, U9.6, U10.6, U11.6
/KBCOL7: J1.8, U1.7, U2.7, U3.7, U4.7, U5.7, U6.7, U7.7, U8.7, U9.7, U10.7, U11.7
/SHCP: U1.11, U2.11, U3.11, U4.11, U5.11, U6.11, U7.11, U8.11, U9.11, U10.11, U11.11, U12.6
/STCP0: U1.12, U12.23
/STCP1: U2.12, U12.24
/STCP2: U3.12, U12.25
/STCP3: U4.12, U12.26
/STCP4: U5.12, U12.27
/STCP5: U6.12, U12.28
/STCP6: U7.12, U12.14
/STCP7: U8.12, U12.15
/STCP8: U9.12, U12.16
/STCP9: U10.12, U12.17
/STCP10: U11.12, U12.18
/~CAPSLOCK: J1.20, U12.19
/~KANALOCK: J1.21, U12.12
/~RESET: J1.22, U12.1
/~RSL0: J1.9, U1.13
/~RSL1: J1.10, U2.13
/~RSL2: J1.11, U3.13
/~RSL3: J1.12, U4.13
/~RSL4: J1.13, U5.13
/~RSL5: J1.14, U6.13
/~RSL6: J1.15, U7.13
/~RSL7: J1.16, U8.13
/~RSL8: J1.17, U9.13
/~RSL9: J1.18, U10.13
/~RSL10: J1.19, U11.13
GND: C1.2, C2.2, C3.2, C4.2, C5.2, C6.2, C7.2, C8.2, C9.2, C10.2, C11.2, C12.2, C13.2, C14.2, C15.2, J1.24, J1.25, J2.3, JP1.3, JP2.3, U1.8, U2.8, U3.8, U4.8, U5.8, U6.8, U7.8, U8.8, U9.8, U10.8, U11.8, U12.8, U12.22
unnamed: C14.1, U12.9, Y1.1
unnamed: C15.1, U12.10, Y1.2
unnamed: J2.1, U12.5
unnamed: J2.5, U12.4
unnamed: JP1.2, U12.2
unnamed: JP2.2, U12.3
~: C1.1, C2.1, C3.1, C4.1, C5.1, C6.1, C7.1, C8.1, C9.1, C10.1, C11.1, C12.1, C13.1, J1.23, J2.4, JP1.1, JP2.1, U1.10, U1.16, U2.10, U2.16, U3.10, U3.16, U4.10, U4.16, U5.10, U5.16, U6.10, U6.16, U7.10, U7.16, U8.10, U8.16, U9.10, U9.16, U10.10, U10.16, U11.10, U11.16, U12.7, U12.20, U12.21

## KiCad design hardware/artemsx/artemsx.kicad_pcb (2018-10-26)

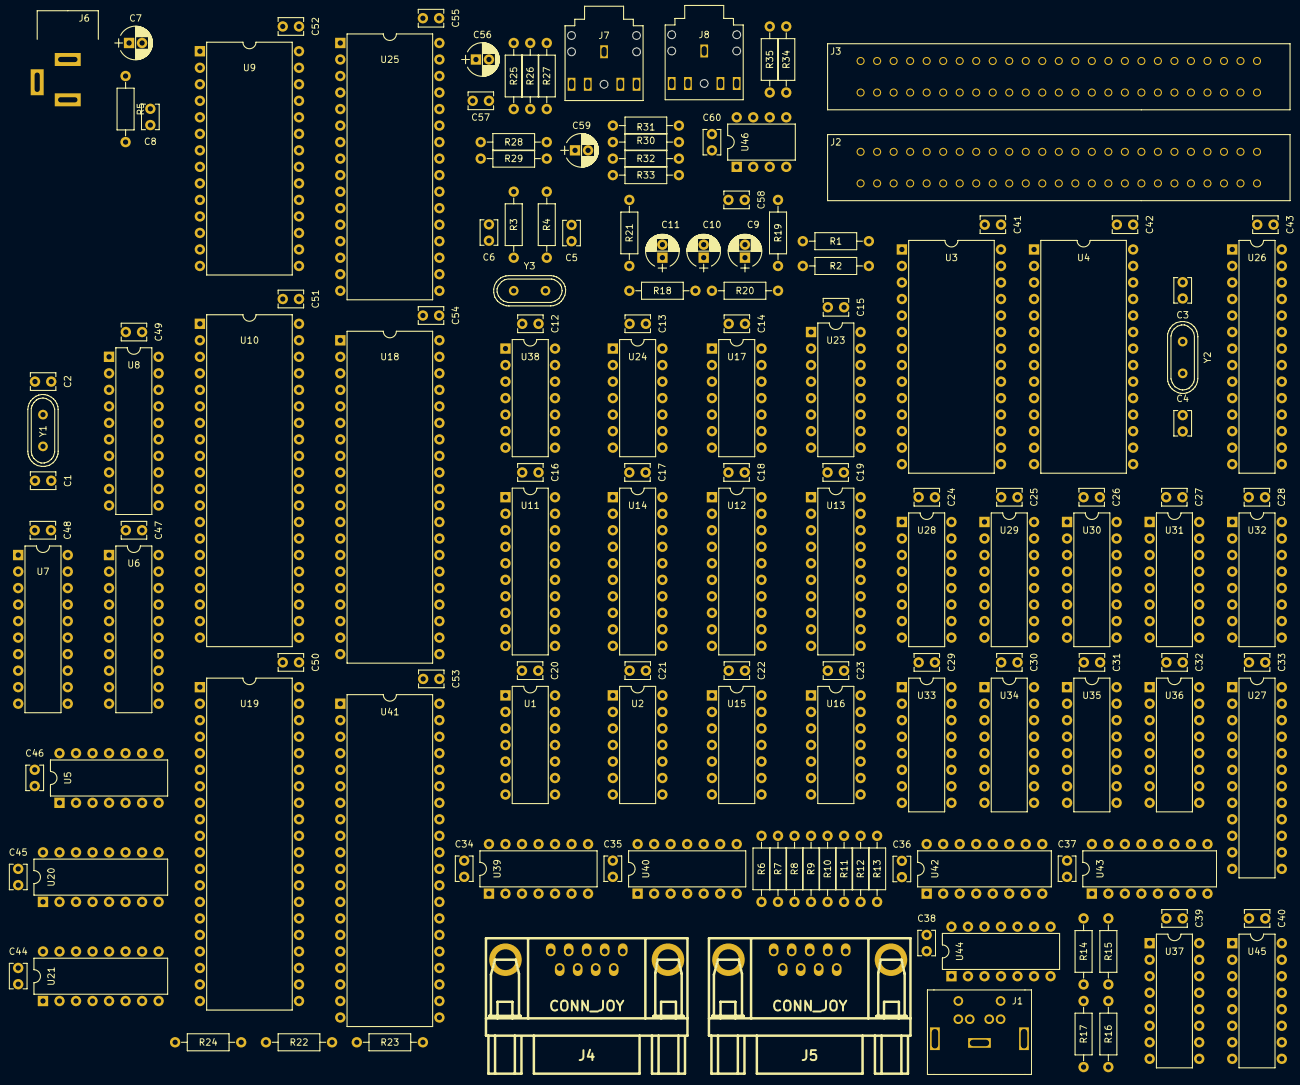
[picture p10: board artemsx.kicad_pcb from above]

Board: 2 copper layers, 151 parts (0 on the bottom side), 249 nets, no tracks yet.

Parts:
C1, C2: 27pF; Disc_capacitor
C3, C4, C5, C6, C8, C12, C13, C14, C15, C16, C17, C18, C19, C20, C21, C22, C23, C24, C25, C26, C27, C28, C29, C30, C31, C32, C33, C34, C35, C36, C37, C38, C39, C40, C41, C42, C43, C44, C45, C46, C47, C48, C49, C50, C51, C52, C53, C54, C55, C60: 22pF; Disc_capacitor
C7, C56, C59: 1uF; Radial_capacitor
C9, C10, C11: 10u; Radial_capacitor
C57, C58: 22nF; Disc_capacitor
J1: PS2_CONN; PS2_conn
J2, J3: MSX_Slot; Slot_conn
J4, J5: CONN_JOY; Joystick_conn
J6: PWR_conn; Jack_55_21
J7, J8: Audio_conn; Jack_conn
R1, R2, R5, R6, R7, R8, R9, R10, R11, R12, R13, R14, R15, R16, R17, R22, R23, R24: 10K; Axial_resistor
R3: 1M; Axial_resistor
R4: 1K; Axial_resistor
R18: 470; Axial_resistor
R19: 20k; Axial_resistor
R20, R25, R26, R31: 4k7; Axial_resistor
R21, R28, R29: 2k7; Axial_resistor
R27: 100; Axial_resistor
R30, R34: 10k; Axial_resistor
R32: 220k; Axial_resistor
R33: 1k; Axial_resistor
R35: 470k; Axial_resistor
U1, U17, U24, U44: 74HC32; DIP-14_300
U2: 74HC04; DIP-14_300
U3, U4, U9: HM62256ALP-10; DIP-28_600
U5: 74HCT04; DIP-14_300
U6, U7, U8: 74HCT574; DIP-20_300
U10: TMS99x8; DIP-40_600
U11, U12, U14: 74HCT244; DIP-20_300
U13: 74HCT245; DIP-20_300
U15, U40: 74HC74; DIP-14_300
U16: 74HC08; DIP-14_300
U18: Z84C00; DIP-40_600
U19: 82C55A; DIP-40_600
U20: 74HC153; DIP-16_300
U21: 74HC139; DIP-16_300
U23: 74HC138; DIP-16_300
U25: SST39SF0x0; DIP-32_600
U26: ATMEGA328P; DIP-28_300
U27: 74HC154; DIP-24_300
U28, U29, U30, U31, U32, U33, U34, U35, U36, U37, U45: 74HC595; DIP-16_300
U38: 4069; DIP-14_300
U39: 74HC07; DIP-14_300
U41: AY-3-8910; DIP-40_600
U42, U43: 74HC157; DIP-16_300
U46: LM311; DIP-8_300
Y1: 10.7386Mhz; Crystal
Y2: 16Mhz; Crystal
Y3: 3.58Mhz; Crystal

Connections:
/ADDR0: J2.28, J3.28, U3.10, U4.10, U10.13, U11.18, U24.12, U25.12
/ADDR1: J2.27, J3.27, U3.9, U4.9, U11.16, U25.11, U38.13, U44.2
/ADDR3: J2.29, J3.29, U3.7, U4.7, U11.12, U23.1, U25.9
/ADDR4: J2.32, J3.32, U3.6, U4.6, U11.9, U23.2, U25.8
/ADDR5: J2.31, J3.31, U3.5, U4.5, U11.7, U23.3, U25.7
/ADDR6: J2.22, J3.22, U3.4, U4.4, U11.5, U24.2, U25.6
/ADDR7: J2.21, J3.21, U2.9, U3.3, U4.3, U11.3, U25.5
/ADDR14: J2.25, J3.25, U3.1, U4.1, U12.5, U19.9, U20.14, U21.14, U25.29
/ADDR15: J2.18, J3.18, U1.2, U2.1, U12.3, U19.8, U20.2, U21.13, U25.3
/AUDIO: R19.2, R20.2, R21.2
/BEEP: C9.1, U19.10
/CASIN: C58.2, U41.14
/CASOUT: C56.1, U19.12
/CLK: U2.12, U15.3, U15.11, U18.6, U40.3, U44.9, U44.10
/CPU/A0: U11.2, U18.30
/CPU/A1: U11.4, U18.31
/CPU/A2: U11.6, U18.32
/CPU/A3: U11.8, U18.33
/CPU/A4: U11.11, U18.34
/CPU/A5: U11.13, U18.35
/CPU/A6: U11.15, U18.36
/CPU/A7: U11.17, U18.37
/CPU/A8: U12.2, U18.38
/CPU/A9: U12.4, U18.39
/CPU/A10: U12.6, U18.40
/CPU/A11: U12.8, U18.1
/CPU/A12: U12.11, U18.2
/CPU/A13: U12.13, U18.3
/CPU/A14: U12.15, U18.4
/CPU/A15: U12.17, U18.5
/CPU/ADDR2: J2.30, J3.30, U3.8, U4.8, U11.14, U25.10
/CPU/ADDR8: J2.24, J3.24, U3.25, U4.25, U12.18, U25.27
/CPU/ADDR9: J2.17, J3.17, U3.24, U4.24, U12.16, U25.26
/CPU/ADDR10: J2.20, J3.20, U3.21, U4.21, U12.14, U25.23
/CPU/ADDR11: J2.19, J3.19, U3.23, U4.23, U12.12, U25.25
/CPU/ADDR12: J2.23, J3.23, U3.2, U4.2, U12.9, U25.4
/CPU/ADDR13: J2.26, J3.26, U3.26, U4.26, U12.7, U25.28
/CPU/D0: U13.2, U18.14
/CPU/D1: U13.3, U18.15
/CPU/D2: U13.4, U18.12
/CPU/D3: U13.5, U18.8
/CPU/D4: U13.6, U18.7
/CPU/D5: U13.7, U18.9
/CPU/D6: U13.8, U18.10
/CPU/D7: U13.9, U18.13
/CPU/DATA0: J2.34, J3.34, U3.11, U4.11, U10.24, U13.18, U19.34, U25.13, U41.37
/CPU/DATA1: J2.33, J3.33, U3.12, U4.12, U10.23, U13.17, U19.33, U25.14, U41.36
/CPU/DATA2: J2.36, J3.36, U3.13, U4.13, U10.22, U13.16, U19.32, U25.15, U41.35
/CPU/DATA3: J2.35, J3.35, U3.15, U4.15, U10.21, U13.15, U19.31, U25.17, U41.34
/CPU/DATA4: J2.38, J3.38, U3.16, U4.16, U10.20, U13.14, U19.30, U25.18, U41.33
/CPU/DATA5: J2.37, J3.37, U3.17, U4.17, U10.19, U13.13, U19.29, U25.19, U41.32
/CPU/DATA6: J2.40, J3.40, U3.18, U4.18, U10.18, U13.12, U19.28, U25.20, U41.31
/CPU/DATA7: J2.39, J3.39, U3.19, U4.19, U10.17, U13.11, U19.27, U25.21, U41.30
/CPU/~INT: U16.3, U18.16
/KBD/DS: U26.11, U28.14, U29.14, U30.14, U31.14, U32.14, U33.14, U34.14, U35.14, U36.14, U37.14, U45.14
/KBD/KBCOL0: U19.18, U28.15, U29.15, U30.15, U31.15, U32.15, U33.15, U34.15, U35.15, U36.15, U37.15, U45.15
/KBD/KBCOL1: U19.19, U28.1, U29.1, U30.1, U31.1, U32.1, U33.1, U34.1, U35.1, U36.1, U37.1, U45.1
/KBD/KBCOL2: U19.20, U28.2, U29.2, U30.2, U31.2, U32.2, U33.2, U34.2, U35.2, U36.2, U37.2, U45.2
/KBD/KBCOL3: U19.21, U28.3, U29.3, U30.3, U31.3, U32.3, U33.3, U34.3, U35.3, U36.3, U37.3, U45.3
/KBD/KBCOL4: U19.22, U28.4, U29.4, U30.4, U31.4, U32.4, U33.4, U34.4, U35.4, U36.4, U37.4, U45.4
/KBD/KBCOL5: U19.23, U28.5, U29.5, U30.5, U31.5, U32.5, U33.5, U34.5, U35.5, U36.5, U37.5, U45.5
/KBD/KBCOL6: U19.24, U28.6, U29.6, U30.6, U31.6, U32.6, U33.6, U34.6, U35.6, U36.6, U37.6, U45.6
/KBD/KBCOL7: U19.25, U28.7, U29.7, U30.7, U31.7, U32.7, U33.7, U34.7, U35.7, U36.7, U37.7, U45.7
/KBD/KBROW0: U19.14, U27.23
/KBD/KBROW1: U19.15, U27.22
/KBD/KBROW2: U19.16, U27.21
/KBD/KBROW3: U19.17, U27.20
/KBD/SHCP: U26.6, U28.11, U29.11, U30.11, U31.11, U32.11, U33.11, U34.11, U35.11, U36.11, U37.11, U45.11
/KBD/STCP0: U26.23, U28.12
/KBD/STCP1: U26.24, U29.12
/KBD/STCP2: U26.25, U30.12
/KBD/STCP3: U26.26, U31.12
/KBD/STCP4: U26.27, U32.12
/KBD/STCP5: U26.28, U33.12
/KBD/STCP6: U26.14, U34.12
/KBD/STCP7: U26.15, U35.12
/KBD/STCP8: U26.16, U36.12
/KBD/STCP9: U26.17, U37.12
/KBD/STCP10: U26.18, U45.12
/KBD/~RSL0: U27.1, U28.13
/KBD/~RSL1: U27.2, U29.13
/KBD/~RSL2: U27.3, U30.13
/KBD/~RSL3: U27.4, U31.13
/KBD/~RSL4: U27.5, U32.13
/KBD/~RSL5: U27.6, U33.13
/KBD/~RSL6: U27.7, U34.13
/KBD/~RSL7: U27.8, U35.13
/KBD/~RSL8: U27.9, U36.13
/KBD/~RSL9: U27.10, U37.13
/KBD/~RSL10: U27.11, U45.13
/PPI/PA0: U19.4, U20.6
/PPI/PA1: U19.3, U20.10
/PPI/PA2: U19.2, U20.5
/PPI/PA3: U19.1, U20.11
/PPI/PA4: U19.40, U20.4
/PPI/PA5: U19.39, U20.12
/PPI/PA6: U19.38, U20.3
/PPI/PA7: U19.37, U20.13
/PSG/IOA0: U41.21, U42.4
/PSG/IOA1: U41.20, U42.7
/PSG/IOA2: U41.19, U42.9
/PSG/IOA3: U41.18, U42.12
/PSG/IOA4: U41.17, U43.4
/PSG/IOA5: U41.16, U43.7
/PSG/IOB0: U39.1, U41.13
/PSG/IOB1: U39.3, U41.12
/PSG/IOB2: U39.5, U41.11
/PSG/IOB3: U39.9, U41.10
/PSG/IOB4: J4.8, U41.9
/PSG/IOB5: J5.8, U41.8
/PSG/IOB6: U41.7, U42.1, U43.1
/PSG/JOYA1: J4.1, R13.2, U42.2
/PSG/JOYA2: J4.2, R12.2, U42.5
/PSG/JOYA3: J4.3, R11.2, U42.11
/PSG/JOYA4: J4.4, R10.2, U42.14
/PSG/JOYA6: J4.6, R17.1, U39.8, U43.2
/PSG/JOYA7: J4.7, R16.1, U39.6, U43.5
/PSG/JOYB1: J5.1, R9.2, U42.3
/PSG/JOYB2: J5.2, R8.2, U42.6
/PSG/JOYB3: J5.3, R7.2, U42.10
/PSG/JOYB4: J5.4, R6.2, U42.13
/PSG/JOYB6: J5.6, R15.1, U39.4, U43.3
/PSG/JOYB7: J5.7, R14.1, U39.2, U43.6
/SLOTS/EXTCLK: J2.42, J3.42, U44.8
/SLOTS/~EXTRESET: J2.15, J3.15, U44.11
/SOUND: C10.1, J2.49, J3.49
/VDP/AD0: U6.2, U7.2, U8.2, U10.10
/VDP/AD1: U6.3, U7.3, U8.3, U10.9
/VDP/AD2: U6.4, U7.4, U8.4, U10.8
/VDP/AD3: U6.5, U7.5, U8.5, U10.7
/VDP/AD4: U6.6, U7.6, U8.6, U10.6
/VDP/AD5: U6.7, U7.7, U8.7, U10.5
/VDP/AD6: U6.8, U7.8, U8.8, U10.4
/VDP/AD7: U6.9, U7.9, U8.9, U10.3
/VDP/COL: U5.12, U8.11
/VDP/RD: U5.4, U6.1, U9.27
/VDP/ROW: U5.6, U7.11
/VDP/VD0: U6.19, U9.11, U10.32
/VDP/VD1: U6.18, U9.12, U10.31
/VDP/VD2: U6.17, U9.13, U10.30
/VDP/VD3: U6.16, U9.15, U10.29
/VDP/VD4: U6.15, U9.16, U10.28
/VDP/VD5: U6.14, U9.17, U10.27
/VDP/VD6: U6.13, U9.18, U10.26
/VDP/VD7: U6.12, U9.19, U10.25
/VDP/WR: U5.2, U5.3, U6.11, U9.22
/VDP/~CAS: U5.9, U9.20, U10.2
/VDP/~CSR: U1.11, U10.15
/VDP/~CSW: U1.8, U10.14
/VDP/~RAS: U5.5, U10.1
/~CS1: J2.1, J3.1, U16.10, U21.11
/~CS2: J2.2, J3.2, U16.9, U21.10
/~CS12: J2.3, J3.3, U16.8
/~EXTINT: J2.8, J3.8, R1.2, U16.1
/~EXTWAIT: J2.7, J3.7, R2.2, U15.1, U15.10
/~IORQ: J2.11, J3.11, U14.14, U17.1, U23.5
/~IOSL3: U1.10, U1.12, U23.12
/~IOSL4: U23.11, U24.10, U44.1
/~IOSL5: U17.5, U17.9, U23.10, U40.10
/~M1: J2.9, J3.9, U14.18, U15.2, U17.2, U23.6
/~MREQ: J2.12, J3.12, U14.16, U17.12
/~RD: J2.14, J3.14, U1.13, U3.22, U4.22, U14.9, U16.4, U17.4, U21.15, U24.4, U25.24
/~RESET: C8.1, U2.3, U10.34, U18.26, U26.1, U38.4, U40.13, U41.23, U44.12, U44.13
/~RFSH: J2.6, J3.6, U2.5, U14.5
/~SLTSL0: U21.4, U25.22
/~SLTSL1: U1.1, U1.4, U21.5
/~SLTSL2: J2.4, U21.6
/~SLTSL3: J3.4, U21.7
/~VDPINT: U10.16, U16.2
/~WR: J2.13, J3.13, U1.9, U3.27, U4.27, U14.7, U17.10, U44.5
GND: C1.2, C2.2, C3.2, C4.2, C5.2, C6.2, C7.2, C8.2, C12.2, C13.2, C14.2, C15.2, C16.2, C17.2, C18.2, C19.2, C20.2, C21.2, C22.2, C23.2, C24.2, C25.2, C26.2, C27.2, C28.2, C29.2, C30.2, C31.2, C32.2, C33.2, C34.2, C35.2, C36.2, C37.2, C38.2, C39.2, C40.2, C41.2, C42.2, C43.2, C44.2, C45.2, C46.2, C47.2, C48.2, C49.2, C50.2, C51.2, C52.2, C53.2, C54.2, C55.2, C57.2, C59.2, C60.2, J1.3, J2.41, J2.43, J2.48, J2.50, J3.41, J3.43, J3.48, J3.50, J4.9, J5.9, J6.2, J6.3, J7.1, J8.1, R18.2, R22.2, R23.2, R24.1, R27.1, R29.1, U1.7, U2.7, U3.14, U4.14, U5.7, U6.10, U7.1, U7.10, U8.1, U8.10, U9.1, U9.14, U10.12, U11.1, U11.10, U11.19, U12.1, U12.10, U12.19, U13.10, U13.19, U14.1, U14.8, U14.10, U14.17, U14.19, U15.7, U16.7, U17.7, U18.29, U19.6, U19.7, U20.8, U21.8, U23.8, U24.7, U25.1, U25.2, U25.16, U25.30, U26.8, U26.22, U27.12, U27.18, U27.19, U28.8, U29.8, U30.8, U31.8, U32.8, U33.8, U34.8, U35.8, U36.8, U37.8, U38.7, U39.7, U40.7, U40.11, U40.12, U41.1, U41.24, U42.8, U42.15, U43.8, U43.10, U43.11, U43.13, U43.14, U43.15, U44.7, U45.8, U46.1, U46.4
unnamed: C1.1, U10.40, Y1.1
unnamed: C2.1, U10.39, Y1.2
unnamed: C3.1, U26.9, Y2.1
unnamed: C4.1, U26.10, Y2.2
unnamed: C5.1, R4.2, Y3.2
unnamed: C6.1, R3.2, U38.5, Y3.1
unnamed: C7.1, R5.2, U38.1
unnamed: C9.2, R19.1
unnamed: C10.2, R20.1
unnamed: C11.1, R18.1, U41.3, U41.4, U41.38
unnamed: C11.2, R21.1
unnamed: C56.2, R25.2
unnamed: C57.1, R25.1, R26.2
unnamed: C58.1, R34.1
unnamed: C59.1, R28.1, R29.2, R30.2, R31.1
unnamed: J1.1, U26.5
unnamed: J1.5, U26.4
unnamed: J7.2, R26.1, R27.2
unnamed: J8.2, R32.2, R33.1, U46.7
unnamed: R3.1, R4.1, U38.6, U38.9
unnamed: R22.1, U41.6
unnamed: R23.1, U41.15
unnamed: R30.1, R34.2, R35.1, U46.3
unnamed: R31.2, R32.1, U46.2
unnamed: U1.3, U3.20
unnamed: U1.5, U2.2
unnamed: U1.6, U4.20
unnamed: U2.8, U24.1
unnamed: U2.10, U41.29
unnamed: U2.13, U38.8
unnamed: U5.10, U5.13
unnamed: U5.8, U5.11
unnamed: U7.12, U9.4
unnamed: U7.13, U9.5
unnamed: U7.14, U9.6
unnamed: U7.15, U9.7
unnamed: U7.16, U9.8
unnamed: U7.17, U9.9
unnamed: U7.18, U9.10
unnamed: U8.12, U9.26
unnamed: U8.13, U9.2
unnamed: U8.14, U9.23
unnamed: U8.15, U9.21
unnamed: U8.16, U9.24
unnamed: U8.17, U9.25
unnamed: U8.18, U9.3
unnamed: U5.1, U10.11
unnamed: U13.1, U16.6
unnamed: U14.2, U18.27
unnamed: U14.4, U18.19
unnamed: U14.6, U18.20
unnamed: U14.11, U18.21
unnamed: U14.13, U18.22
unnamed: U14.15, U18.28
unnamed: U15.4, U15.9
unnamed: U15.5, U15.12, U18.24
unnamed: U16.5, U17.3
unnamed: U2.11, U16.11
unnamed: U16.12, U24.8
unnamed: U16.13, U24.11
unnamed: U17.6, U19.5
unnamed: U17.8, U19.36
unnamed: U17.11, U21.1
unnamed: U2.6, U17.13
unnamed: U2.4, U19.35
unnamed: U20.1, U20.15, U40.8
unnamed: U20.7, U21.2
unnamed: U20.9, U21.3
unnamed: U23.4, U24.3
unnamed: U24.5, U38.12
unnamed: U24.6, U24.9
unnamed: U24.13, U38.11, U44.6
unnamed: U38.2, U38.3
unnamed: U38.10, U41.27
unnamed: U40.2, U40.6
unnamed: U40.5, U41.22
unnamed: U44.3, U44.4
VCC: C12.1, C13.1, C14.1, C15.1, C16.1, C17.1, C18.1, C19.1, C20.1, C21.1, C22.1, C23.1, C24.1, C25.1, C26.1, C27.1, C28.1, C29.1, C30.1, C31.1, C32.1, C33.1, C34.1, C35.1, C36.1, C37.1, C38.1, C39.1, C40.1, C41.1, C42.1, C43.1, C44.1, C45.1, C46.1, C47.1, C48.1, C49.1, C50.1, C51.1, C52.1, C53.1, C54.1, C55.1, C60.1, J1.4, J2.45, J2.47, J3.45, J3.47, J4.5, J5.5, J6.1, R1.1, R2.1, R5.1, R6.1, R7.1, R8.1, R9.1, R10.1, R11.1, R12.1, R13.1, R14.2, R15.2, R16.2, R17.2, R28.2, R33.2, R35.2, U1.14, U2.14, U3.28, U4.28, U5.14, U6.20, U7.20, U8.20, U9.28, U10.33, U11.20, U12.20, U13.20, U14.20, U15.13, U15.14, U16.14, U17.14, U18.11, U18.17, U18.25, U19.26, U20.16, U21.16, U23.16, U24.14, U25.31, U25.32, U26.7, U26.20, U26.21, U27.24, U28.10, U28.16, U29.10, U29.16, U30.10, U30.16, U31.10, U31.16, U32.10, U32.16, U33.10, U33.16, U34.10, U34.16, U35.10, U35.16, U36.10, U36.16, U37.10, U37.16, U38.14, U39.11, U39.13, U39.14, U40.1, U40.4, U40.14, U41.25, U41.28, U41.40, U42.16, U43.16, U44.14, U45.10, U45.16, U46.8

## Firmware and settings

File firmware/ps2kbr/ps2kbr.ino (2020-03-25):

// Artemisa Computer System
// PS2 keyboard matrix emulator
// Copyright (C) 2018-2019 Alvaro Polo
//
// This is an Arduino sketch that implements the firmware of the keyboard
// matrix emulator used in the Artemisa Computer System. The purpose of
// this firmware is to adapt the PS2 interface of a modern keyboard and
// expose it to the MSX as a old-school keyboard matrix.
//
// It does so by using a network of 74HC595 ICs connected to an ATmega328
// microcontroller. The 595 network will operate as a sort of small and
// unexpensive dual-port memory based upon serial-to-parallel shift registers.
// The ATmega will write bytes into it using the serial interface (write port),
// while the MSX PPI will read the bytes using the parallel interface (read
// port). Each 595 stores 8-bits, representing a single row of the MSX keyboard
// matrix. Using a total of eleven 595s you can represent the whole keyboard
// matrix.
//

// This macro, when declared, activates the debug mode using the serial port of the Arduino board.
// There is another PS2_DEBUG macro that controls the low level debugging in the PS2 library.
// You can comment and uncomment this to disable and enable debug, respectively.
// #define DEBUG 1

// The custom PS2 library made by Artemisa project.
#include "ps2.h"

// The mappings between PS2 scancodes and MSX matrix positions
#include "mapping.h"

// The Arduino pin where PS2 DATA is connected.
#define PS2_PIN_DATA     3 // ATmega328 pin #5 (PD3/INT1)

// The Arduino pin where PS2 CLOCK is connected.
// Note: this MUST be connected to an interrupt pin.
#define PS2_PIN_CLK      2 // ATmega328 pin #4 (PD2/INT0)

// The Arduino pin where matrix DS line is connected.
#define MATRIX_PIN_DS    5 // ATmega328 pin #11 (PD5)

// The Arduino pin where matrix SHCP line is connected.
#define MATRIX_PIN_SHCP  4 // ATmega328 pin #6 (PD4)

// The Arduino pin where CAPSLOCK line is connected.
#define KANALOCK_PIN     6 // ATmega328 pin #12 (PD6)

// The Arduino pin where CAPSLOCK line is connected.
#define CAPSLOCK_PIN     13 // ATmega328 pin #19 (PB5/SCLK)

// How many rows of MSX matrix we will emulate
#define MATRIX_NROWS     11

// What is the maximum scancode from PS2 keyboard we will process
#define KEYCODE_MAX      0xa0

// An array that indicates the Arduino pins where each matrix row STCP signal
// is connected.
const int outputs[MATRIX_NROWS] = {
  A0, // STCP0, ATmega328 pin #23 (PC0)
  A1, // STCP1, ATmega328 pin #24 (PC1)
  A2, // STCP2, ATmega328 pin #25 (PC2)
  A3, // STCP3, ATmega328 pin #26 (PC3)
  A4, // STCP4, ATmega328 pin #27 (PC4)
  A5, // STCP5, ATmega328 pin #28 (PC5)
  8,  // STCP6, ATmega328 pin #14 (PB0)
  9,  // STCP7, ATmega328 pin #15 (PB1)
  10, // STCP8, ATmega328 pin #16 (PB2/SS)
  11, // STCP9, ATmega328 pin #17 (PB3/MOSI)
  12, // STCP10, ATmega328 pin #18 (PB4/MISO)
};

// An array that maintains the state of the MSX matrix.
// Each item represents the n-th row of the matrix. Each row has 8 columns,
// each one represented by one bit in each entry of this array.
byte matrix[MATRIX_NROWS];

// The PS2 port
PS2Port ps2;

// Initialize the IO pins
void init_iopins() {
  // The pin used to transmit the serial data
  pinMode(MATRIX_PIN_DS, OUTPUT);
  digitalWrite(MATRIX_PIN_DS, 0);

  // The pin used to transmit shift clock.
  pinMode(MATRIX_PIN_SHCP, OUTPUT);
  digitalWrite(MATRIX_PIN_SHCP, 0);

  // The pins used to transmit storage register clock to each 595.
  for (int i = 0; i < MATRIX_NROWS; i++) {
    pinMode(outputs[i], OUTPUT);
    digitalWrite(outputs[i], LOW);
  }

  // The pins used to read CAPSLOCK and KANALOCK signals
  pinMode(CAPSLOCK_PIN, INPUT_PULLUP);
  pinMode(KANALOCK_PIN, INPUT_PULLUP);
}

// Initialize the matrix
void init_matrix() {
  byte value = 0xff; // all 1s means unpressed
  for (int i = 0; i < MATRIX_NROWS; i++) {
    matrix[i] = value;
  }
  write_all_rows(value);
}

// Shift the given value to all 595s.
// Note this just shifts the value. It will not latch it.
void shift_value(byte value) {
  shiftOut(MATRIX_PIN_DS, MATRIX_PIN_SHCP, MSBFIRST, value);
}

// Latch the previously shifted value to 595 that governs the given row.
void latch_row(int row) {
  digitalWrite(outputs[row], HIGH);
  delayMicroseconds(10);
  digitalWrite(outputs[row], LOW);
}

// Write the given value for the given row.
// This shifts the value and sends the latch signal to the 595 that governs
// that row.
void write_row(int row, byte value) {
  shift_value(value);
  latch_row(row);
}

// Write the given value to all rows
void write_all_rows(byte value) {
  // We want each 595 to be loaded with value. To do that, we shift it to all
  // registers and then we send a latch signal to each 595.
  shift_value(value);
  for (int i = 0; i < MATRIX_NROWS; i++) {
    latch_row(i);
  }
}

void reset_keyboard() {
  PS2Result err = ps2.send_cmd_reset();
  if (err != PS2Result::OK) {
#ifdef DEBUG
    Serial.print(F("Error: reset command failed with code "));
    Serial.println(err, HEX);
#endif
  }
}

void setup_ps2_keyboard() {
  ps2.begin(PS2_PIN_DATA, PS2_PIN_CLK);
  reset_keyboard();
}

void process_locks(bool force = false) {
  static uint8_t locks = 0;

  uint8_t prev = locks;
  if (digitalRead(CAPSLOCK_PIN)) locks &= ~PS2_LED_CAPSLOCK;
  else locks |= PS2_LED_CAPSLOCK;

  // TODO: not all keyboards support Kana Lock LED and refuse this bit.
  // if (digitalRead(KANALOCK_PIN)) locks &= ~PS2_LED_KANALOCK;
  // else locks |= PS2_LED_KANALOCK;

  if (force || (prev != locks)) {
    ps2.send_cmd_leds(locks);
  }
}

bool handle_special_scancode(const PS2Scancode &sc) {
  switch (sc.keycode()) {
    case PS2_KEYCODE_SELFTEST_PASSED:
      process_locks(true);
      return true;
  }
  return false;
}

void handle_scancode(const PS2Scancode &sc) {
  if (handle_special_scancode(sc)) {
    return;
  }

  mapping m = map_scancodes(sc);
  if (m.row == -1) {
    // There is no mapping defined for that scancode. Skip it.
    return;
  }

  byte r = matrix[m.row];
  if (sc.is_break()) {
    bitSet(r, m.offset);
  } else {
    bitClear(r, m.offset);
  }

  if (r != matrix[m.row]) {
    // We detected a change in the row. Something was pressed or released!
#ifdef DEBUG
    //Serial.print(F("Row changed: "));
    //Serial.print(m.row);
    //Serial.print(F("="));
    //Serial.println(r, BIN);
#endif
    matrix[m.row] = r;
    write_row(m.row, r);
  }
}

void process_scancodes() {
  PS2Scancode sc;
  PS2Result res = ps2.receive_scancode(sc);
  if (res != PS2Result::OK) {
#ifdef DEBUG
    Serial.print(F("+RCVERR:"));
    Serial.println(res, HEX);
    return;
#endif
  }
  if (!sc.is_null()) {
    handle_scancode(sc);
  }
}

// Setup the microcontroller
void setup() {
#ifdef DEBUG
  Serial.begin(57600);
  Serial.println( F( "PS2 Keyboard Adapter board" ) );
#endif

  setup_ps2_keyboard();
  init_iopins();
  init_matrix();
}

// Main loop of the microcontroller
void loop() {
  process_scancodes();
  process_locks();
}

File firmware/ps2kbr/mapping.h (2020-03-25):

#ifndef MAPPING_H
#define MAPPING_H

#include "ps2.h"

// A struct that describes the mapping between some scancode of the PS2
// keyboard and a key in the MSX keyboard.
struct mapping {
  // The row of that key in the MSX matrix
  int row;
  // The column of the key in the MSX matrix
  int offset;
};

// Some definitions of the MSX keyboard matrix coordinates
#define MATRIX_NULL           { -1, -1 }

#define MATRIX_INT_0          {  0,  0 }
#define MATRIX_INT_1          {  0,  1 }
#define MATRIX_INT_2          {  0,  2 }
#define MATRIX_INT_3          {  0,  3 }
#define MATRIX_INT_4          {  0,  4 }
#define MATRIX_INT_5          {  0,  5 }
#define MATRIX_INT_6          {  0,  6 }
#define MATRIX_INT_7          {  0,  7 }
#define MATRIX_INT_8          {  1,  0 }
#define MATRIX_INT_9          {  1,  1 }
#define MATRIX_INT_MINUS      {  1,  2 }
#define MATRIX_INT_EQUAL      {  1,  3 }
#define MATRIX_INT_BACKSLASH  {  1,  4 }
#define MATRIX_INT_SQBRACKL   {  1,  5 }
#define MATRIX_INT_SQBRACKR   {  1,  6 }
#define MATRIX_INT_SEMICOLON  {  1,  7 }
#define MATRIX_INT_QUOTE      {  2,  0 }
#define MATRIX_INT_BACKQUOTE  {  2,  1 }
#define MATRIX_INT_COMMA      {  2,  2 }
#define MATRIX_INT_DOT        {  2,  3 }
#define MATRIX_INT_DIV        {  2,  4 }
#define MATRIX_INT_DEAD       {  2,  5 }
#define MATRIX_INT_A          {  2,  6 }
#define MATRIX_INT_B          {  2,  7 }
#define MATRIX_INT_C          {  3,  0 }
#define MATRIX_INT_D          {  3,  1 }
#define MATRIX_INT_E          {  3,  2 }
#define MATRIX_INT_F          {  3,  3 }
#define MATRIX_INT_G          {  3,  4 }
#define MATRIX_INT_H          {  3,  5 }
#define MATRIX_INT_I          {  3,  6 }
#define MATRIX_INT_J          {  3,  7 }
#define MATRIX_INT_K          {  4,  0 }
#define MATRIX_INT_L          {  4,  1 }
#define MATRIX_INT_M          {  4,  2 }
#define MATRIX_INT_N          {  4,  3 }
#define MATRIX_INT_O          {  4,  4 }
#define MATRIX_INT_P          {  4,  5 }
#define MATRIX_INT_Q          {  4,  6 }
#define MATRIX_INT_R          {  4,  7 }
#define MATRIX_INT_S          {  5,  0 }
#define MATRIX_INT_T          {  5,  1 }
#define MATRIX_INT_U          {  5,  2 }
#define MATRIX_INT_V          {  5,  3 }
#define MATRIX_INT_W          {  5,  4 }
#define MATRIX_INT_X          {  5,  5 }
#define MATRIX_INT_Y          {  5,  6 }
#define MATRIX_INT_Z          {  5,  7 }
#define MATRIX_INT_SHIFT      {  6,  0 }
#define MATRIX_INT_CTRL       {  6,  1 }
#define MATRIX_INT_GRAPH      {  6,  2 }
#define MATRIX_INT_CAPSLOCK   {  6,  3 }
#define MATRIX_INT_CODE       {  6,  4 }
#define MATRIX_INT_F1         {  6,  5 }
#define MATRIX_INT_F2         {  6,  6 }
#define MATRIX_INT_F3         {  6,  7 }
#define MATRIX_INT_F4         {  7,  0 }
#define MATRIX_INT_F5         {  7,  1 }
#define MATRIX_INT_ESC        {  7,  2 }
#define MATRIX_INT_TAB        {  7,  3 }
#define MATRIX_INT_STOP       {  7,  4 }
#define MATRIX_INT_BS         {  7,  5 }
#define MATRIX_INT_SELECT     {  7,  6 }
#define MATRIX_INT_RET        {  7,  7 }
#define MATRIX_INT_SPACE      {  8,  0 }
#define MATRIX_INT_HOME       {  8,  1 }
#define MATRIX_INT_INS        {  8,  2 }
#define MATRIX_INT_DEL        {  8,  3 }
#define MATRIX_INT_LARROW     {  8,  4 }
#define MATRIX_INT_UARROW     {  8,  5 }
#define MATRIX_INT_DARROW     {  8,  6 }
#define MATRIX_INT_RARROW     {  8,  7 }
#define MATRIX_INT_NUMMULT    {  9,  0 }
#define MATRIX_INT_NUMPLUS    {  9,  1 }
#define MATRIX_INT_NUMDIV     {  9,  2 }
#define MATRIX_INT_NUM0       {  9,  3 }
#define MATRIX_INT_NUM1       {  9,  4 }
#define MATRIX_INT_NUM2       {  9,  5 }
#define MATRIX_INT_NUM3       {  9,  6 }
#define MATRIX_INT_NUM4       {  9,  7 }
#define MATRIX_INT_NUM5       { 10,  0 }
#define MATRIX_INT_NUM6       { 10,  1 }
#define MATRIX_INT_NUM7       { 10,  2 }
#define MATRIX_INT_NUM8       { 10,  3 }
#define MATRIX_INT_NUM9       { 10,  4 }
#define MATRIX_INT_NUMMINUS   { 10,  5 }
#define MATRIX_INT_NUMCOMMA   { 10,  6 }
#define MATRIX_INT_NUMDOT     { 10,  7 }

// Returns the mapping for the given scancodes
mapping map_scancodes(const PS2Scancode &sc);

#endif

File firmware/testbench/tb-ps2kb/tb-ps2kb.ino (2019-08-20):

// Artemisa Computer System
// PS2 Keyboard Adapter Testbench
// Copyright (C) 2018-2019 Alvaro Polo
//
// This is an Arduino sketch aimed to provide a testbench for the PS2 Keyboard
// Adapter board. It basically makes the Arduino simulate an Artemisa Computer
// motherboard, interacting with the adapter board as it were a real keyboard
// matrix.
//
// It works for Arduino Mega or Arduino Mega 2560 boards only.

// A flag used for deep debugging
#define DEBUG 0

// The baud rate used for the serial communication
#define SERIAL_BAUDRATE 9600

// The number of rows present in the keyboard matrix
#define NROWS     11

// The number of columns present in the keyboard matrix
#define NCOLS     8

// Pin settings for KBCOL bus lines
#define PIN_KBCOL0 2
#define PIN_KBCOL1 3
#define PIN_KBCOL2 4
#define PIN_KBCOL3 5
#define PIN_KBCOL4 6
#define PIN_KBCOL5 7
#define PIN_KBCOL6 8
#define PIN_KBCOL7 9

// Pin settings for RSL bus lines
#define PIN_RSL0    22
#define PIN_RSL1    23
#define PIN_RSL2    24
#define PIN_RSL3    25
#define PIN_RSL4    26
#define PIN_RSL5    27
#define PIN_RSL6    28
#define PIN_RSL7    29
#define PIN_RSL8    30
#define PIN_RSL9    31
#define PIN_RSL10   32

#define PIN_CAPSLOCK  11
#define PIN_KANALOCK  12
#define PIN_RESET     13


// The pins used by KBCOL bus lines
const int pins_kbcol[NCOLS] = {
  PIN_KBCOL0, PIN_KBCOL1, PIN_KBCOL2, PIN_KBCOL3,
  PIN_KBCOL4, PIN_KBCOL5, PIN_KBCOL6, PIN_KBCOL7,
};

// The pins used by RSL bus lines
const int pins_rsl[NROWS] = {
  PIN_RSL0, PIN_RSL1, PIN_RSL2, PIN_RSL3, PIN_RSL4, PIN_RSL5,
  PIN_RSL6, PIN_RSL7, PIN_RSL8, PIN_RSL9, PIN_RSL10,
};

// Setup of Arduino pins
void setupPins() {
  for (int i = 0; i < NCOLS; i++) {
    pinMode(pins_kbcol[i], INPUT_PULLUP);
  }
  for (int i = 0; i < NROWS; i++) {
    pinMode(pins_rsl[i], OUTPUT);
    digitalWrite(pins_rsl[i], HIGH); // Reverse logic
  }
  pinMode(PIN_CAPSLOCK, OUTPUT);
  pinMode(PIN_KANALOCK, OUTPUT);
  pinMode(PIN_RESET, OUTPUT);
  digitalWrite(PIN_CAPSLOCK, HIGH); // Reverse logic
  digitalWrite(PIN_KANALOCK, HIGH); // Reverse logic
  digitalWrite(PIN_RESET, HIGH); // Reverse logic
}

// Reset the PS2 Adapter board
void reset() {
  digitalWrite(PIN_RESET, LOW);
  delay(50);
  digitalWrite(PIN_RESET, HIGH);
}

// Deselect the row from the keyboard matrix
void deselectRow() {
  for (int i = 0; i < NROWS; i++) {
    digitalWrite(pins_rsl[i], HIGH);
  }
}

// Select the given row of the keyboard matrix
void selectRow(unsigned int row) {
  if (row > NROWS) {
    return;
  }
  deselectRow();
  digitalWrite(pins_rsl[row], LOW);
}

// Read the columns from the selected row
byte readRow() {
  byte col = 0;
  for (int i = 7; i >= 0; i--) {
    col <<= 1;
    col |= digitalRead(pins_kbcol[i]);
  }
  return col;
}

// Setup of the serial port
void setupSerial() {
  Serial.begin(SERIAL_BAUDRATE);
  Serial.println("PS2 Keyboard Adapter initialized");
}

// Setup the Arduino board
void setup() {
  setupPins();
  reset();
  setupSerial();
}

// The current known status of the matrix
static byte matrix_status[] = {
  0xff, 0xff, 0xff, 0xff, 0xff, 0xff, 0xff, 0xff, 0xff, 0xff, 0xff
};

// The current status of the caps lock
static bool capslock_status = false;

// The mapping from keys to symbols with lower case
const char mappingLower[] = {
  '0', '1', '2', '3', '4', '5', '6', '7',
  '8', '9', '-', '=', '\\', '[', ']', ';',
  '\'', '`', ',', '.', '/', ' ', 'a', 'b',
  'c', 'd', 'e', 'f', 'g', 'h', 'i', 'j',
  'k', 'l', 'm', 'n', 'o', 'p', 'q', 'r',
  's', 't', 'u', 'v', 'w', 'x', 'y', 'z',
};

// The mapping from keys to symbols with upper case
const char mappingUpper[] = {
  ')', '!', '@', '#', '$', '%', '^', '&',
  '*', '(', '_', '+', '|', '{', '}', ':',
  '"', '~', '<', '>', '?', ' ', 'A', 'B',
  'C', 'D', 'E', 'F', 'G', 'H', 'I', 'J',
  'K', 'L', 'M', 'N', 'O', 'P', 'Q', 'R',
  'S', 'T', 'U', 'V', 'W', 'X', 'Y', 'Z',
};

// The mapping from keys to symbols for the keypad
const char mappingKeypad[] = {
  '*', '+', '/', '0', '1', '2', '3', '4',
  '5', '6', '7', '8', '9', '-', ',', '.',
};

void processKey(unsigned int row, byte before, byte after) {
  for (int i = 0; i < NCOLS; i++) {
    if ((before & 1) == 0 && (after & 1) == 1) {
      // Key released
      if (row == 8 && i == 0) {
        // Space bar
        Serial.print(" ");
      } else if (row == 7 && i == 7) {
        // Return
        Serial.println("");
      } else if (row == 6 && i == 3) {
        // Caps lock
        capslock_status = !capslock_status;
        digitalWrite(PIN_CAPSLOCK, capslock_status ? LOW : HIGH);
      } else if (row < 6 && !(row == 2 && i == 5)) {
        // Regular key (other than DEAD)
        if (capslock_status) {
          Serial.print(mappingUpper[row * NCOLS + i]);
        } else {
          Serial.print(mappingLower[row * NCOLS + i]);
        }
      } else if (row >= 9) {
        // Keypad
        Serial.print(mappingKeypad[(row - 9) * NCOLS + i]);
      } else {
        // Unknown. Print coordinates
        Serial.print("<");
        Serial.print(row);
        Serial.print(";");
        Serial.print(i);
        Serial.print(">");
      }

    }
    before >>= 1;
    after >>= 1;
  }
}

// Main program
void loop() {
  for (int i = 0; i < NROWS; i++) {
    selectRow(i);
    byte row = readRow();
    if (matrix_status[i] != row) {
#if DEBUG == 1
      Serial.print("Detected changes in row ");
      Serial.print(i);
      Serial.print(": ");
      Serial.print(row, BIN);
      Serial.println("");
#endif

      processKey(i, matrix_status[i], row);
      matrix_status[i] = row;
    }
  }
}

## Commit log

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2018-04-16 Move the RAM design to a separated sheet
    And make room for the VDP subsheet as well.
    [ram.sch, vdp.sch]
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2018-04-21 Replace RAM devices by the right component
    [ram.sch]
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2018-04-21 Several improvements in the VDP and RAM sheets
    [ram.sch, vdp.sch]
2018-04-21 Introduce the CPU sheet
    And the z84C00 component in the library.
    [cpu.sch, ram.sch, vdp.sch]
2018-04-21 Add the address bus buffering to the CPU sheet
    [cpu.sch]
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2018-04-24 Place some hierarchical pins in the root sheet
    [artemsx.sch, ram.sch]
2018-04-24 Use DeMorgan representations for OR and AND gates
    [cpu.sch, ram.sch, vdp.sch]
2018-04-25 Connect several things from different sheets
    Now the ERC passes.
    [artemsx.sch, cpu.sch, power.sch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]
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2018-04-30 Fix some wrong directions of DATA bus
    [artemsx.sch, ppi.sch, rom.sch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]
2018-05-01 Add CLK oscillator to the CPU sheet
    Based on inverter amplifier using 74HC04. I hope it works.
    [artemsx.sch, clk.sch, components.csv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]
2018-05-02 Add a RESET circuit to the CPU sheet
    [artemsx.sch, components.csv, cpu.sch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]
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2018-05-19 Add a missing 11th row in keyboard matrix
    [components.csv, keyboard.sch]
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2018-05-24 Replace clock oscillator inverter by 4069
    [artemsx.sch, components.csv, cpu.sch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]
2018-05-25 Change some values of RESET signal generator
    [components.csv, cpu.sch]
2018-05-25 Replace U15 from HCT to HC
    Because it has buffered inputs from a CMOS level device.
    [components.csv, cpu.sch]
2018-05-25 Fix wrong GND pin of 74HC245
    [cpu.sch]
2018-05-29 Fix duplicated part name in U38
    [components.csv, psg.sch]
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2018-05-29 Remove ~IOSEL2
    This is the SEL signal for the printer. And we will not use it, at least in MKI.
    [artemsx.sch, io.sch]
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2018-05-29 Add more footprints for slot connector, and others
    Resistors, capacitors, etc.
    [cpu.sch, keyboard.sch, psg.sch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]
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2018-05-30 Convert the components file into a real CSV file
    Using commas as separators, not vertical bars.
    [components.csv]
2018-05-30 Add unused parts of U39 to the schema
    [components.csv, psg.sch]
2018-05-30 Replace handmade flipflop by 7474 part
    So we end up with just 1 7400 needed in the whole design.
    [components.csv, ppi.sch, psg.sch]
2018-05-30 Replace last 7400 by a 7408+7404
    [components.csv, psg.sch]
2018-05-30 Use a remaining 7432 to buffer external clock
    [components.csv, slots.sch]
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2018-05-30 Add a remaining 7432 as buffer for external reset
    [slots.sch]
2018-05-30 Add a remaining 7404 in clock signal line
    So we used a buffered inverter at the end of the clock generation circuit.
    [cpu.sch]
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2018-05-30 Add not-connected pins of AY-3-8910
    Because they are needed to assign the right footprint.
    [cpu.sch, psg.sch]
2018-05-30 Add a footprint for crystal oscillators
    [cpu.sch, keyboard.sch, vdp.sch]
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2018-06-01 Fix wrong pin number in 74HCT574
2018-06-01 Fix missing assignment of U44D
    [components.csv]
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2018-06-01 Remove +12/-12 power lines in slots
    It's a tradeoff we must assume.
    [keyboard.sch, power.sch, ppi.sch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]
2018-06-01 Add decoupling capacitors in the schematic
    One for each of the 44 ICs.
    [artemsx.sch, components.csv, keyboard.sch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]
2018-06-01 Add a new footprint for power jack 55/21 connector
    [power.sch]
2018-06-01 Include power connector & decoupling caps to the PCB
    [artemsx.kicad_pcb]
2018-06-01 Replace the footprint of the electrolytic caps
    And also the 3D shape.
    [artemsx.kicad_pcb]
2018-06-01 Replace the footprint of the disc capacitors
    [artemsx.kicad_pcb]
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2018-06-01 Add the schematic circuit to process the CASOUT signal
    [artemsx.sch, cassette.sch, components.csv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]
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2018-06-03 Add footprint for DIP-8 300
    And also assign other footprints from the CAS sheet.
    [cassette.sch]
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2018-06-04 Replace TMS99x8 by TMS9928/9
    Assume we will use the 28 or 29 versions.
    [vdp.sch]
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2018-10-21 Fix some wrong pin directions in GFX connectors
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2018-10-25 New repo layout for hardware definitions
    In order to share the libs from different KiCAD projects, a new directory structure is needed.
    [artemsx.kicad_pcb, artemsx.sch, cassette.sch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]
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2018-10-27 Remove VDP from motherboard
    And also fix some missing symbols
    [artemisa.sch, cassette.sch, components.csv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]
2018-10-27 Add more aesthetic power symbols
    And fix many broken resistor symbols
    [power.sch, psg.sch, ram.sch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]
2018-10-27 Combine /EXTINT and /EXTWAIT signals with AND gates
    [components.csv, cpu.sch, slots.sch]
2018-10-27 Remove unused components from PCB
    After removing VDP stuff.
    [artemisa.kicad_pcb, psg.sch, slots.sch]
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2018-10-28 Remove U44
    There were two free 7432s, so counting another 2 that were used as buffers we can remove a complete CI.
    [artemisa.kicad_pcb, components.csv, keyboard.sch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]
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2018-11-01 Make room for cartridge slots
    We need more space according to cartridge specs.
    [artemisa.kicad_pcb]
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2018-11-10 Separate PS2 connector from adjacent ICs
    And also add some informational labels to the PCB.
    [artemisa.kicad_pcb]
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2018-11-18 Fix wrong PPI address lines in schematic
    [artemisa.sch, cassette.sch, cpu.sch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]
2018-11-18 Fix wrong PPI address lines in PCB
    [artemisa.kicad_pcb]
2018-11-22 Add missing components to the list
    [components.csv]
2018-11-22 Move /RESET signal generation into POWER sheet
    [artemisa.sch, cassette.sch, components.csv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]
2018-11-22 Move RESET signal general into POWER sheet
    [artemisa.kicad_pcb, artemisa.sch, components.csv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]
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2018-11-26 Move PSG decoding logic to DECODING sheet
    And also improve the decoding function to avoid inconsistency port access.
    [artemisa.sch, decoding.sch, psg.sch]
2018-11-26 Adequate PCB to redefinition of PSG decoding logic
    [artemisa.kicad_pcb]
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2018-11-26 Move IO device selection signal decoding to DECODING sheet
    [artemisa.kicad_pcb, artemisa.sch, cassette.sch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]
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2019-03-22 Fix power pin arrangement in GFX9918
    For discrete logic symbols, add a new one to represent the power connections. So we can represent them in the schematic explicitely.
    This also fixes the different format in capacitor values.
    [gfx-9918.kicad_pcb, gfx-9918.sch]
2019-03-23 Fix power pin arrangement for NOT and AND gates in motherboard
    [artemisa.kicad_pcb, artemisa.sch, cassette.sch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]
2019-03-23 Fix power in arrangement for 74HC08
    [artemisa.kicad_pcb, power.sch]
2019-03-23 Fix power pin arrangement for 74HC139
    [artemisa.kicad_pcb, power.sch]
2019-03-23 Fix power pin arrangement for 74HC244
    [power.sch]
2019-03-24 Fix power pin arrangement for 74HC245
    [artemisa.kicad_pcb, cpu.sch, power.sch]
2019-03-24 Fix power in arrangement for 74HC07
    [artemisa.kicad_pcb, power.sch]
2019-03-24 Fix ower pin arrangement for 74HC138
    [artemisa.kicad_pcb, decoding.sch, power.sch]
2019-03-24 Fix power pin arrangement for 74HC74
    [artemisa.kicad_pcb, decoding.sch, power.sch]
2019-03-24 Fix power pin arrangement for 74HC153
    [artemisa.kicad_pcb, power.sch, ppi.sch]
2019-03-24 Fix power pin arrangement for PPI
    [artemisa.kicad_pcb, power.sch, ppi.sch]
2019-03-24 Fix power pin arrangement for 74HC595
    [artemisa.kicad_pcb, keyboard.sch, power.sch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]
2019-03-24 Fix power pin arrangement for 74HC154
    [keyboard.sch, power.sch]
2019-03-24 Fix power pin arrangement for ATMega328
    [keyboard.sch, power.sch]
2019-03-24 Fix power pin arrangement for 74HC11
    [artemisa.kicad_pcb, keyboard.sch, power.sch]
2019-03-24 Some fixes in power arrangement
    [power.sch, psg.sch]
2019-03-24 Fix power pin arrangement for PSG
    [power.sch, psg.sch]
2019-03-24 Fix power pin arrangement for 74HC157
    [power.sch, psg.sch]
2019-03-24 Fix power pin arrangement for ROM
    [power.sch, rom.sch]
2019-03-24 Fix power pin arrangement for RAM
    [power.sch, ram.sch, rom.sch]
2019-03-24 Fix power pin arrangement for LM311
    [artemisa.kicad_pcb, clock.sch, power.sch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]
2019-03-24 Fix power pin arrangement for Z80
    [artemisa.kicad_pcb, clock.sch, cpu.sch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]
2019-03-24 Fix wrong pin layout of RCA connector footprints
    [gfx-9918.kicad_pcb]
2019-03-25 Fix missing footprint 3D models
    Even add a custom one for the MSX slot connector.
    [artemisa.kicad_pcb, gfx-9918.kicad_pcb]
2019-04-03 Replace 4069 by 74HCU04
    The 4069 has a really large response time. This causes a really ugly clock signal when used in the crystal circuit. 74HCU04 is also a unbuffered inverter, and therefore can be used also for crystal circuits. But the response time is quite faster.
    [artemisa.kicad_pcb, clock.sch, power.sch]
2019-04-08 Replace some pull-up resistors by resistor networks
    Prior to add more pull-up resitors, we realised we were using regular
    resistors instead of resistor networks. This change introduces the
    use of networks by:
    - Defining schematic symbols for networks of 4, 6 and 8 resistors
    - Add the corresponding PCB footprints and 3D models
    - Replace the regular resistors by networks
    - Update the PCB accordingly
    [artemisa.kicad_pcb, components.csv, power.sch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]
2019-04-10 Add pull-up resistors for KBCOL bus
    This is needed because the KBROW might be selecting a unexisting row. In such case, none of the 595s will be selected, and the bus will be floating.
    [artemisa.kicad_pcb, keyboard.sch, ppi.sch]
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2019-04-17 Add pins for optional pin header in DB25 footprints
    We might want to use an internal connection to a pin header of 100millis instead of the DB25 connector. So we have included additional pins to sold such pin header instead of DB25 header.
    [keyboard-ps2.kicad_pcb]
2019-04-17 Replace keyboard matrix emulation in motherboard schematic
    Bye, bye, emulator.
    [artemisa.sch, keyboard.sch, ppi.sch]
2019-04-17 Add KANALOCK signals to keyboard connectors
    Still not used from the motherboard (wired to 5v).
    [artemisa.sch, keyboard-ps2.kicad_pcb, keyboard-ps2.sch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]
2019-04-17 Add a 7407 to CAPSLOCK led in motherboard schematics
    The open-collector buffer will decouple the PPI circuit from the capslock LED. This is important if a real LED is used by the keyboard (which might sink ~20mA).
    [keyboard.sch, psg.sch]
2019-04-17 Replace keyboard matrix emulation in motherboard PCB
    [artemisa.kicad_pcb, clock.sch, keyboard.sch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]
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2019-04-21 Fix DB25 connector of keyboard PS2 PCB
    So it stands out from the board.
    [keyboard-ps2.kicad_pcb]
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2019-04-30 Reset annotations in the motherboard
    So we stop having gaps in the IDs. Also, remove the `components.csv` file, hard to keep updated and susceptible to be autogenerated.
    [artemisa.kicad_pcb, cassette.sch, clock.sch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]
2019-05-07 Fix board dimensions and plot rev01 of motherboard
    [artemisa.kicad_pcb]
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2019-05-21 Shorten the DB25 footprints
2019-05-21 Shorten the PCB and the DB25 connector in PS2 Adapter
    [keyboard-ps2.kicad_pcb]
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2019-05-27 Fix broken code due to PROGMEM in ps2kbr firmware
    [ps2kbr.ino]
2019-05-29 Fix wrong debugging message
    [ps2kbr.ino]
2019-06-14 Fix power-on reset circuit
    Following the same design as in the Philips VG8020.
    [artemisa.kicad_pcb, cassette.sch, clock.sch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]
2019-06-14 Fix sizes of 1N4448 diode symbols
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2019-06-14 Add a diode in the power-on reset circuit
    So the capacitor that generates the reset signal is discharged quickly on power off.
    [artemisa.kicad_pcb, cassette.sch, clock.sch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]
2019-06-14 Fix misplaced silkscreen legends
    And fix also some sizes
    [artemisa.kicad_pcb]
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2019-06-20 Add more +5V connections to the circuit
    To improve the surface of the +5v layer and reduce the voltage drops.
    [artemisa.kicad_pcb]
2019-06-20 Hardcode JP keyboard layout to JIS
    By pulling-up the IOA6 pin of the PSG.
    [artemisa.kicad_pcb, psg.sch]
2019-07-02 Fix wrong slot connector placement
    The pinout was reversed, and they were placed in such a way that screw separators cannot be inserted.
    [artemisa.kicad_pcb]
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2019-07-03 Fix wrong label sizes in diode footprints
2019-07-04 Replace NPN by PNP in Q2
    We need reverse logic here.
    [artemisa.kicad_pcb, cassette.sch]
2019-07-04 Use 2.2K instead of 4.7K in R13
    4.7 is too large, and it will not saturate Q2.
    [artemisa.kicad_pcb, cassette.sch]
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2019-07-04 Add a push button for reset
    [artemisa.kicad_pcb, power.sch]
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2019-08-12 Replace 74HC154 by a pair of 74HC138
    [artemisa.kicad_pcb, cassette.sch, clock.sch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]
2019-08-14 Add missing changes from issues/104
    [keyboard.sch]
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2019-08-14 Replace 7411 by 7408 for U18 in schematic
    [power.sch, slots.sch]
2019-08-14 Rearrange connections from U18 to RN3
    So the pins are aligned in the PCB
    [slots.sch]
2019-08-14 Replace 7411 by 7408 for U18 in PCB
    [artemisa.kicad_pcb]
2019-08-14 Fix wrong text sizes in power schematic
    [power.sch]
2019-08-20 Fix wrong mapping of some symbol keys
    [mapping.h]
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2019-09-04 [motherboard] Fix capacitor values for clock circuit
    [artemisa.kicad_pcb, artemisa.sch, clock.sch]
2019-09-04 [ps2-adapter] Fix capacitor values for clock circuit
    [keyboard-ps2.kicad_pcb, keyboard-ps2.sch]
2019-09-04 [gfx9918] Fix missing symbol HM62256
    [gfx-9918.sch]
2019-09-04 [gfx9918] Fix capacitor values for clock circuit
    [gfx-9918.kicad_pcb, gfx-9918.sch]
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2019-09-10 Fix dimensions of slot connector footprint
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2019-09-10 [motherboard] Fix wrong annular ring size of cartridge slot connectors
    [artemisa.kicad_pcb]
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2019-09-11 [ps2-adapter] Fix dimensions of case to fit PCB
    [ps2-adapter.dxf]
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2019-09-14 Add combined case designs
    A combined design includes motherboard and PS2 adapter designs in the same DXF so they are laser cutted togheter.
    [combined-ctrlx-full.dxf]
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2019-11-11 Fix background color issues by unconnecting EXTVDP pin
    [gfx-9918.kicad_pcb, gfx-9918.sch]
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2019-12-09 Make it more resilient to parity errors
    [ps2.cpp, ps2kbr.ino]
2020-01-15 Reduce the speed of serial comms
    When using prototype wires, this causes some rx errors.
    [ps2kbr.ino]
2020-01-15 Distinguish 0x00 and 0xff errors and handle them
    [ps2kbr.ino]
2020-03-02 Add buffers for comms received from keyboard
    It seems we cannot inhibit the comms, because this causes buffer overrun
    errors in the device. With this change, the microcontroller uses a
    ring buffer to store already processed scancodes. And the application
    layer reads from there.
    [mapping.h, ps2.cpp, ps2kbr.ino]
2020-03-07 Fix some timing issues of PS2 protocol
    [ps2.cpp]
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2020-03-10 Fix how resend command is processed
    [ps2.cpp]
2020-03-11 Replace command structs by a simple buffer
    [ps2.cpp, ps2kbr.ino]
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2020-05-19 Replace clock circuit by an encapsulated oscillator SG7050
    [clock.sch, motherboard-201.kicad_pcb]
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2020-05-20 Replace the custom power-on reset circuit by TL7705
    [motherboard-201.kicad_pcb, power.sch]
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2020-05-20 Use ceramic capacitor for C15We actually have access to 1nF values in SMD encapsulation.
    [motherboard-201.kicad_pcb, power.sch]
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2020-05-21 Replace logic gates by a GAL in decoding logic
    [decoding.sch, motherboard-201.kicad_pcb, power.sch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]
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

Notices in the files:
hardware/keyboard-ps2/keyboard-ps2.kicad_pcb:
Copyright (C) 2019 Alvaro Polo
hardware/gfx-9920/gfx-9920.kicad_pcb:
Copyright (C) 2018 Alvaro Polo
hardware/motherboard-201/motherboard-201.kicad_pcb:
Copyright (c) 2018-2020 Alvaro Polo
